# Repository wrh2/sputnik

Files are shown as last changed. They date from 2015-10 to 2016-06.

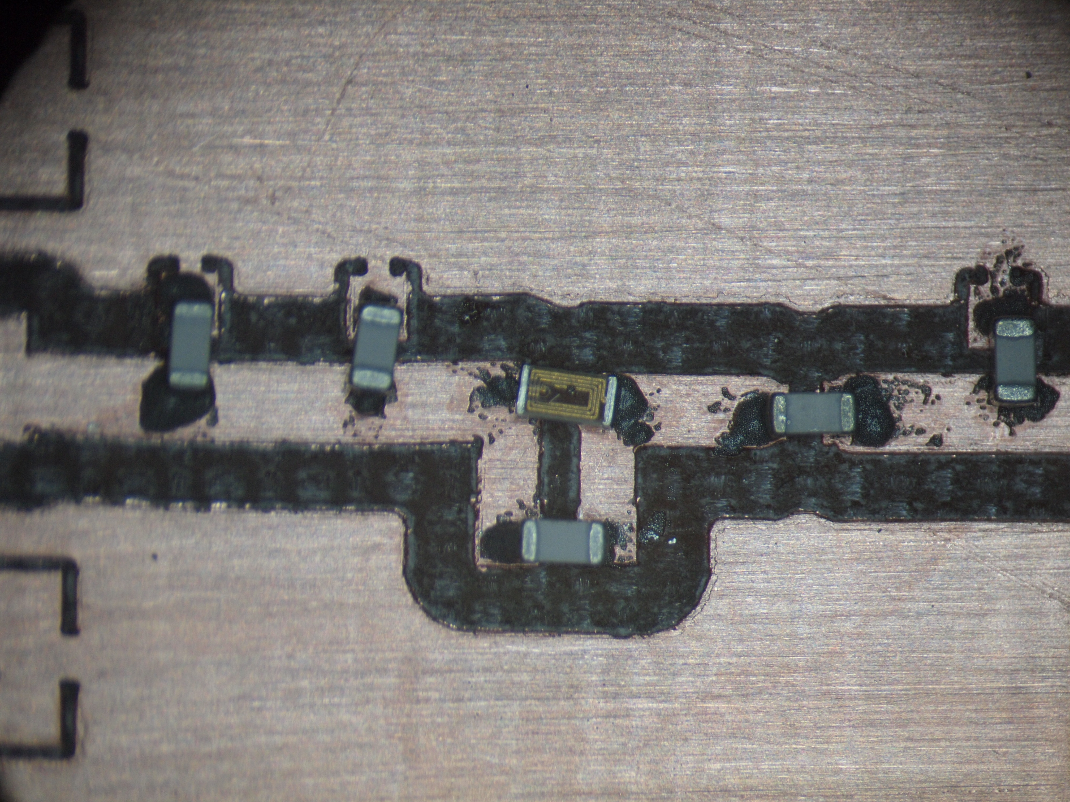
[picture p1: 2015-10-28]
RF_Materials/Antenna_Filters/prototype_photos/PA210078.JPG

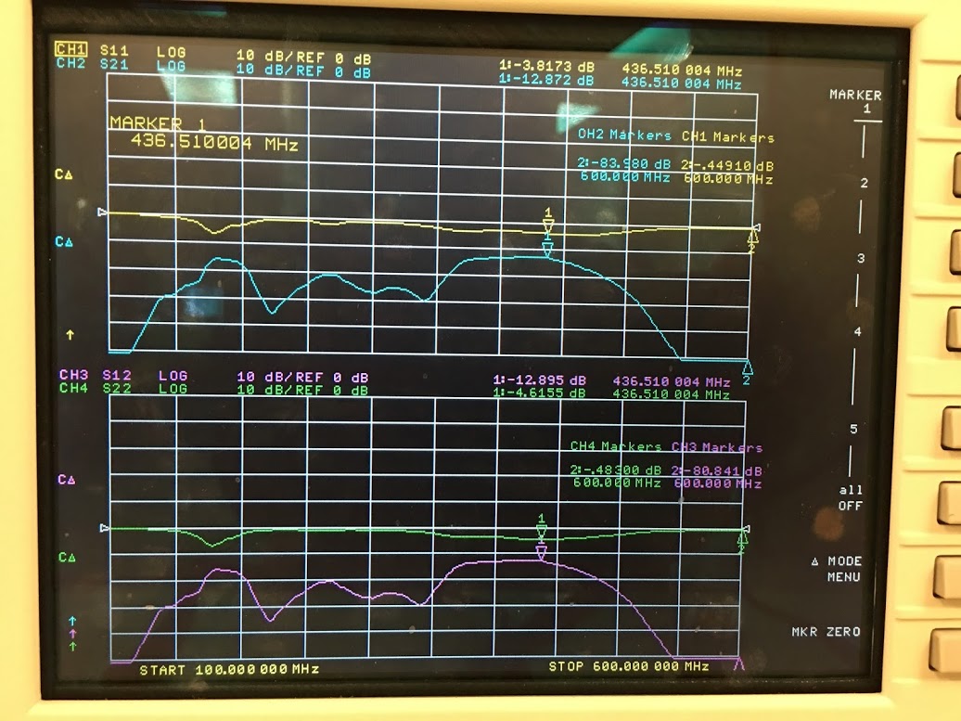
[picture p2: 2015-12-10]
RF_Materials/Antenna_Filters/AntennaTest.jpg

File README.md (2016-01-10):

# C3/Sputnik module

Project repo for Portland State Aerospace Society C3/Sputnik module project. Click [here] (https://github.com/wrh2/sputnik/wiki) for project details.

## Project Team
Jake Heath (jakeheath@gmail.com)

William Harrington (wrh2@pdx.edu)

Shan Quinney (quinney@pdx.edu)

Mike Mathis (mdmathis@gmail.com)

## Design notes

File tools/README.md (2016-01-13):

# Tools

This folder contains resources for the toolchain we are using for programming the Freescale/NXP MKW01Z128 microcontroller. For an in-depth explanation on the toolchain, [please see this wiki page](https://github.com/wrh2/sputnik/wiki/MKW01Z128-toolchain).

## Dependencies

[OpenOCD](http://openocd.org)

[GCC ARM Embedded](https://launchpad.net/gcc-arm-embedded)

## Contents

**Folders**
* drivers -- contains peripherial drivers that we've developed so far for the MKW01Z128
* examples -- contains some simple example code for using the microcontroller (MKW01Z128) on the breakout board
* toolchain -- contains linker script, config for OpenOCD

**Files**
* c3.c -- some really simple c code to inject into the microcontroller
* crt0.c -- stuff needed to initialize the MCU
* kw0x.h -- register definitions, needed for bit banging
* Makefile -- make utility for easy compiling

## Example usage

* To compile

        > make

* To compile and write to the flash on the MCU

        > make write

* To compile, write to the flash on the MCU, and start up a gdb session

        > make gdb

* To clean up

        > make clean

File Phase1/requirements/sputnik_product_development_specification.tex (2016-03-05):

\documentclass[12pt]{article}
\usepackage{amsmath}
\usepackage{amssymb}
\usepackage{graphicx}
\usepackage{tabulary}

\begin{document}

\title{Sputnik Product Development Specification}%replace X with the appropriate number
\author{William Harrington, Jake Heath, Shan Quinney, Michael Mathis\\ \\ %replace with your name
ECE412 Capstone} %if necessary, replace with your course title

\maketitle
 \small
\begin{description}
	\item[Requirements] \hfill \\ \\
		\textbf{Must}
		\begin{itemize}
			\item Environment
			\begin{itemize}
				\item Have a radiation tolerant watchdog system
				\item Be able to operate in an Industrial Operating Temperature Range (-40°C to 80°C)
				\item Acceleration: must handle 15g in the "Z" axis
			\end{itemize}
			\item Communication block ("radio")
			\begin{itemize}
				\item Operate in the 70 cm band (436 to 438 MHz)
				\begin{itemize}
					\item Use IARU specified frequency for RF comms and make appropriate changes if necessary
				\end{itemize}
				\item Meet FCC Amateur Radio Licensing requirements (Title 47 CFR part 97)
				\item Meet 400km ISS orbit link budget by a margin of 6 dB
				\item Have bidirectional communication interface to Payload and System Controller
				\item Local storage for communication in/out queues
			\end{itemize}
			\item Energy Switching/Control
			\begin{itemize}
				\item Be able to seamlessly switch energy sources to the load
			\end{itemize}
			\item System controller
			\begin{itemize}
				\item Radiation tolerant "system watchdog" controller
				\item Power switches to turn other blocks on and off
				\item Monitor energy storage and energy harvesting systems
				\item Communication link with communication block
			\end{itemize}
			\item CubeSat requirements
			\begin{itemize}
				\item Conforms to latest CubeSat specification where applicable
				\item Fits in 1/4 1U CubeSat
				\item Weighs less than 250 g
			\end{itemize}
		\end{itemize}
		\textbf{Should}
		\begin{itemize}
			\item{In general}
			\begin{itemize}
				\item Use as many COTS (Commercial Off The Shelf) parts as possible
			\end{itemize}
			\item Environment
			\begin{itemize}
				\item Operate in Automotive Operating Temperature Range (-40C to 125C)
			\end{itemize}
			\item Communication block ("radio")
			\begin{itemize}
				\item Use a frequency of 436.5 MHz for RF communication
			\end{itemize}
		\end{itemize}
	
		\textbf{May}
		\begin{itemize}
			\item Environment
			\begin{itemize}
				\item Operate in Military Operating Temperature Range (-55°C to 125°C)
			\end{itemize}
		\end{itemize}
	\newpage
	\item[Deliverables] \hfill \\
		\begin{itemize}
			\item Hardware
			\begin{itemize}
				\item 2 fully working Sputnik boards in the CubeSat 0 form factor (determined by PSAS)
				\item UART to Sputnik radio adapter for test/debug
			\end{itemize}
			\item Firmware
			\begin{itemize}
				\item Basic Sputnik functionality for KW0x microcontroller
				\item Drivers
				\begin{itemize}
					\item Timers and Interrupts
					\item SPI
					\item UART
					\item Radio (600 kbps bi-directional communication using GFSK)
				\end{itemize}
				\item System Controller
				\begin{itemize}
					\item Simple monitoring of power system
					\item Simple watchdog system to turn on and off other system blocks
				\end{itemize}
			\end{itemize}
			\item System Level
			\begin{itemize}
				\item Radio works: 600 kbps bi-directional communication, using GFSK demonstrated over 10 km
				\item System controller can turn other blocks on and off
			\end{itemize}
		\end{itemize}
\end{description}
\end{document}

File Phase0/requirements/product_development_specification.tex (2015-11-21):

\documentclass[12pt]{article}
\usepackage{amsmath}
\usepackage{amssymb}
\usepackage{graphicx}
\usepackage{tabulary}

\begin{document}

\title{Product Development Specification}%replace X with the appropriate number
\author{Team 05\\William Harrington, Jake Heath, Saroj Bardewa,\\ Shan Quinney, Michael Mathis\\ \\ %replace with your name
ECE411} %if necessary, replace with your course title

\maketitle
 \small
\begin{description}
	\item[Customer requirements] \hfill \\ \\
		The Portland State Aerospace Society (PSAS) needs a device that can be used for command, control, communications between a \textbf{CubeSat} and a \textbf{ground station}.
		A \textbf{CubeSat} is a miniature satellite that can be used for scientific research in space. It has a volume of one liter (10cm cube), and has a mass of no more than 1.33kg.
		A \textbf{ground station} is a radio station located on earth that is designed for communication with spacecraft.
		Development of such a device is not trivial as it will need to eventually be "space ready" (for example being able to operate in -30C to 150C temperature ranges and withstand ionizing radiation from space environment)  and will require multiple phases of development. \hfill \\ \\
		The first phase of development will involve finding and de-risking a microcontroller that is capable of handling command, control, and communications.
		Therefore, the device will be a communications module "breakout board" that will allow easy access to the features of the microcontroller like UART, I2C, SPI, GPIO, ADCs/DACs, etc. Access to these features will rely on miscellaneous connectors such as .1 inch pin headers, USB, 6-pin JTAG, etc. Furthermore, as a project that is sponsored by PSAS it should adhere to their open source standards, while obeying governmental regulations.
		\hfill \\ \\
		\newpage
	\item[Requirements] \hfill \\
		\textbf{Must}
		\begin{itemize}
			\item{Have a transceiver for RF communications}
      			\item{Have an antenna capable of 435 - 438MHz frequency band transmission}
			\item{Have visible indication of communication \textit{(such as LEDs)}}
			\item{Have a bidirectional amplifier for RF communication}
			\item{Be able to fit within the CubeSat form factor\\ \textit{(no bigger than 10cm x 10cm x 10cm)}}
			\item{Be a breakout board}
			\item{Have access to UART}
			\item{Have access to I2C}
			\item{Have access to SPI}
			\item{Have access to GPIO}
			\item{Have access to ADCs/DACs}
		\end{itemize}
		\textbf{Should}
		\begin{itemize}
			\item{Use USB for interfacing}
			\item{Be able to send/receive data packets via RF communication}
			\item{Be capable of RF communication at a distances greater than 6 feet}
			\item{Be battery powered (as opposed to using lab power supplies) }
			\item{If battery powered, utilize USB for recharging}
			\item{Comply with European Telecommunications Standard Institute(ETSI) and Federal Communications Commission (FCC) regulatory requirements}
			\item{Use a GNU GPL v3 license for all design work and software} 
		\end{itemize}
		\textbf{May}
		\begin{itemize}
			\item{Be capable of long distance communication \textit{(250m-500m for example)}}
			\item{Be capable of sending/receiving data packets}
			\item{Be capable of operation in space temperature range \textit{(-30C to 60C )}}
			\item{Comply with Federal Aviation Administration (FAA) regulatory requirements}
		\end{itemize}
\end{description}

\end{document}

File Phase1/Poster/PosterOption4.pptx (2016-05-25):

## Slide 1

CubeSat Command Control and
Communications System

Introduction

Project Team:
Will Harrington
Jake Heath
Michael Mathis
Shan Quinney

Special Thanks to:
Andrew Greenberg Theo
Glenn Dr. Teuscher
PSAS The LID

Development

Development of the Sputnik project began last year during our practicum. We created a specialized breakout board for the microcontroller with the integrated radio. Having this initial board allowed the firmware team to begin work earlier. We were also able to de-risk some of the components that we used in the final product.
Part of that de-risking process was creating proto-boards. These are small and specific boards built for the sole purpose of testing the major sub-systems of Sputnik. The proto-boards were custom made and tested in the Laboratory for Interconnected Devices (LID) by the hardware team.
One of the most time consuming tasks the hardware team faced was part selection because hey had to find parts that had equivalent radiation hardened counter parts

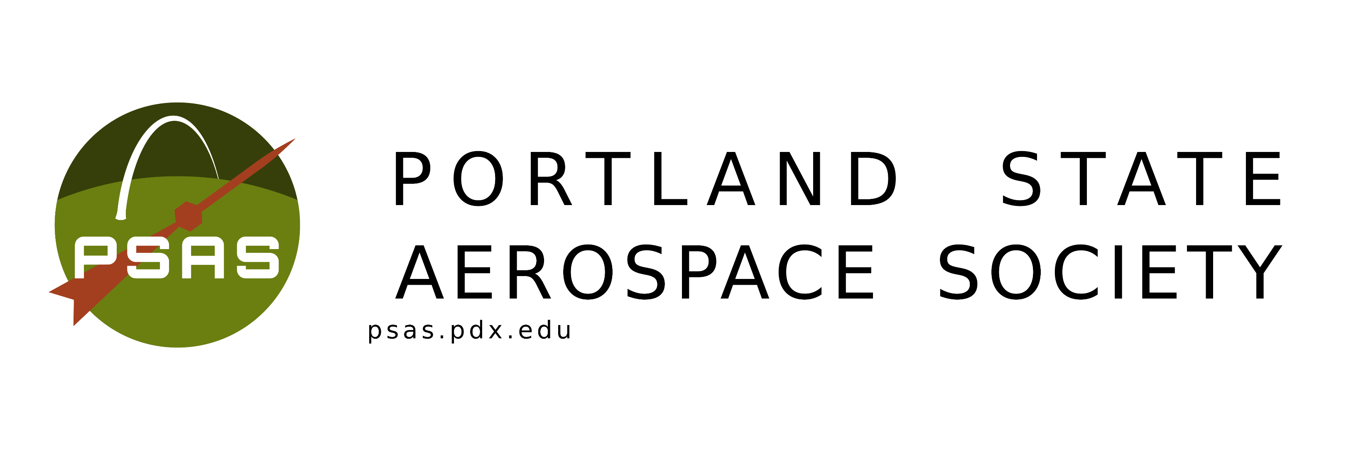
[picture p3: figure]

Results

In the end we were able to produce working prototypes that have been tested to our sponsor’s specifications and we provided our sponsor with the documentation necessary to bring future Sputnik teams up to speed.
Our final boards contained a total of 180 individual components, 108 for the LGR and 72 for SysCon.
10km TEST RESULTS
QUOTE FROM ANDREW ABOUT HOW AWESOME WE ARE MAYBE

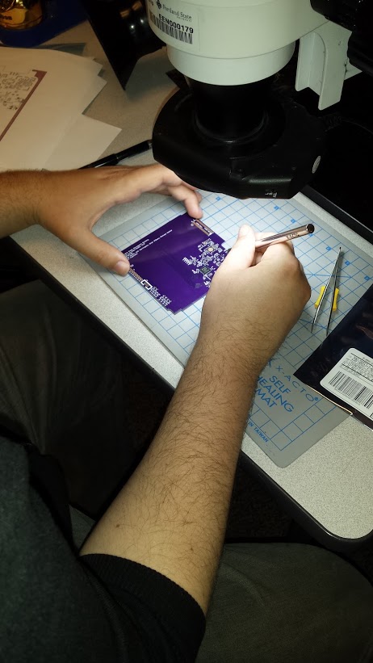
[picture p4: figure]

Jake Heath working on an LGR module

Design

The Sputnik project is composed of two separate modules: the low-gain radio module (LGR) and the system control module (SysCon). The radio module is home to a microcontroller with an integrated radio transceiver. The system controller module will house a radiation hardened watchdog microcontroller that can reboot the payload and the radio module after a radiation event causes components to fail. The prototype we are making will use off-the-shelf parts that have radiation hardened analogues so that when the time comes to build the final boards the off-the-shelf parts can be swapped out for the more robust components. This saves money during this early development stage

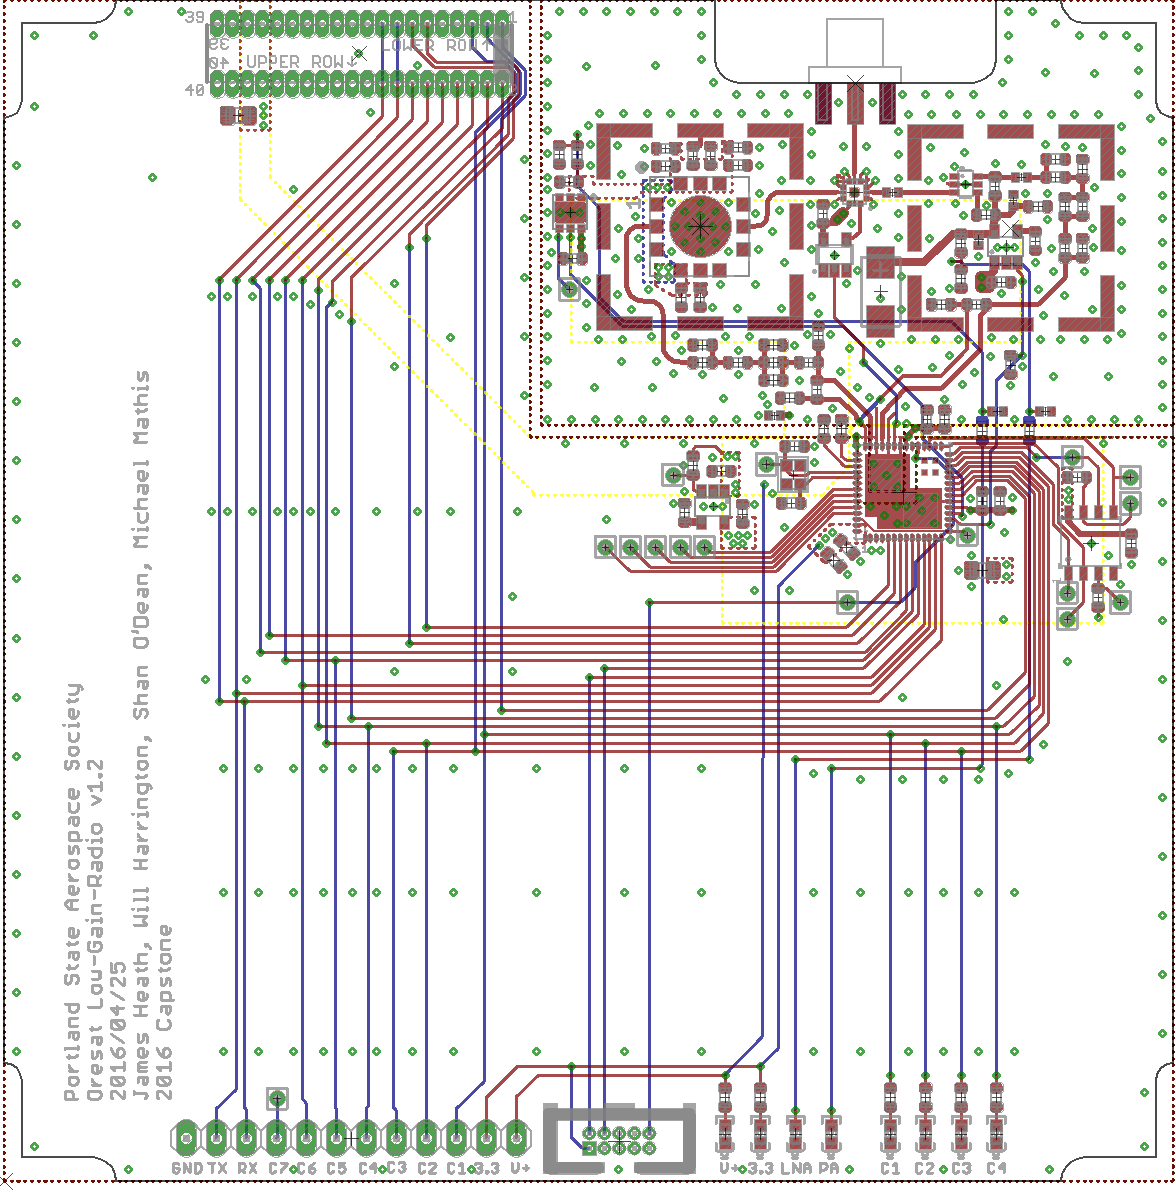
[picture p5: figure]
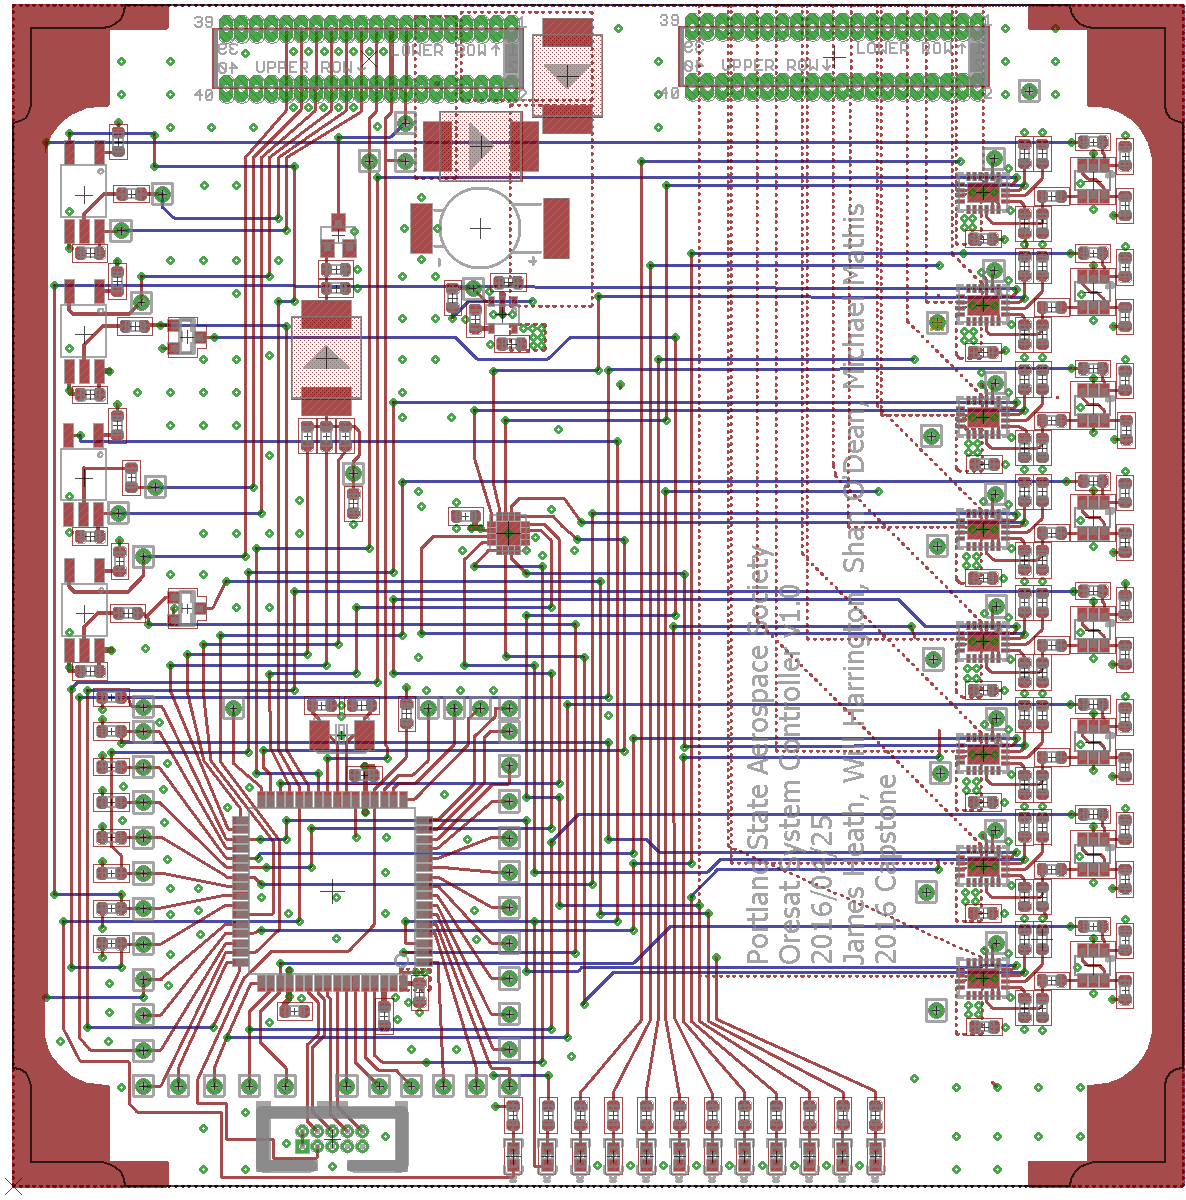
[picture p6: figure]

The final board layouts for the LGR (left) and the SysCon (right)

Spectrum analyzer
screenshot

Picture of us doing
the 10km test

Graph showing SOMETHING HARDWARY (left)
Picture of MEMBERS OF TEAM performing a 10km communications test (right)

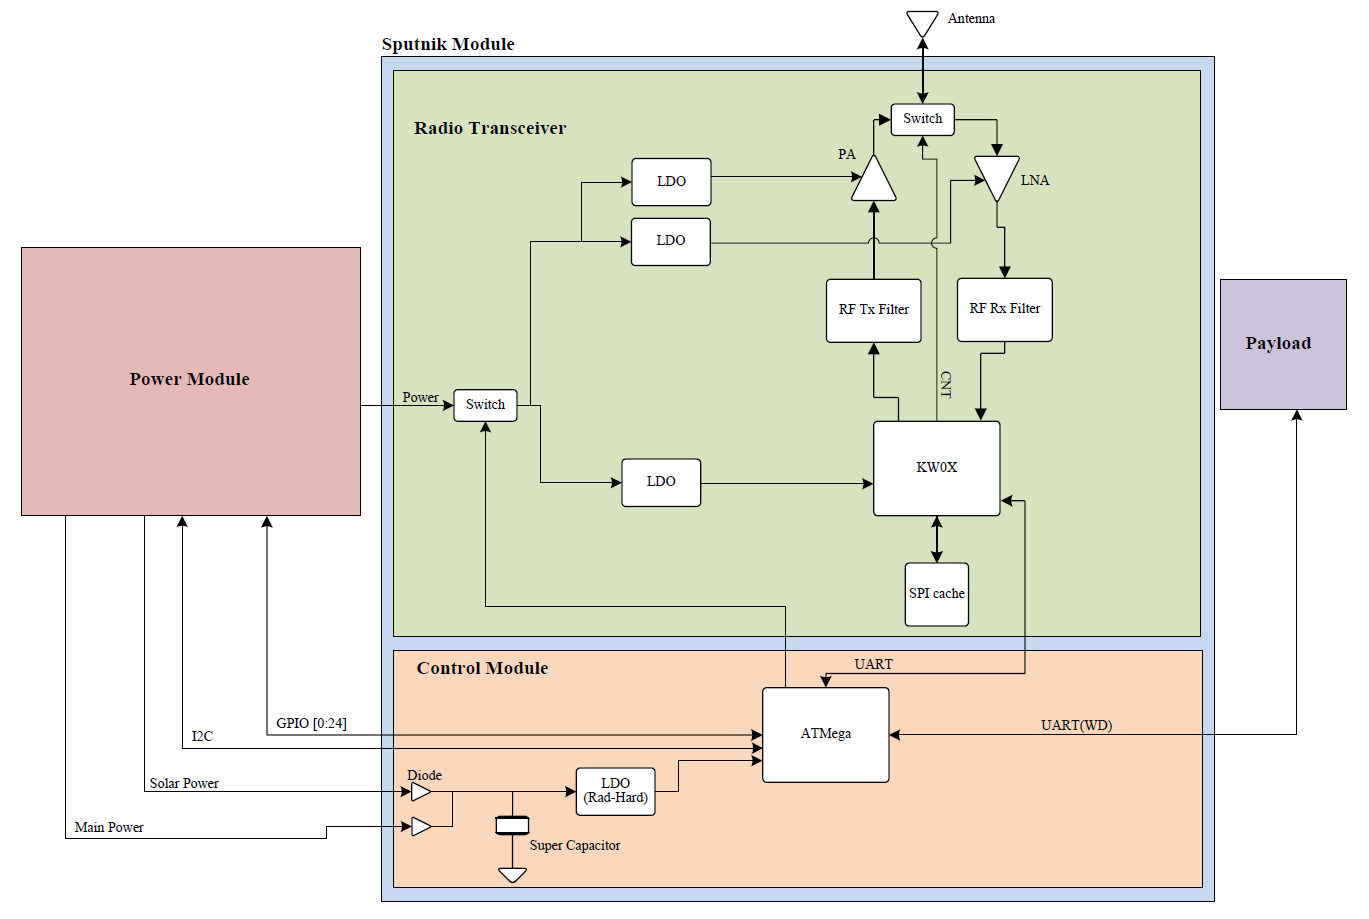
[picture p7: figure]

Block diagram of the Sputnik project

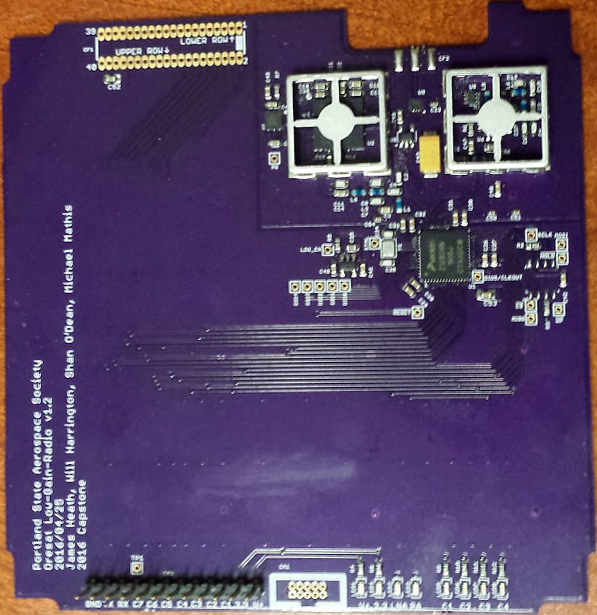
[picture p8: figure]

Firmware started with building up a complete toolchain that could be used for bare metal programming. Another challenge that firmware faced was that the integrated radio module is connected to the LGR microcontroller through a SPI interface even though they are both on the same IC. Furthermore, the microcontroller receives its main clock signal from the transceiver. This means that to get the microcontroller to work, it needed to start up with an internal oscillator then instruct the transceiver to output the appropriate clock signal and then change the clock source of the microcontroller to the transceiver.
PSAS wanted a basic code base that future contributors could use to get up and running on the project as quickly as possible so user-friendliness and good documentation were key in our development.

Department of Electrical and Computer Engineering

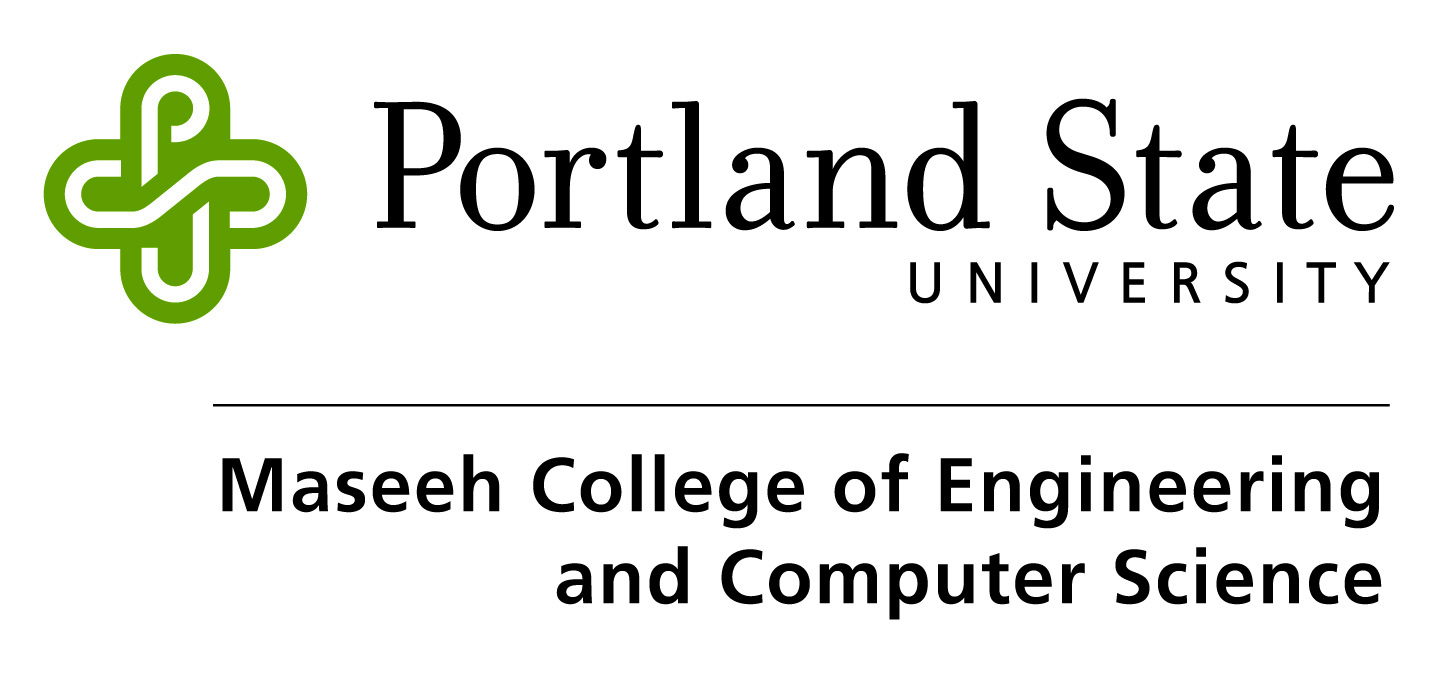
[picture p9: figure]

Pictures of the finished boards LGR (left) and SysCon (right)

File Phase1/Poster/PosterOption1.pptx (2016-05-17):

## CubeSat Command Control and Communications System

Introduction

Small educational satellites called CubeSats have been launched by dozens of universities and countries around the world, but so far Oregon has yet to join the elite club of states that have flown a home-grown CubeSat in space. The Portland State Aerospace Society (PSAS) would like to change that! PSAS has included several other Oregon schools in the ORESAT project to build a CubeSat and send it into orbit. Two NASA programs make that possible, the NASA CubeSat Launch Initiative and NASA’s Educational Launch of Nanosatellites program.
PSAS needed a command, control, and communications system for the CubeSat project. The project was fondly nicknamed Sputnik because it doesn’t have sensors, but has a radio. Sputnik will eventually be responsible for communications to and from a 400km low earth orbit. It will retrieve scientific data from the CubeSat’s payload of sensor modules and send the data back to earth. Sputnik will also relay commands like “Take a picture” or “Turn around”. In space it will need to be able to deal with a temperature range of -40C to 85C and radiation events that could cause components to latch up and cause shorts.

Project Team:
Will Harrington
Jake Heath
Michael Mathis
Shan Quinney

Special thanks to:
Andrew Greenberg
Theo
Glenn
Dr. Teuscher
PSAS
The LID


Results

In the end we were able to produce working prototypes that have been tested to our sponsor’s specifications and we provided our sponsor with the documentation necessary to bring future Sputnik teams up to speed.
Our final boards contained a total of 180 individual components, 108 for the LGR and 72 for SysCon.
10km TEST RESULTS
QUOTE FROM ANDREW ABOUT HOW AWESOME WE ARE MAYBE

Development

Development of the Sputnik project began last year during our practicum. We created a specialized breakout board for the microcontroller with the integrated radio. Having this initial board allowed the firmware team to begin work earlier. We were also able to de-risk some of the components that we used in the final product.
Part of that de-risking process was creating proto-boards. These are small and specific boards built for the sole purpose of testing the major sub-systems of Sputnik. The proto-boards were custom made and tested in the Laboratory for Interconnected Devices (LID) by the hardware team.
One of the most time consuming tasks the hardware team faced was part selection because hey had to find parts that had equivalent radiation hardened counter parts


Jake Heath working on an LGR module

Design

The Sputnik project is composed of two separate modules: the low-gain radio module (LGR) and the system control module (SysCon). The radio module is home to a microcontroller with an integrated radio transceiver. The system controller module will house a radiation hardened watchdog microcontroller that can reboot the payload and the radio module after a radiation event causes components to fail. The prototype we are making will use off-the-shelf parts that have radiation hardened analogues so that when the time comes to build the final boards the off-the-shelf parts can be swapped out for the more robust components. This saves money during this early development stage


The final board layouts for the LGR (left) and the SysCon (right)

Spectrum analyzer
screenshot

Picture of us doing
the 10km test

Graph showing SOMETHING HARDWARY (left)
Picture of MEMBERS OF TEAM performing a 10km communications test (right)


Block diagram of the Sputnik project


Firmware started with building up a complete toolchain that could be used for bare metal programming. Another challenge that firmware faced was that the integrated radio module is connected to the LGR microcontroller through a SPI interface even though they are both on the same IC. Furthermore, the microcontroller receives its main clock signal from the transceiver. This means that to get the microcontroller to work, it needed to start up with an internal oscillator then instruct the transceiver to output the appropriate clock signal and then change the clock source of the microcontroller to the transceiver.
PSAS wanted a basic code base that future contributors could use to get up and running on the project as quickly as possible so user-friendliness and good documentation were key in our development.

Department of Electrical and Computer Engineering


Pictures of the finished boards LGR (left) and SysCon (right)

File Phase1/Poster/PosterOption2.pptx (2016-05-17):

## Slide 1

CubeSat Command Control and
Communications System

Introduction

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

Project Team:
Will Harrington
Jake Heath
Michael Mathis
Shan Quinney

Special Thanks to:
Andrew Greenberg Theo
Glenn Dr. Teuscher
PSAS The LID

Development

PSAS wanted a basic code base that future contributors could use to get up and running on the project as quickly as possible so user-friendliness and good documentation were key.
Development of the Sputnik project began last year during our practicum. We created a specialized breakout board for the microcontroller with the integrated radio. Having this initial board allowed the firmware team to begin work earlier. We were also able to de-risk some of the components that we used in the final product.


The firmware team programmed Sputnik to check for errors caused by radiation or bugs. The LGR module sends an “I’m alive” signal to the SysCon periodically. If the SysCon doesn’t receive the signal in time, it performs a reset on the LGR. The SysCon module will also listen in via i2c to the payload and to the power system and reset those systems as needed.
They also wrote drivers for the essential peripherals of the microcontrollers and programmed the tricky configuration of the LGR’s microcontroller and transceiver.

Results

In the end we were able to produce working prototypes that have been tested to our sponsor’s specifications and we provided our sponsor with the documentation necessary to bring future Sputnik teams up to speed on the project.
Our final boards contained a total of 180 individual components, 108 for the LGR and 72 for SysCon.
10km TEST RESULTS
QUOTE FROM ANDREW ABOUT HOW AWESOME WE ARE MAYBE

The final board layouts for the LGR (left) and the SysCon (right)


The hardware team also spent extra time researching part because hey had to find components that had equivalent radiation hardened counter parts.
Part of that de-risking process was creating proto-boards. These are small and specific boards built for the sole purpose of testing the major sub-systems of Sputnik. The proto-boards were custom made and tested in the Laboratory for Interconnected Devices (LID) by the hardware team.

UPDATE WITH HOW THE BUILDING OF THE BOARDS GOES

Design

The Sputnik project is composed of two separate modules: the low-gain radio module (LGR) and the system control module (SysCon). The LGR module is home to a microcontroller with an integrated radio transceiver. The system controller module will house a radiation hardened watchdog microcontroller that can reboot the payload and the radio module after a radiation event or other error causes systems to fail.
The prototype we are making will use off-the-shelf parts that have radiation hardened analogues so that when the time comes to build the final boards the off-the-shelf parts can be swapped out for the more robust components. This saves money during this early development stage

Spectrum analyzer
screenshot


Picture of us doing
the 10km test


Block diagram of the Sputnik project

Graph showing SOMETHING HARDWARY (left)
Picture of MEMBERS OF TEAM performing a 10km communications test (right)


Jake Heath works on an LGR module

Department of Electrical and Computer Engineering


Pictures of the finished boards LGR (left) and SysCon (right)

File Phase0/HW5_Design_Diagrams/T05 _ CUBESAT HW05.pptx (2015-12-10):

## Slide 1

CubeSat C3 Unit Level 0

Power

On/Off

CubeSat C3 Unit

!Reset

Module | Power Management
Input | Power: USB or Battery On/Off: Enables and Disables the Voltage Regulator !Reset: Reset Button
Bi-Directional (Input-Output) | Antenna: Radio Antenna with 436.5MHz passband Peripherals: At discretion of user, breakout pins Debug: Debug with JTAG
Functionality | This module is a subsystem of a larger satellite CubeSat system. The main function of this subsystem is to receive and transmit high frequency data signal using Wi-Fi protocol. At the heart of this module is a microcontroller that takes commands via USB, GPIO, and JTAG configurations and uses radio frequency to communicate messages from and to another similar module.

Antenna

Debug

Peripherals

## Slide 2

CubeSat C3 Unit Level 1

Power Manage-
ment System

USB2UART

USB

MCU

RF Filter

Antenna

!Reset

Peripherals

Battery

Debug

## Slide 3

Level 1 Breakdown

USB Power

Power
Management

Vout
3.3V

USB

USB2UART

UART0

Module | Power Management
Input | USB Power : 4.5~5.5V DC
Output | Vout: Outputs 3.3 V DC
Bidirectional (Input –Output) | Battery: 3.9V 1000mAH
Functionality | The function of this unit is to manage the power system. It is powered through USB connection. It consists of voltage regulator and a battery pack that stores voltage and outputs constant 3.3V.

Module | USB2UART
Bidirectional (Input –Output) | USB : USB connection (D+ and D- lines) UART0: RX and TX lines to MCU UART0 pin
Functionality | This unit consists of USB-to-UART Bridge controller that converts USB signals to RS-232 and vice-versa.

Battery

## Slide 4

Level 1 Breakdown

RFIO
436.5 MHz

RF Front End

Antenna

Module | RF Filter
Bidirectional (Input –Output) Output | RFIO: 0-13dB power signals at 436.5 MHz Antenna: Signal goes through antenna
Functionality | The main purpose of this module is to receive and transfer radio signals at a passband frequency of 436.5 Hz.

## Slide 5

Level 1 Breakdown

Power Management System

!Reset

UART0

MCU

Peripherals

Debug

RFIO

Module | MCU
Input | Power Management System !Reset: Reset button
Bi-directional (Input-Output) | Peripherals: Connection to peripherals which are at users discretion Debug: Connection to 10-pin JTAG interface RFIO: Radio input-output channel at 436.5 MHz passband UART0: Rx and Tx lines for UART0 port on MCU
Functionality | This is the main microcontroller unit in the system. It uses a real-time operating system.It has a resonator connected to it that clocks at 32MHz. This unit monitors radio signals, as well as provides multiple interfaces , for eg.GPIO, JTAG, SPI, I2C etc., to transmit and receive data.

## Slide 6

UML Activity View of CubeSat C3 Unit

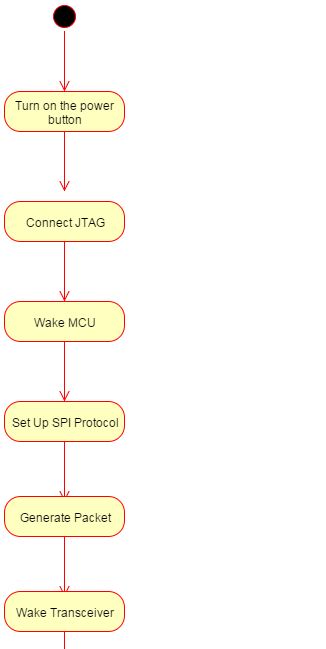
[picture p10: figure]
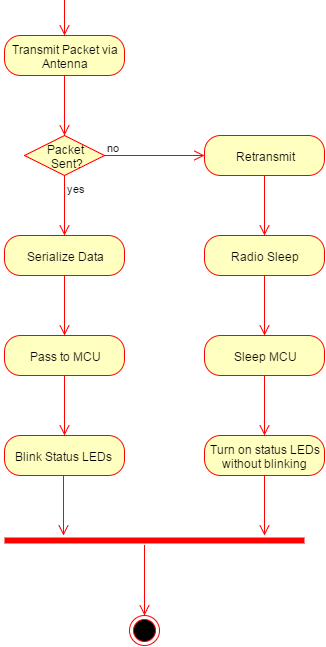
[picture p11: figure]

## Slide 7

UML Sequence Diagram View of CubeSat C3 Unit

User 1

CubeSat C3
Unit1

CubeSat C3
Unit 2

User 2

Blink Status
LEDS twice
(Packet Received)

Event Trigger
(SPI protocol)

Solid Status LEDs
(Transmit Failed)

Blink Status LEDs(
Transmit Success)

Transmit Packet
(via Antenna)

Confirmation Packet
(via Antenna)

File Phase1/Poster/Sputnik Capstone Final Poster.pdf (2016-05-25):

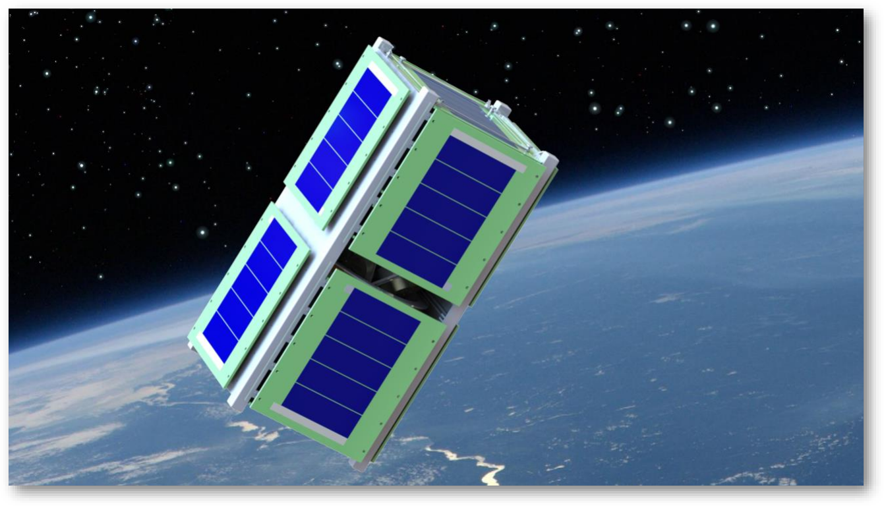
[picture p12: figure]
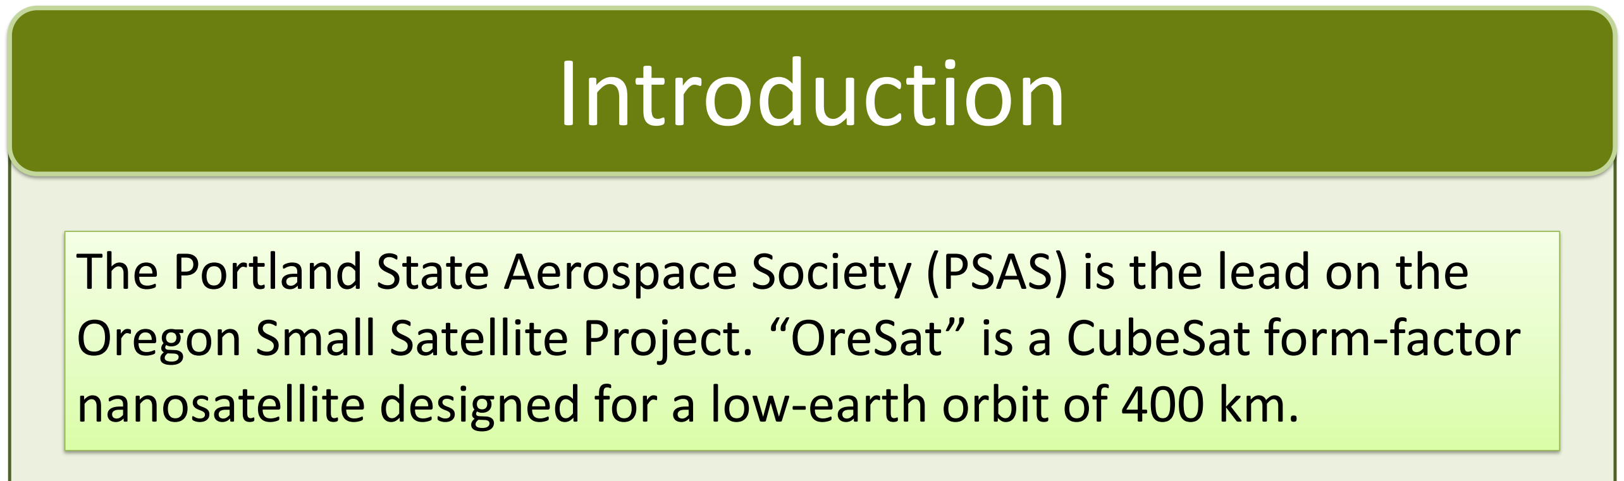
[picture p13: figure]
Introduction
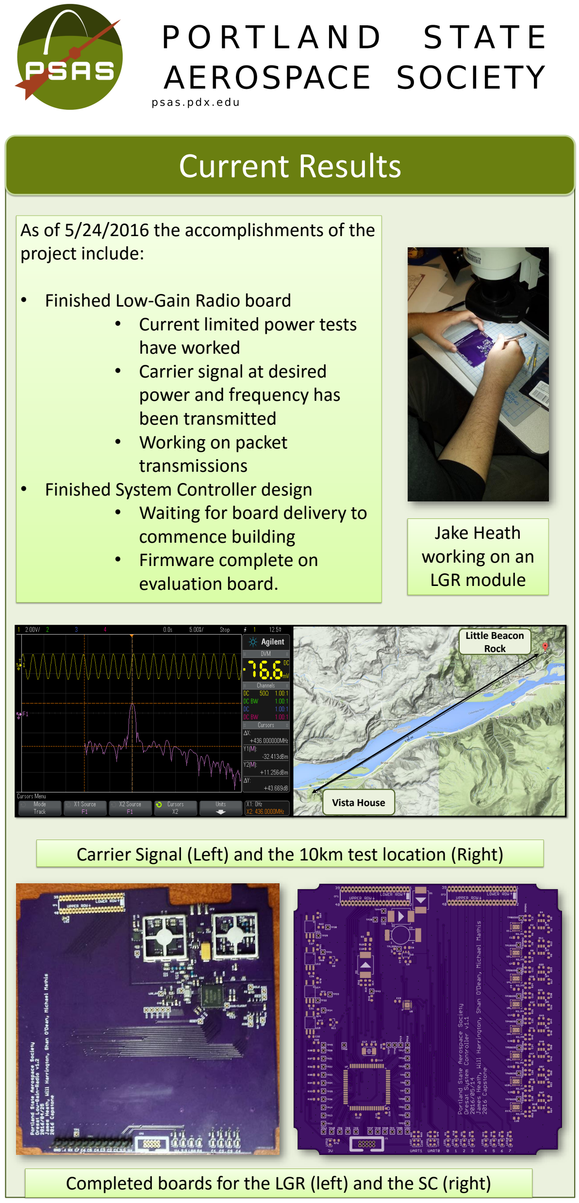
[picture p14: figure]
project include:; • Finished Low-Gain Radio board • Current limited power tests have worked • Carrier signal at desired power and frequency has been transmitted • Working on packet transmissions • Finished System Controller design • Waiting for board delivery to commence building • Firmware complete on evaluation board.; Current Results; Jake Heath working on an LGR module; Little Beacon Rock; Vista House

As of 5/24/2016 the accomplishments of the

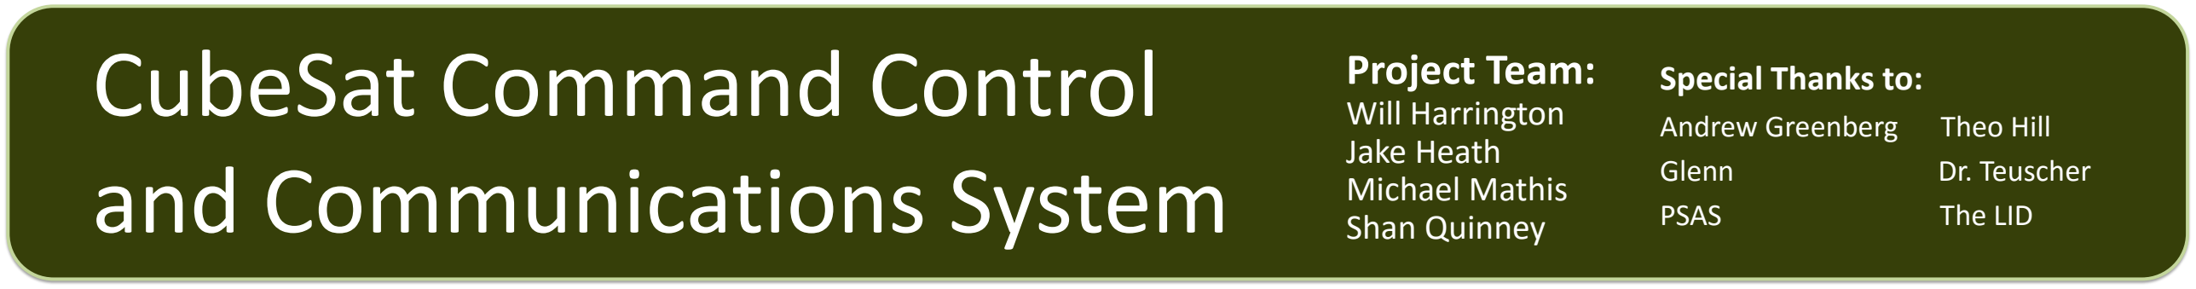
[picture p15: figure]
Project Team: Will Harrington Jake Heath Michael Mathis Shan Quinney; Special Thanks to:; Andrew Greenberg; Theo Hill; Glenn; Dr. Teuscher; PSAS; The LID; CubeSat Command Control and Communications System
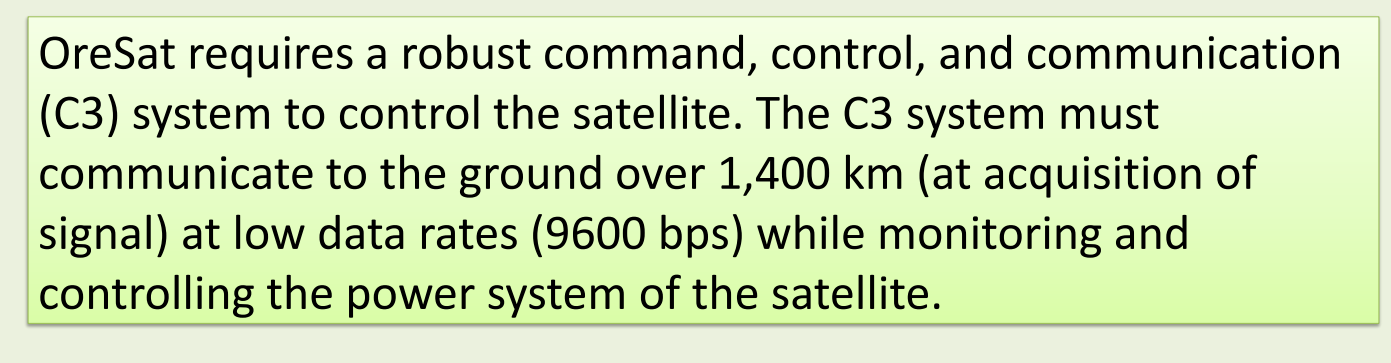
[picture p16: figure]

# Department of Electrical and Computer Engineering

Pictures of the finished boards LGR (left) and SysCon (right)

# Design

The Portland State Aerospace Society (PSAS) is the lead on the Oregon Small Satellite Project. “OreSat” is a CubeSat form-factor nanosatellite designed for a low-earth orbit of 400 km.

OreSat requires a robust command, control, and communication (C3) system to control the satellite. The C3 system must communicate to the ground over 1,400 km (at acquisition of signal) at low data rates (9600 bps) while monitoring and controlling the power system of the satellite.

Completed boards for the LGR (left) and the SC (right)

Carrier Signal (Left) and the 10km test location (Right)

Our design is only two of the many modules in OreSat. The LGR is used for communication with the Cubesat, supplying 1 Watt of transmission power to cover the long distance. The System Controller, which will be accessible from the ground station via the LGR, will inform the ground crew in the case of radiation latch-up and can restart the whole satellite if necessary.

We split our design into two parts, the Low-Gain Radio (LGR) which handles communication and the System Controller (SC) which is in charge of command and control for the module

The boards need
to be cut in order
to fit properly.

The layout of the
LGR (left) and the
SC (right)

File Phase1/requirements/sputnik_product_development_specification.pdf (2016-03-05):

# Sputnik Product Development Specification

## William Harrington, Jake Heath, Shan Quinney, Michael Mathis

## ECE412 Capstone

## March 4, 2016

Requirements

Must

- Environment

– Have a radiation tolerant watchdog system
– Be able to operate in an Industrial Operating Temperature Range (-40C to 80C)
– Acceleration: must handle 15g in the ”Z” axis
- Communication block (”radio”)

– Operate in the 70 cm band (436 to 438 MHz)
∗ Use IARU specified frequency for RF comms and make appropriate changes if necessary
– Meet FCC Amateur Radio Licensing requirements (Title 47 CFR part 97)
– Meet 400km ISS orbit link budget by a margin of 6 dB
– Have bidirectional communication interface to Payload and System Controller
– Local storage for communication in/out queues
- Energy Switching/Control

– Be able to seamlessly switch energy sources to the load

- System controller

– Radiation tolerant ”system watchdog” controller

1

– Power switches to turn other blocks on and off
– Monitor energy storage and energy harvesting systems – Communication link with communication block
- CubeSat requirements

– Conforms to latest CubeSat specification where applicable – Fits in 1/4 1U CubeSat

– Weighs less than 250 g

Should

- In general

– Use as many COTS (Commercial Off The Shelf) parts as possible

- Environment

– Operate in Automotive Operating Temperature Range (-40C to 125C)

- Communication block (”radio”)

– Use a frequency of 436.5 MHz for RF communication

May

- Environment

– Operate in Military Operating Temperature Range (-55C to 125C)

2

Deliverables

- Hardware

– 2 fully working Sputnik boards in the CubeSat 0 form factor (determined by PSAS)
– UART to Sputnik radio adapter for test/debug
- Firmware

– Basic Sputnik functionality for KW0x microcontroller – Drivers
∗ Timers and Interrupts
∗ SPI
∗ UART
∗ Radio (600 kbps bi-directional communication using GFSK) – System Controller
∗ Simple monitoring of power system
∗ Simple watchdog system to turn on and off other system blocks
- System Level

– Radio works: 600 kbps bi-directional communication, using GFSK demonstrated over 10 km
– System controller can turn other blocks on and off

3

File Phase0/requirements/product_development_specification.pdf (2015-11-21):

# Product Development Specification

## Team 05

William Harrington, Jake Heath, Saroj Bardewa,

## Shan Quinney, Michael Mathis

## ECE411

## November 21, 2015

Customer requirements

The Portland State Aerospace Society (PSAS) needs a device that can be used for command, control, communications between a CubeSat and a ground station. A CubeSat is a miniature satellite that can be used for scientific research in space. It has a volume of one liter (10cm cube), and has a mass of no more than 1.33kg. A ground station is a radio station located on earth that is designed for communication with spacecraft. Development of such a device is not trivial as it will need to eventually be ”space ready” (for example being able to operate in -30C to 150C temperature ranges and withstand ionizing radiation from space environment) and will require multiple phases of development.

The first phase of development will involve finding and de-risking a microcontroller that is capable of handling command, control, and communications. Therefore, the device will be a communications module ”breakout board” that will allow easy access to the features of the microcontroller like UART, I2C, SPI, GPIO, ADCs/DACs, etc. Access to these features will rely on miscellaneous connectors such as .1 inch pin headers, USB, 6-pin JTAG, etc. Furthermore, as a project that is sponsored by PSAS it should adhere to their open source standards, while obeying governmental regulations.

1

Requirements
Must
- Have a transceiver for RF communications
- Have an antenna capable of 435 - 438MHz frequency band transmission
- Have visible indication of communication (such as LEDs)
- Have a bidirectional amplifier for RF communication
- Be able to fit within the CubeSat form factor
(no bigger than 10cm x 10cm x 10cm)
- Be a breakout board
- Have access to UART
- Have access to I2C
- Have access to SPI
- Have access to GPIO
- Have access to ADCs/DACs

Should

- Use USB for interfacing
- Be able to send/receive data packets via RF communication
- Be capable of RF communication at a distances greater than 6 feet
- Be battery powered (as opposed to using lab power supplies)
- If battery powered, utilize USB for recharging
- Comply with European Telecommunications Standard Institute(ETSI) and Federal Communications Commission (FCC) regulatory requirements
- Use a GNU GPL v3 license for all design work and software

May

- Be capable of long distance communication (250m-500m for example)
- Be capable of sending/receiving data packets
- Be capable of operation in space temperature range (-30C to 60C )
- Comply with Federal Aviation Administration (FAA) regulatory requirements

2

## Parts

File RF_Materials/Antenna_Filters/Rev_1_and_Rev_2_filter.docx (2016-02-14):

Front End Filter Design

Part of our practicum project involves the front-end design for the CubeSat transceiver. This includes the RF filter(s), external signal amplification, and system antenna. Here, we are looking at the filter topography that is recommended by freescale, the maker of the transceiver we use.

There are two possible modes of operation for the transceiver:

1) Single bidirectional port

a) This requires a single antenna, a single filter, and an optional power amplifier. The MKW01Z128 is fabricated with an internal PA that is capable of outputting up to 17dBm.

b) The low pass filter provided in the documentation appears to operate fine as a bidirectional filter.

2) Dual port

a) Both the receiver and the transmitter will have an independent path to the antenna. This leaves the option to include an external PA for the transmitter and a LNA for the receiver.

b) An external switch is required to switch the antenna between the receiver and transmitter.

LTSPICE simulations, build, and test Rev.1

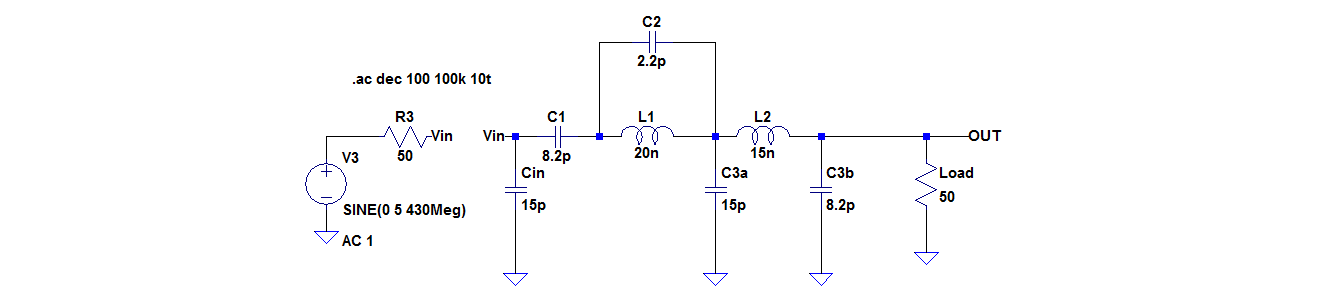
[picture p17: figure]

Figure 1: LTSPICE schematic of initial filter design

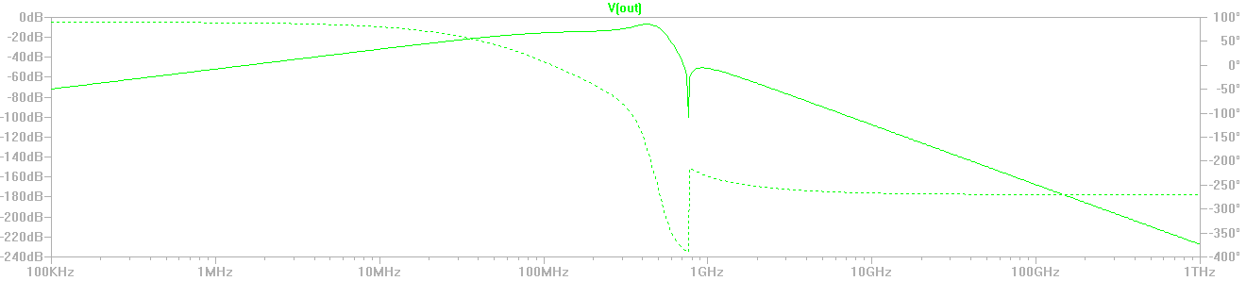
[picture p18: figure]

Figure 2: LTSPICE S21 response of filter of broad frequency range.

Rev. 1 Eagle schematic and board layout

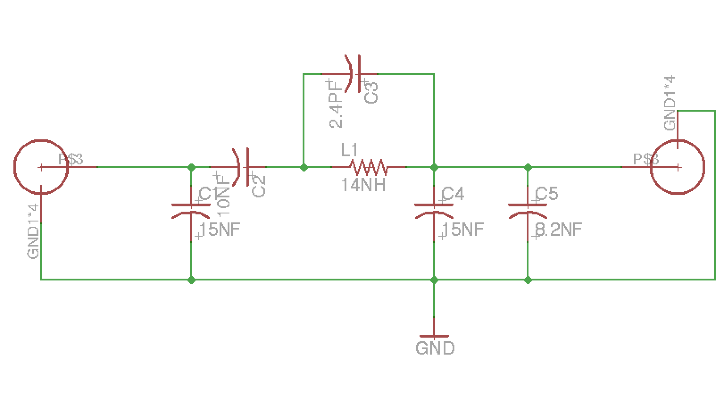
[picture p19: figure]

Figure 3: Rev.1 Eagle Schematic

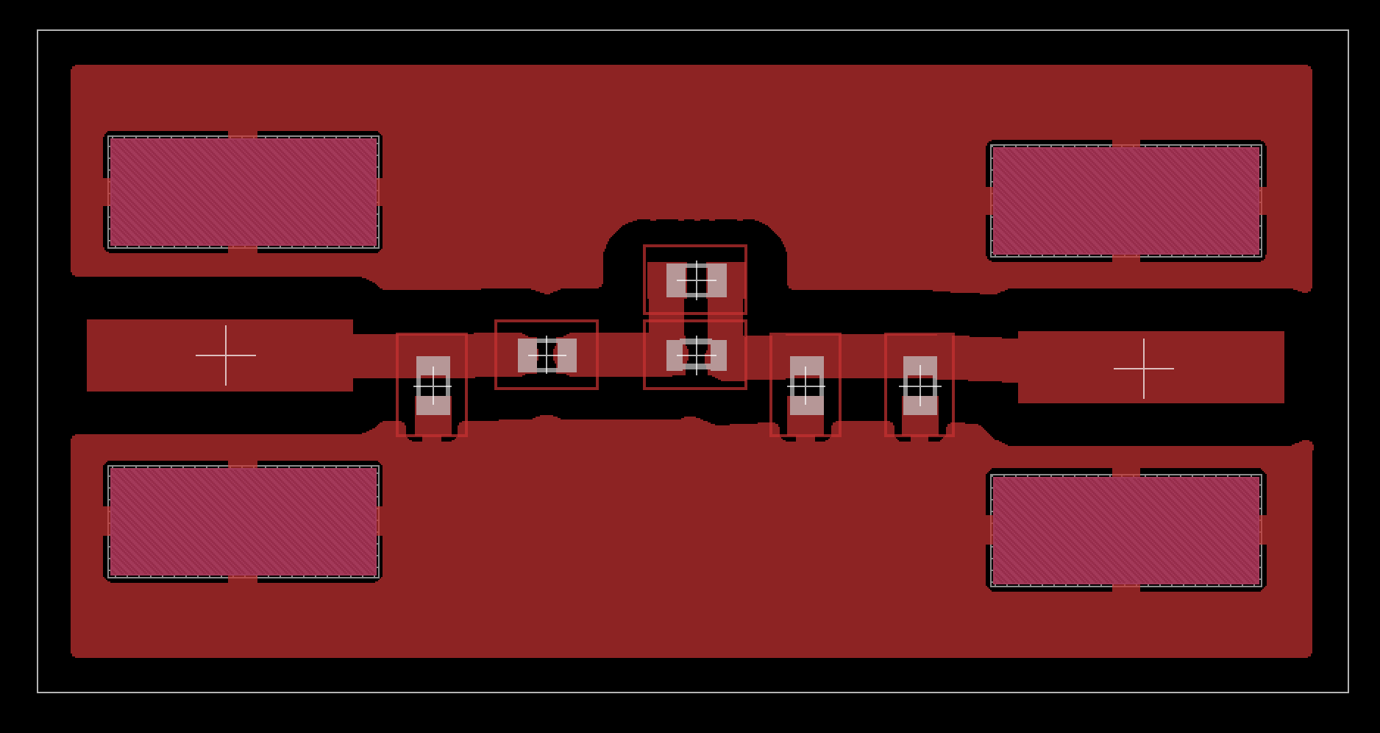
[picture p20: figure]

Figure 4: Rev.1 Eagle Board Layout

LTSPICE simulations Rev.2

This filter design does not have the high gain in the pass band of the rev 1 design, but the high gain was due to improper impedance matching of the filter to the source. It is believed that this filter response is closer to what the designers of the dev board filter intended. It still has a good bidirectional response and is capable of attenuating the second harmonic of the input signal by greater than 40dB.

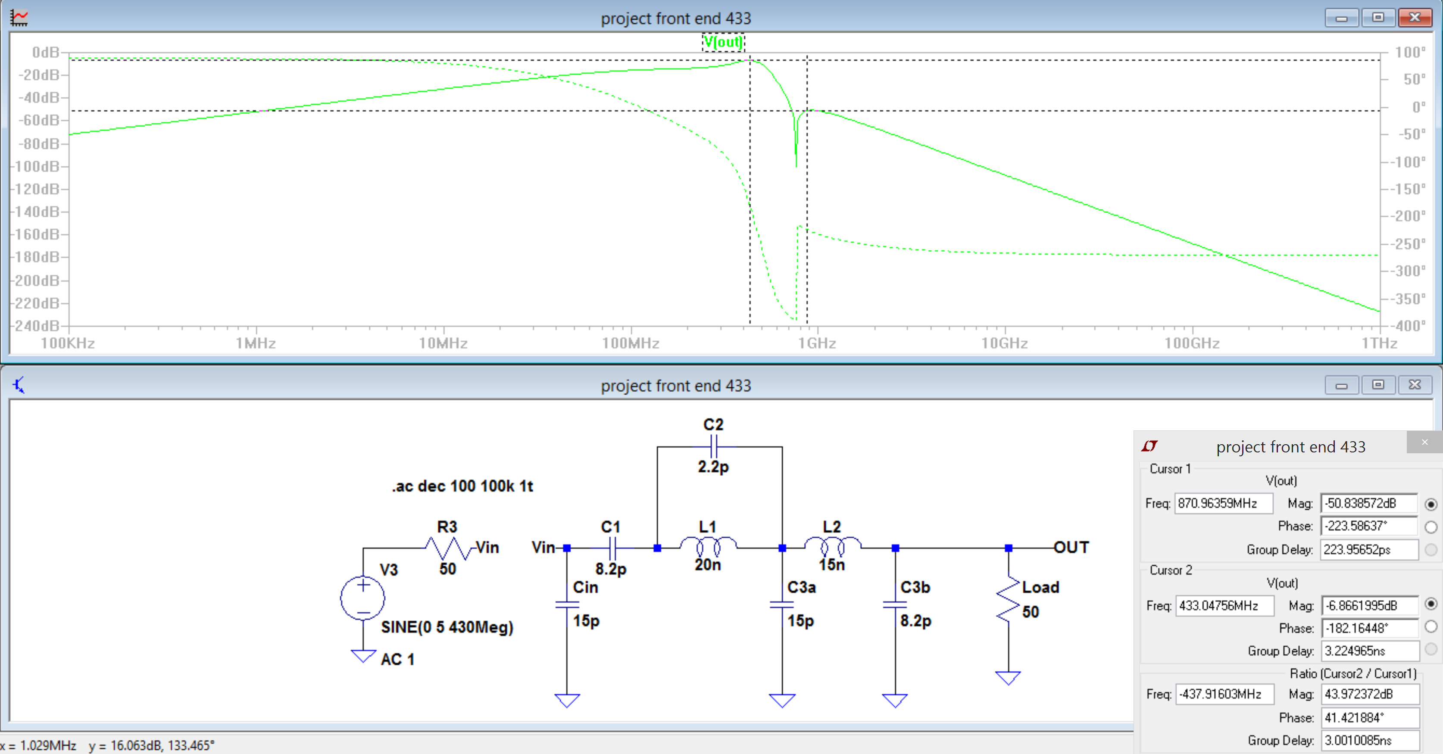
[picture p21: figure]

Figure 5: Rev.2 LTSPICE simulations

Rev. 2 Eagle schematic and board layout

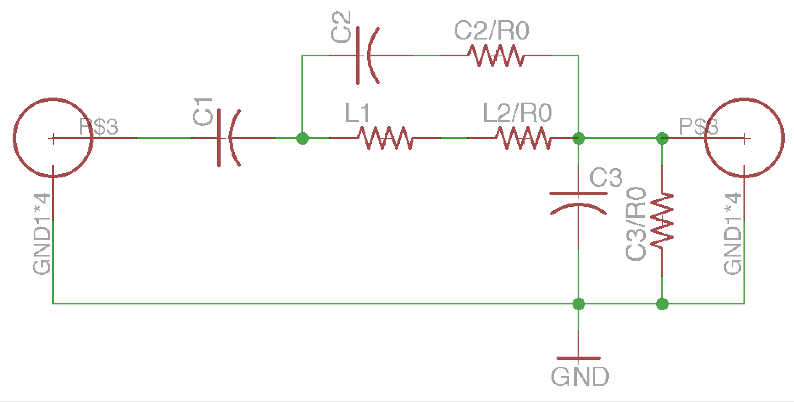
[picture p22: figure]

Figure 6: Rev.2 Eagle Schematic

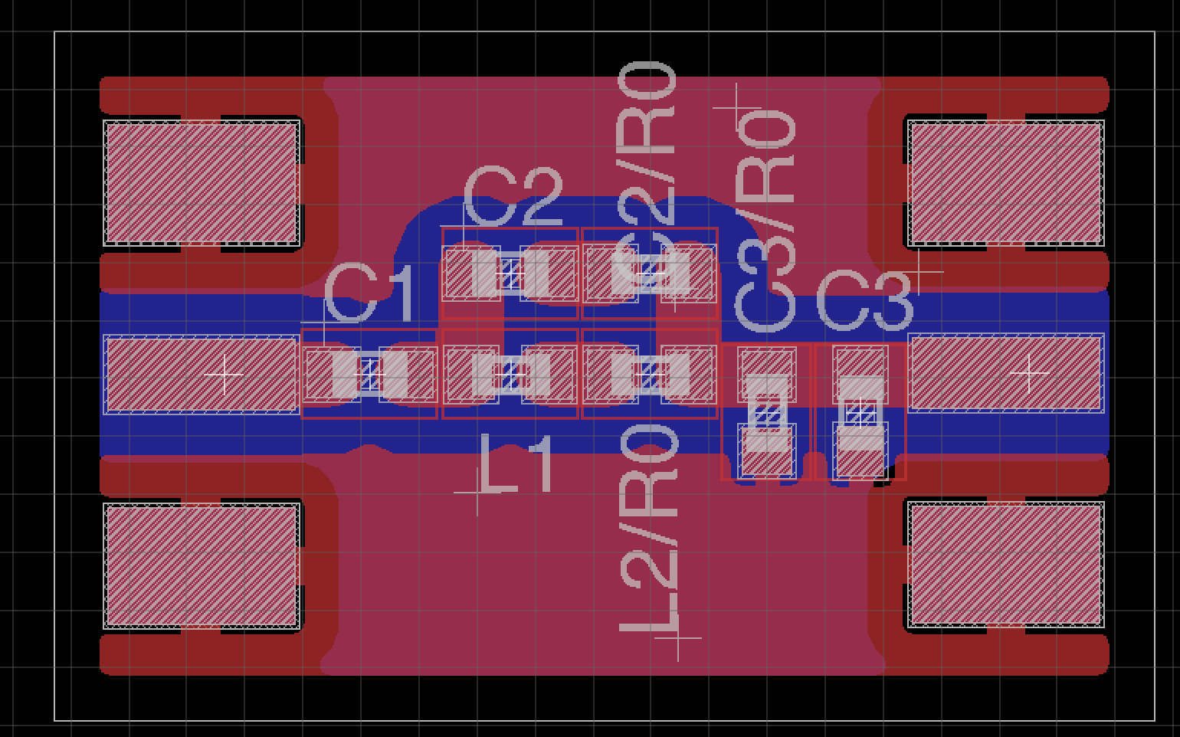
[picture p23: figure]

Figure 7: Rev.2 Board Layout

Alternative Filter Topographies

Simulation has begun on a new design using a Cauer (elliptic) filter. This design is created using Elsie filter design software and the initial results show a good frequency response. The schematic, below, shows the filter and it’s response as designed with normal component values.

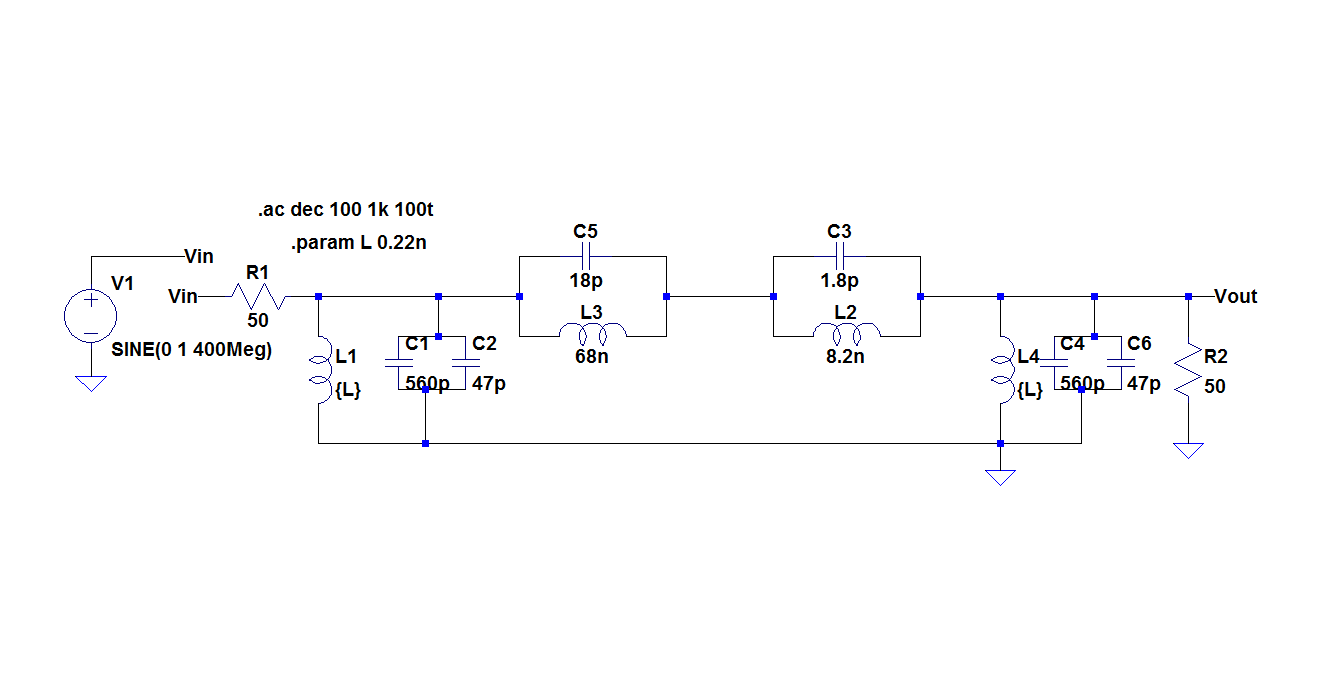
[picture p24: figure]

Figure 8: LTSPICE schematic of elliptical filter designed using Elsie filter design tool.

This is a 4-stage LC filter, so it will require more parts than the Rev.2 design discussed earlier. The response is great at attenuating most of the unwanted frequencies around the desired 436.5 MHz frequency.


Figure 9: LTSPICE simulation of the elliptical filter

Note that one trade off in this filter design is the amount of ripple in the pass band. The second harmonic is attenuated by more than 85dB, which is pretty incredible considering that -40dB is all that is required.


Figure 10: LTSPICE simulation of the elliptical filter showing detail of pass band and 2nd harmonic response

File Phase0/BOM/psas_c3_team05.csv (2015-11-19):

Qty | Value | Device | Package | Parts | Description | DIST | DPN | MF | MFG | MFG-PN | MPN | OC_FARNELL | OC_NEWARK | PROD_ID | VALUE
1 |  | CONNECTION-0.4 | CONNECTION-BUTT-0.4 | W1 | Connection
3 |  | PINHD-1X2 | 1X02 | JP8, JP10, JP11 | PIN HEADER
1 |  | PINHD-2X10 | 2X10 | JP5 | PIN HEADER
1 |  | PINHD-2X11 | 2X11 | JP2 | PIN HEADER
1 |  | PINHD-2X3 | 2X03 | JP9 | PIN HEADER
1 |  | PINHD-2X4 | 2X04 | JP7 | PIN HEADER
1 |  | PINHD-2X6 | 2X06 | JP6 | PIN HEADER
2 |  | PINHD-2X7 | 2X07 | JP3, JP4 | PIN HEADER
18 |  | TESTPOINTROUND0.5MM | TESTPOINT_ROUND_0.5MM | TP1, TP2, TP3, TP4, TP5, TP6, TP7, TP8, TP9, TP10, TP11, TP12, TP13, TP14, TP15, TP16, TP17, TP18 | Test Point
1 | 0 | R-US_0603-B-NOSILK | .0603-B-NOSILK | R6 | RESISTOR, American symbol
1 | 1.27MM_HDR_2X12X1 | 1.27MM_HDR_2X12X1 | 1.27MM_2X1 | J2
1 | 100k | R-US_0603-B-NOSILK | .0603-B-NOSILK | RP3 | RESISTOR, American symbol | Digi-Key | 311-100KHRCT-ND |  | Yageo | RC0603FR-07100KL
1 | 100nF | C-EU0603-B-NOSILK | .0603-B-NOSILK | C15 | CAPACITOR, European symbol | Digi-Key | 478-5778-1-ND |  | AVX | 06035C104JAT2A
8 | 100nF | C-EU0603-B-NOSILK | .0603-B-NOSILK | C8, C9, C18, C23, C25, C27, C28, C29 | CAPACITOR, European symbol | Digi-Key | 490-1532-1-ND |  | Murata Electronics North America |  | GRM188R71C104KA01D
6 | 100nF | C-EU0603-B-NOSILK | .0603-B-NOSILK | C2, C5, C7, C17, C19, C20 | CAPACITOR, European symbol | Digi-Key | 490-1532-1-ND |  | Murata Electronics North America | GRM188R71C104KA01D
1 | 10K (NTC) | THERMISTOR-_1206 | R1206 | RT1 | Thermistor | Digi-Key | 480-3153-1-ND |  | Honeywell Sensing and Control | 175-103LAE-301
1 | 10k | R-US_0603-B-NOSILK | .0603-B-NOSILK | R1 | RESISTOR, American symbol | Digi-Key | 311-10.0KHRCT-ND |  | Yageo | RC0603FR-0710KL
1 | 10nF | C-EU0603-B-NOSILK | .0603-B-NOSILK | C16 | CAPACITOR, European symbol | Digi-Key | 478-6208-1-ND |  | AVX | 0603YC103JAT2A
1 | 12p | C-EU0603-B-NOSILK | .0603-B-NOSILK | C11 | CAPACITOR, European symbol | Mouser | 581-06035A120FAT2A |  | AVX | 06035A120FAT2A
2 | 15n | L-US0603-B-NOSILK | .0603-B-NOSILK | L2, L3 | INDUCTOR, American symbol | Digi-Key | 490-6866-1-ND |  | Murata | LQW18AN15NG00D
2 | 15p | C-EU0603-B-NOSILK | .0603-B-NOSILK | C10, C13 | CAPACITOR, European symbol | Digi-Key | 478-6024-1-ND |  | AVX | 06031A150FAT2A
1 | 1M | R-US_0603-B-NOSILK | .0603-B-NOSILK | R14 | RESISTOR, American symbol | Digi-Key | 311-1.00MHRCT-ND |  | Yageo | RC0603FR-071ML
7 | 1k | R-US_0603-B-NOSILK | .0603-B-NOSILK | R2, R3, R4, R5, R7, R8, R9 | RESISTOR, American symbol | Digi-Key | 311-1.00KHRCT-ND |  | Yageo | RC0603FR-071KL
1 | 1nF | C-EU0603-B-NOSILK | .0603-B-NOSILK | C21 | CAPACITOR, European symbol | Digi-Key | 399-8984-1-ND |  | Kemet | C0603C102K8RACTU
1 | 2.2p | C-EU0603-B-NOSILK | .0603-B-NOSILK | C12 | CAPACITOR, European symbol | Mouser | 77-VJ0603A2R2BXJPBC |  | Vishay / Vitramon | VJ0603A2R2BXJPW1BC
1 | 2.2uF | C-EU0805-B-NOSILK | .0805-B-NOSILK | C6 | CAPACITOR, European symbol | Digi-Key | 490-3906-1-ND |  | Murata Electronics North America | GRM21BR71C225KA12L
1 | 22n | L-US0603-B-NOSILK | .0603-B-NOSILK | L1 | INDUCTOR, American symbol | Digi-Key | 490-6874-1-ND |  | Murata | LQW18AN22NG00D
1 | 32 MHz | FC-12M | FC-12M | X1 | kHz RANGE CRYSTAL UNIT | Digi-Key | 1253-1161-1-ND |  | AVX Corp/Kyocera Corp | CX3225GA32000D0PTVCC
1 | 32 MHz | FC-12M | FC-12M | X2 | kHz RANGE CRYSTAL UNIT | Digi-Key | CTX1364CT-ND |  | CTS-Frequency Controls | 402F3201XIAR
1 | 3220-10-0100-00 | JTAG_ARM-10-50MIL | PINHEADER-2X5-0.05+POL+SILK | J1 | JTAG PIN HEADER 2x5 This is one of the (smaller) ARM standard JTAG connectors. | Digi-Key | 1175-1627-ND |  | CNC Tech | 3220-10-0100-00
1 | 4.7k | R-US_0603-B-NOSILK | .0603-B-NOSILK | R13 | RESISTOR, American symbol | Digi-Key | YAG1317CT-ND |  | Yageo | RC0603JR-074K7P
4 | 4.7uF | C-EU0805-B-NOSILK | .0805-B-NOSILK | C1, C3, C4, C24 | CAPACITOR, European symbol | Digi-Key | 732-7657-1-ND |  | Wurth Electronics Inc | 885012207025
2 | 4pF | C-EU0603-B-NOSILK | .0603-B-NOSILK | C22, C26 | CAPACITOR, European symbol | Digi-Key | 490-10720-6-ND |  | Murata Electronics North America |  | GRM1885C1H4R0CA01D
1 | 5k | R-US_0603-B-NOSILK | .0603-B-NOSILK | RP1 | RESISTOR, American symbol | Digi-Key | YAG1305CT-ND |  | Yageo | RC0603FR-074K99P
2 | 5pF | C-EU0603-B-NOSILK | .0603-B-NOSILK | C30, C31 | CAPACITOR, European symbol | Digi-Key | 490-10720-6-ND |  | Murata Electronics North America |  | GRM1885C1H4R0CA01D
1 | 8.2p | C-EU0603-B-NOSILK | .0603-B-NOSILK | C14 | CAPACITOR, European symbol | Mouser | 609-251R14S8R2BV4T |  | Johanson Technology | 251R14S8R2BV4T
2 | APHFT1612PBASURKVGAC | LED_RGB_COMMON_ANODE-1.6X1.26 | KINGBRITE_RGBLED_1.6X1.26 | LED1, LED2 | RGB LED with comon anode | Digi-Key | 160-2022-1-ND |  | Lite-On Inc. | LTST-C19FD1WT
1 | BC | SPARKFUN-CONNECTORS_M024UCON-15767 | SPARKFUN-CONNECTORS_JST-2-SMD-VERT | JP1 | Standard 2-pin 0.1 header. Use with" | Digi-Key | 455-1749-1-ND |  | JST Sales America Inc. | S2B-PH-SM4-TB(LF)(SN)
1 | CF1 | CON_USB-MICRO-B-RECEPTACLE-PTH-HIROSE-ZX62D-B-5P8 | USB-MICRO-B-PTH-HIROSE | CF1 | Standard USB Micro-B receptacle | Digi-Key | H11610CT-ND |  | Hirose Electric Co Ltd | ZX62D-B-5P8
1 | CP2102 | CP2102 | MLP28 | IC1 | Single-Chip USB to UART Bridge | Digi-Key | 336-1160-1-ND | FARNELL | Silicon Labs | CP2102-GMR | CP2102-GM | 9282130 | 30K5635
1 | EG1218 | SWITCH-SPSTPTH | SWITCH-SPDT | S1 | SPST Switch | Digi-Key | EG1903-ND |  | E-Switch | EG1218
1 | GRN | LED-0603 | LED-0603 | LED3 | Generic LED with Color designator as an attribute. | Digi-Key | 160-1446-1-ND |  | Lite-On Inc. | LTST-C191KGKT
1 | MCP73871 | MCP73871 | QFN20_4MM | U2 | MCP73871 Lithium Polymer Battery Charger | Digi-Key | MCP73871-2CCI/ML-ND |  | Microchip Technology | MCP73871-2CCI/ML
1 | MIC5319 3.3V | SPARKFUN-POWERIC_V_REG_MIC52193.3V | SPARKFUN-POWERIC_SOT23-5 | U1 | V_REG MIC5219 | Digi-Key | 576-1910-1-ND |  | Microchip Technology | MIC5319-3.3YD5-TR |  |  |  | VREG-09872 | MIC5219 3.3V
1 | MKW01Z128 | MKW01Z128 | MKW01Z128 | U3 |  | Digi-Key | MKW01Z128CHN-ND |  | Freescale Semiconductor | MKW01Z128CHN
2 | NP | R-US_0603-B-NOSILK | .0603-B-NOSILK | R10, R11 | RESISTOR, American symbol
1 | SMAJ716-ND | SMAJ716-ND | SMAJ716-ND | U$2 |  | Digi-Key | J716-ND |  | Cinch Connectivity Solutions | 142-0701-806
1 | SWITCH-MOMENTARY-2 | SWITCH-MOMENTARY-2 | TACTILE_SWITCH_TALL | S2 |  | Digi-Key | 450-1759-1-ND |  | TE Connectivity Alcoswitch Switches | FSM4JSMATR

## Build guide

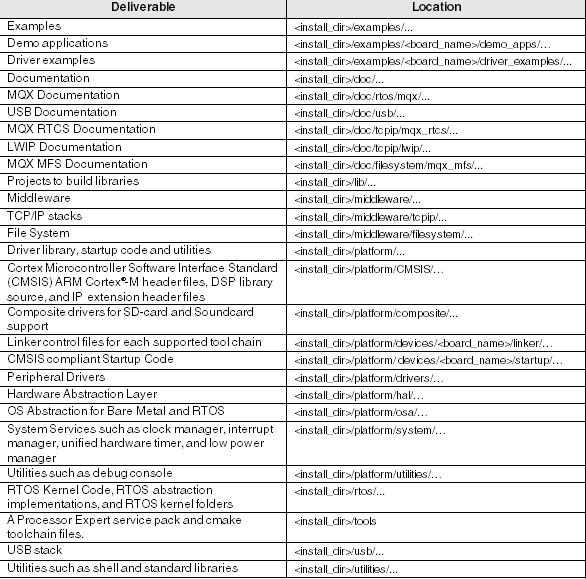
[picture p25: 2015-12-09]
Vendor Firmware/Kinetis SDK v.1.3.0 API Reference Manual/kpsdk_guide01.png

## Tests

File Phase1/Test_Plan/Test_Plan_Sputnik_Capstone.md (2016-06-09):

# Sputnik Capstone Test Plan

written by Shan Quinney, William Harrington, and James Heath

**Table of Contents**
* [Revision History](https://github.com/wrh2/sputnik/blob/master/Phase1/Test_Plan/Test_Plan_Sputnik_Capstone.md#revision-history)
    * [Introduction](https://github.com/wrh2/sputnik/blob/master/Phase1/Test_Plan/Test_Plan_Sputnik_Capstone.md#introduction)
    * [Purpose](https://github.com/wrh2/sputnik/blob/master/Phase1/Test_Plan/Test_Plan_Sputnik_Capstone.md#purpose)
    * [Testing Procedure](https://github.com/wrh2/sputnik/blob/master/Phase1/Test_Plan/Test_Plan_Sputnik_Capstone.md#testing-procedure)
    * [Recording of Results, witnessing, and authorities](https://github.com/wrh2/sputnik/blob/master/Phase1/Test_Plan/Test_Plan_Sputnik_Capstone.md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)
* [Reference Documents](https://github.com/wrh2/sputnik/blob/master/Phase1/Test_Plan/Test_Plan_Sputnik_Capstone.md#reference-documents)
    * [Design Documentation](https://github.com/wrh2/sputnik/blob/master/Phase1/Test_Plan/Test_Plan_Sputnik_Capstone.md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)
* [Overview](https://github.com/wrh2/sputnik/blob/master/Phase1/Test_Plan/Test_Plan_Sputnik_Capstone.md#overview)
    * [Operational Description](https://github.com/wrh2/sputnik/blob/master/Phase1/Test_Plan/Test_Plan_Sputnik_Capstone.md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)
* [Preparation](https://github.com/wrh2/sputnik/blob/master/Phase1/Test_Plan/Test_Plan_Sputnik_Capstone.md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)
    * [Test Equipment](https://github.com/wrh2/sputnik/blob/master/Phase1/Test_Plan/Test_Plan_Sputnik_Capstone.md#test-equipment)
    * [Test setup and calibration](https://github.com/wrh2/sputnik/blob/master/Phase1/Test_Plan/Test_Plan_Sputnik_Capstone.md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)
* [Component Tests](https://github.com/wrh2/sputnik/blob/master/Phase1/Test_Plan/Test_Plan_Sputnik_Capstone.md#component-tests)
     * [Crystal Test](https://github.com/wrh2/sputnik/blob/master/Phase1/Test_Plan/Test_Plan_Sputnik_Capstone.md#crystal-test)
     * [Supply Range Test](https://github.com/wrh2/sputnik/blob/master/Phase1/Test_Plan/Test_Plan_Sputnik_Capstone.md#supply-range-test)
     * [Temperature Range Test](https://github.com/wrh2/sputnik/blob/master/Phase1/Test_Plan/Test_Plan_Sputnik_Capstone.md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)
     * [Force Test](https://github.com/wrh2/sputnik/blob/master/Phase1/Test_Plan/Test_Plan_Sputnik_Capstone.md#force-test)
     * [Vacuum Test](https://github.com/wrh2/sputnik/blob/master/Phase1/Test_Plan/Test_Plan_Sputnik_Capstone.md#vacuum-test)
* [System Tests](https://github.com/wrh2/sputnik/blob/master/Phase1/Test_Plan/Test_Plan_Sputnik_Capstone.md#system-tests)
    * [Radio Communication Test](https://github.com/wrh2/sputnik/blob/master/Phase1/Test_Plan/Test_Plan_Sputnik_Capstone.md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)
    * [Control Test](https://github.com/wrh2/sputnik/blob/master/Phase1/Test_Plan/Test_Plan_Sputnik_Capstone.md#control-test)
    * [Command Test](https://github.com/wrh2/sputnik/blob/master/Phase1/Test_Plan/Test_Plan_Sputnik_Capstone.md#command-test)
    * [Functionality Test](https://github.com/wrh2/sputnik/blob/master/Phase1/Test_Plan/Test_Plan_Sputnik_Capstone.md#functionality-test)

### Revision History

03/03/16 - Created document (Shan)

03/04/16 - Converted to markdown, proofreading changes (Will)

04/17/16 - Changed Communications Test, added functionalty test and grid, added Command test, changed incorrect links in ToC (Jake)

04/17/16 - Added component test section and all component tests and grids: Crystal, supply range, temperature, force, and vacuum. (Jake) 

04/20/16 - Fixed ToC link error (Jake)

04/21/16 - Moved to oresat repo and fixed ToC links (Jake)

04/29/16 - Changes based on Test Plan Review (Jake)

04/29/16 - Changes based on proofreading the test plan (Will)

04/30/16 - More proofreading changes. Changed crystal test to make it explicit that it will be performed on BOTH microcontrollers. Changed Supply Range Test to encompass BOTH modules. Changed Temperature Range Test to encompass BOTH modules and changed steps, actions, and expected results. Revised Acceleration test.

05/14/16 - Grammar corrections in introduction.

05/16/16 - Removed "Test Setup and Calibration" section from the document. Revised Temperature Test with updated procedure. (Shan)  

06/01/16 - Added test results for some of the tests (Jake)  

06/05/16 - More updated test results (Jake)  

06/08/16 - Removed untested tests (Jake)

06/09/16 - Added final test results (Jake)  

06/09/16 - Added Control test results (Jake)

### Introduction

#### Purpose

The purpose of this document is to outline testing that will be essential for determining the effectiveness of the Sputnik Capstone project. This test plan is not intended to be all inclusive and additional testing procedures will be added if deemed necessary by any of the parties involved in the project.

#### Testing Procedure

All of the testing procedures described in this document will be carried out by one or more of the Sputnik capstone team members. An effort will be made to have the entire team present for as many of the tests as possible.

#### Recordings of Results, Witnessing, and Authorities

The results of all testing will be posted in [this git respository](https://github.com/oresat/low-gain-radio) in the docs folder. The tests will be conducted on a pass/fail basis and any tests that do not pass will be noted along with an explanation/conjecture as to why they did not pass. No authorities or witnesses outside of the group will be required to be present during testing.

### Reference Documents

#### Design Documentation

Phase 1 Low Level Diagram

The Sputnik Capstone project is composed of two separate modules: The low-gain-radio (LGR) module and the system-controller (SysCon) module. The LGR is contains a microcontroller with an integrated transceiver referred to as the KW0x that facilitates wireless communication. The SysCon contains a radiation hardened watchdog controller that will be responsible for power cycling components after [Single-Event Upsets](https://en.wikipedia.org/wiki/Single_event_upset) happen. It will also contain only radiation hardened parts to ensure that its power domain is secure. However, for this project, the radiation-hardened components will be replaced with off-the shelf components to help reduce cost.

### Overview

#### Operational Description

The Portland State Aerospace Society is sponsoring this capstone based on the need for a command, control, and communications system for their CubeSat project. The focus of this project will be rapidly prototyping the LGR and SysCon which compose what is referred to as [Sputnik](https://en.wikipedia.org/wiki/Sputnik_1) because of it's requirements to be a simple, reliable space system. Sputnik will be responsible for long distance communications to and from earth while the CubeSat is in orbit, as well as, controlling and communicating with a payload that is housed within the CubeSat. On top of fulfilling these duties, once space bound, it will need to be able to deal with a temperature range of -40C to 80C and radiation events that could cause components to latch up.

### Pre-test preparation

#### Test equipment

The equipment needed for the tests is as follows: 
* Power Supply
    * Able to supply a minimum current of 1A at 3V for approximately 15 minutes
* Multimeter
* Oscilloscope
* Programmers for KW0x and ATMega128
* Environmental Chamber
* Vacuum Chamber
* Antennas

### Component Tests

The Component Tests will test components that are imperative to the core operation of integrated circuits (microcontrollers, voltage regulators, etc.) that implement the desired functionality for the module they are a part of. These are usually small simple tests that ensure that everything is working properly before attempting any tests for functionality.

#### Supply Range Test

The Supply Range Test is for testing the voltage range operation of the LGR and SysCon. This is needed since both modules will be receiving a range of voltages from 3-5V from the power management system (another module in the CubeSat). This test will be done by gradually changing the output voltage on the power supply from 3V-5V and checking that the board still operates. This test also doubles as a test for the crystal, since by checking the crystal we can ensure that the MCU on either board is on.

                          |                              |
------------------------- | ---------------------------- |
Test Case Name            | Supply Range Test            |
Test ID#                  | Supply_1.00                  |
Test Writer               | James Heath, Will Harrington | 
Description               | The purpose of this test is to demonstrate the functionality of the boards and their crystals at the required supply range limits. |
Tester Information        |    |
Name of Tester            |  James Heath (LGR), Shan Quinney & Michael Mathis (SC)  |
Time/Date                 |  5/29/2016, 5/29/2016  |
Hardware Version          |  LGR1.00, SC1.00  |
Setup                     |  Oscilloscope and Power supply in LID  |

Step | Action | Expected Result | Pass/Fail | Comments |
---- | ------ | --------------- | --------- | -------- |
1 | Set voltage supply to 3.0V for LGR | Power LEDs light up (LED1, LED4 on LGR schematic)  | PASS | 3.0V at 3.0V supply |
2 | Check that XTAL is operating with oscillscope | Desired frequency is shown on oscilloscope  | PASS | 32 MHz |
3 | Set voltage supply to 5V for LGR | Power LEDs light up (LED1, LED4 on LGR schematic)  | PASS | 3.3V at 5.0V supply |
4 | Check that XTAL is operating with oscillscope | Desired frequency is shown on oscilloscope  | PASS | 32 MHz |
5 | Set voltage supply to 3.0V for SysCon | Measure V+ at 3.3V with multimeter  | PASS | 3.0 V at 3.0 V supply |
6 | Check that XTAL is operating with oscillscope | Desired frequency is shown on oscilloscope  | PASS | 8 MHz |
7 | Set voltage supply to 5V for SysCon | Measure V+ at 5V with multimeter  | PASS | 3.3V at 5.0V supply. |
8 | Check that XTAL is operating with oscillscope | Desired frequency is shown on oscilloscope  | PASS | 8 MHz |  

### System Tests

#### Radio Test

The purpose of this test is to confirm that the radio is capable of transmission and reception, as well as switching between the Tx and Rx lines. This test will be performed by sending a carrier signal from one board to the other and lighting an LED when receiving the signal. The test locations will be predetermined based on both convenience and also where the least restricted signal propagation path will occur.

                          |                              |
------------------------- | ---------------------------- |
Test Case Name            | Radio Communication          |
Test ID#                  | RadCom_1.00                  |
Test Writer               | Shan Quinney/James Heath     | 
Description               | The purpose of this test is to ensure that the radio is capable of transmitting and receiving signals. |
Tester Information        |    |
Name of Tester            |  James Heath, Shan Quinney   |
Time/Date                 |  6/6/2016  |
Hardware Version          |  Sputnik radio board version 1.00  |
Setup                     | Have boards at some short distance apart. Each location will have a Sputnik radio board with sufficient power supply. Each location will also have a method to verify sent payload data.   |

Step | Action | Expected Result | Pass/Fail | Comments |
---- | ------ | --------------- | --------- | -------- |
1 | Board A is made to transmit carrier signal. | Board B confirms receiving signal from board A by ouputting payload to terminal via UART.  | PASS | 0x01 0x23 0x45 0x67 0x89 appears on terminal  |
2 | Board B is made to transmit carrier signal. | Board A confirms receiving signal from board B by ouputting payload to terminal via UART.   | PASS | 0x01 0x23 0x45 0x67 0x89 appears on terminal |

**Overall Test Result:** Success  

#### Control Test

The system controller is the guardian of the system. It is present to ensure that the system is functioning correctly and that if any unintended event causes component latch-up or system errors, the system can be cycled or rebooted to return stability. This control system is the other half of the project. Eventually, this system will consist of a radiation hardened microcontroller (ATMegaS128) with supporting radiation hardened LDO. For the purpose of prototyping, the controller is a standard, off-the-shelf ATMega128 chip.

To test the control system, a method to simulate a latch-up event will be used to trigger the watchdog into action. Outlined is the kw0x lock-up test. In this test, the crystal on the kw0x will be shorted to cause an error in the radio system. The ATMega should sense that the radio is no longer functioning properly and trigger the reset line on the kw0x to initiate a reboot.

                          |                              |
------------------------- | ---------------------------- |
Test Case Name            | Control Test       |
Test ID#                  | ATM_1.00                     |
Test Writer               | Shan Quinney, Michael Mathis         | 
Description               | The purpose of this test is to demonstrate the effectiveness of the system controller to restart key systems when UART "I'm alive" signals are lost. |
Tester Information        |    |
Name of Tester            |  Michael Mathis  |
Time/Date                 |  6/1/2016  |
Hardware Version          |  Board Rev.1, Filter Rev.1 |
Setup                     |  Laptop and portable programmer  |

Step | Action | Expected Result | Pass/Fail | Comments |
---- | ------ | --------------- | --------- | -------- |
1 | Remove the wire connecting the system controller UART rx and the LGR tx | The system controller will loose the signal from the LGR.  | PASS | Signal is lost |
2 | Probe the UART line between the controller and the LGR to determine that the life line signal is lost | The UART line will be free of any signal between the LGR and the controller.  | PASS | No signal detected |
3 | Monitor the controller to ensure that the reset line on the kw0x has been activated | The reset line on the kw0x will be activated in an effort to reboot the device.  | PASS | Reset line is active |
4 | After 4 seconds make sure that the "I'm alive" signal from the LGR is found again  | The system controller will be receiving the life line signal from the LGR   | PASS |  LGR is restarted and signaling again  |

**Overall Test Result:** Success  

#### Command Test

The Command Test helps us understand whether the board is able to issue commands and update or respond based on these commands. To test this, the Microcontroller will send a command to an LED to light up. If the LED lights up, then the command was successful indicating that the board is able to issue commands.

                          |                              |
------------------------- | ---------------------------- |
Test Case Name            | Command Test                 |
Test ID#                  | CMD_1.00                     |
Test Writer               | Will Harrington              | 
Description               | The purpose of this test is to demonstrate the effectiveness of the system controller to execute commands |
Tester Information        |    |
Name of Tester            |  Michael Mathis & Shan Quinney  |
Time/Date                 |  6/2/2016  |
Hardware Version          |  SC1.00  |
Setup                     |  Sent commands across JTAG interface, viewed LEDs for results |

Step | Action | Expected Result | Pass/Fail | Comments |
---- | ------ | --------------- | --------- | -------- |
1 | Send command | Successful send  | PASS | LED successfully lights up indicating the signal was sent |
2 | Observe LED on prototype | LED lights up  | PASS | LED successfully lights up |

**Overall Test Result:** Success  

#### Functionality Test

                          |                              |
------------------------- | ---------------------------- |
Test Case Name            | Functionality Test           |
Test ID#                  | Func_1.00                    |
Test Writer               | James Heath, Will Harrington | 
Description               | The purpose of this test is to observe the desired functionality as outlined in the project requirements of the LGR and SysCon. |
Tester Information        | The test needs to be performed over a distance of at least 10km. Two LGR setups will be needed we refer to them as Board Tx and Board Rx. By configure Board TX, we mean that it is to send a command to the other module that will cause it to output desired payload. By configure Setup X for RX, we mean that it is to listen for a command that will cause it to output the payload on a computer terminal via UART.  |
Name of Tester            |  Full team  |
Time/Date                 |  6/9/2016  |
Hardware Version          |  LGR1.00, SC1.00  |
Setup                     | Directional Antennas, Power supply, Test sites that are 10km a part   |

Step | Action | Expected Result | Pass/Fail | Comments |
---- | ------ | --------------- | --------- | -------- |
1 | Record GPS coordinates of Setup A and Setup B. Use Coordinate Distance Calculator to get distance.  | Distance is at least 10km  | PASS | Distance around 10.57km from OHSU to Rocky Butte |
2 | Tx Board transmits packet at high power. | High Power LED lights up, terminal reading from UART indicates 0 dBm output from kw0x  | PASS | LED lit up and terminal indicated 0 dBm |
3 | Rx Board receives and outputs to terminal via UART. | Terminal reads payload  | PASS | Terminal read payload: 0x01 0x23 0x45 0x67 0x89 |

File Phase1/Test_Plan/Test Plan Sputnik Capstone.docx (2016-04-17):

Sputnik Capstone Test Plan

Jake Heath

Mike Mathis

Shan Quinney

William Harrington

Table of Contents

Revision History 1

1.0 Introduction 2

1.1 Purpose 2

1.2 Testing procedure 2

1.3 Recordings of Results, witnessing, and Authorities 2

2.0 Reference Documents 2

2.1 Design Documentation 2

3.0 Overview 3

3.1 Operational Description 3

4.0 Preparation 3

4.1 Test Equipment 3

4.2 Test Setup and Calibration 3

5.0 System Tests 4

5.1 10km Radio Test 4

5.2 System Controller Watchdog Test _______5

5.3 Test ______ 6

Revision History

Revision | Date | Changes | Authors
1.00 1.01 | 03/03/2016 04/17/2016 | Initial Release Radio Test Plan | Shan Quinney James Heath

1.0 Introduction

1.1 Purpose

The purpose of this document is to outline the essential testing that will be conducted to demonstrate the effectiveness of the Sputnik Capstone project. This test plan is not intended to be inclusive and additional testing procedures will be added if deemed necessary by any of the parties involved in the project.

1.2 Testing procedure

All of the testing described in this document will be carried out by one or more than one member of the Sputnik capstone team. An effort will be made to have the entire group present for as many of the tests as possible.

1.3 Recording of Results, Witnessing, and Authorities

The results of all testing conducted in this test plan will be displayed on the project wiki. The tests will be conducted on a pass/fail basis and any tests that do not pass will be noted in the documentation with an explanation as to why they did not pass.

No authorities or witnesses outside of the group will be required to be present during testing.

2.0 Reference Documents

2.1 Design Documentation


The Sputnik Capstone project is composed of two separate modules: The radio module and the control module. The radio module is home to the microcontroller with integrated radio transceiver (kwox), while the control module is designed to eventually house a radiation hardened watchdog controller that will help reboot the system after debilitating radiation events. For this project, the radiation-hardened components of the control module will be replaced with off-the shelf components to help reduce cost.

3.0 Overview

3.1 Operational Description

The Portland State Aerospace Society is sponsoring this capstone based on the need for a command, control, and communications system for their CubeSat project. The focus of this capstone will be rapidly prototyping the radio module and the control module. Sputnik will eventually be responsible for long distance communications to and from a 400km low earth orbit, as well as, controlling and communicating with a payload that is housed within the CubeSat. On top of fulfilling these duties, once space bound, it will need to be able to deal with a temperature range of -40C to 50C and radiation events that could cause components to latch up.

4.0 Pre-test Preparation

4.1 Test Equipment

The equipment needed for the tests is as follows:

- Power Supply sufficient to maintain 1A of current at 3V for approximately 15 minutes
- multimeter (voltmeter)
- Oscilloscope
- USB to micro-USB cable
- Logic analyzer

4.2 Test Setup and Calibration

The testing setup will be discussed for each case along with any necessary calibration needed prior to testing.

5.0 System Tests

5.1 Communications Test

The radio is fundamental to the functionality of the Sputnik project. It provides the communication channel that will link the satellite to the ground station. Eventually, the radio will need to receive and transmit data over a distance of approximately 400km; however, for this project, a transmission distance of 10km is required (See functionality test).

The purpose of this test is to confirm that the radio is capable of transmission and reception. It will also test the capabilities of the implemented RF Switch, since the radio will need to switch between transmission and reception. This test will be performed from one radio board to another and the test givers will verify the distance covered during the test by collection GPS location data. The test locations will be predetermined based on both convenience and also where the least restricted signal propagation path will occur.

Test Writer: | | Shan Quinney
Test Case Name: | | Radio Transmission | | | | Test ID#: | 10k_1.00
Description: | | The purpose of this test is to ensure that the radio is capable of transmitting and receiving data at this distance. | | | | Box Type: | ☐ white box ✓ black box
Tester Information
Name of Tester: | | | | | | Date:
Hardware Version: | | Sputnik radio board version 1.00 | | | | Time:
Setup: | | Determine location A and location B, where there is a minimal distance of 10m between points A and B. Have at least one team member located at location A and at least one other team member located at location B. Each location will have a Sputnik radio board with sufficient power supply. Each location will also have a method to verify GPS and time (cell phone).
Step | Action | Expected Result | Pass | Fail | N/A | Comments
1 | Radio at location A is made to transmit data. | Team member at location B confirms receiving data transmitted from location A.
2 | Radio at location B sends confirmation signal. | Team member at location A confirms receiving data from radio at location B.
Overall Test Result:

5.2 Controller Watchdog Test

The controller is the guardian of the system. It is present to ensure that the system is functioning correctly and that if any unintended event causes component latch-up or system errors, the system can be cycled or rebooted to return stability. This control system is the other half of the project. Eventually, this system will consist of a radiation hardened ATMega controller with supporting radiation hardened LDO. For now, the controller is a standard, off-the-shelf ATMega chip.

To test the control system, a method to simulate a latch-up event will be used to trigger the watchdog into action. Outlined is the kwox lock-up test. In this test, the crystal on the kwox will be shorted to cause an error in the radio system. The ATMega should sense that the radio is no longer functioning properly and trigger the reset line on the kwox to initiate a reboot.

Test Writer: | | Shan Quinney
Test Case Name: | | Controller watchdog test | | | | Test ID#: | ATM_1.00
Description: | | The purpose of this test is to demonstrate the effectiveness of the watchdog to restart key system functionality after radiation events. | | | | Box Type: | ☐ white box ✓ black box
Tester Information
Name of Tester: | | | | | | Date:
Hardware Version: | | Board Rev.1, Filter Rev.1, Wire antenna | | | | Time:
Setup:
Step | Action | Expected Result | Pass | Fail | N/A | Comments
1 | Use a metal tool to cause a short across the crystal | The kwox will lose the signal from the crystal.
2 | Probe the UART line between the controller and the kwox to determine that the life line signal is lost | The UART line will be free of any signal between the kwox and the controller.
3 | Monitor the controller to ensure that the reset line on the kwox has been activated | The reset line on the kwox will be activated in an effort to reboot the device.
Overall Test Result:

5.3 Last test

Test Writer:
Test Case Name: | | | | | | Test ID#:
Description: | | | | | | Box Type: | ☐ white box ✓ black box
Tester Information
Name of Tester: | | | | | | Date:
Hardware Version: | | | | | | Time:
Setup:
Step | Action | Expected Result | Pass | Fail | N/A | Comments
1
2
Overall Test Result:

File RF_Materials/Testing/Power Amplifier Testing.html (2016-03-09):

by William Harrington

# Introduction

The purpose of this document is to examine the output power capability of the power amplifier chosen by the Sputnik team for their module.

### Materials

- Agilent E8241A Signal Generator
- Tektronix RSA3308A Spectrum Analyzer
- Tektronix PS2520G Programmable Power Supply
- IR Temperature Gauge
- 4 dB 20 watt attenuator
- Various patch cords and N to SMA adapters
- KW0x Breakout board
- Power Amplifier breakout board

### Setup

#### With Signal Generator

Signal generator was hooked up to input for Power Amplifier. Power Amplifier was powered off programmable power supply. Output of Power Amplifier hooked up to 4dB 20W attenuator which was hooked up to Spectrum Analyzer.

#### With KW0x

KW0x was hooked up to input for Power Amplifier. Power Amplifier was powered off programmable power supply. Output of Power Amplifier hooked up to 4dB 20W attenuator which was hooked up to Spectrum Analyzer.

### Procedure

#### With Signal Generator

1. Used signal generator for generating input power for power amplifier.
2. Programmable power supply used for powering amplifier also gave measurement of current being pulled by PA when on.
3. Output power of power amplifier measured by spectrum analyzer.
4. Temperature of power amplifier measured by IR temp gauge.

#### With KW0x

1. Used KW0x breakout board for generating input power for power amplifier.
2. Programmable power supply used for powering amplifier also gave measurement of current being pulled by PA when on.
3. Output power of power amplifier measured by spectrum analyzer

#### Measurements recorded

- Input Power (dBm)
- Current Consumption of Power Amplifier (Amps)
- Temperature \((\,^{\circ}\mathrm{C})\)
- Output Power of the Power Amplifier (dBm)

In [26]:

import numpy as np
import matplotlib.pylab as plt
%matplotlib inline
from IPython.display import set_matplotlib_formats

# Graphing helper function
def setup_graph(title='', x_label='', y_label='', fig_size=None):
    fig = plt.figure()
    if fig_size != None:
        fig.set_size_inches(fig_size[0], fig_size[1])
    ax = fig.add_subplot(111)
    ax.set_title(title)
    ax.set_xlabel(x_label)
    ax.set_ylabel(y_label)

# With Signal Generator

In [27]:

# read the data
columns = np.loadtxt('RFPAtest.csv',
                    dtype=float,
                    delimiter=',',
                    unpack=True)

current = columns[0]
temp = columns[1]
input_power = columns[2]
output_power = columns[5]

## Current

In [28]:

setup_graph('Current vs. Output Power',
            r'Output Power $(dBm)$',
            'Current (Amps)',
            (9,6.5))
plt.plot(output_power, current)
plt.show()

In [29]:

setup_graph('Current vs. Input Power',
            r'Input Power $(dBm)$',
            'Current (Amps)',
            (9,6.5))
plt.plot(input_power, current)
plt.show()

In [30]:

setup_graph('Temperature vs. Current',
            'Current (Amps)',
            r'Temp $(\,^{\circ}\mathrm{C})$',
            (9,6.5))
plt.plot(current, temp)
plt.show()

# With KW0x

In [31]:

# read the data
columns = np.loadtxt('KW0xPAtest.csv',
                    dtype=float,
                    delimiter=',',
                    unpack=True)

current = columns[0]
temp = columns[1]
input_power = columns[2]
output_power = columns[5]
second_harm = columns[6]

## Current

In [32]:

setup_graph('Current vs. Output Power',
            r'Output Power $(dBm)$',
            'Current (Amps)',
            (9,6.5))
plt.plot(output_power, current)
plt.show()

In [33]:

setup_graph('Current vs. Input Power',
            r'Input Power $(dBm)$',
            'Current (Amps)',
            (9,6.5))
plt.plot(input_power, current)
plt.show()

In [34]:

setup_graph('Temperature vs. Current',
            'Current (Amps)',
            r'Temp $(\,^{\circ}\mathrm{C})$',
            (9,6.5))
plt.plot(current, temp)
plt.show()

## Power

In [35]:

setup_graph('Output Power vs. Input Power',
            'Input (dBm)',
            'Output (dBm)',
            (9,6.5))
plt.plot(input_power, output_power)
plt.show()

In [36]:

# get rid of 0 measurements
second_harm = second_harm[4:]
output_power = output_power[4:]

setup_graph('2nd Harmonic vs. Output Power',
            r'Output Power $(dBm)$',
            r'2nd Harmonic $(dBm)$',
            (9,6.5))
plt.plot(output_power, second_harm)
plt.show()

In [37]:

delta = []
for i in range(len(output_power)):
    delta.append(output_power[i]-second_harm[i])

setup_graph('Output Power - 2nd Harmonic vs. Output Power',
            r'Output Power $(dBm)$',
            r'Output Power - 2nd Harmonic $(dBm)$',
            (9,6.5))
plt.plot(output_power, delta)
plt.show()

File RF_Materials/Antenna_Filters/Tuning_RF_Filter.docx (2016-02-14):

The purpose of this document is to determine the appropriate components that will improve the response of the front-end filter used on the current C3 breakout board. By systematically altering the value of the capacitors and inductors, one at a time, and observing the effects this change has on the filter in simulation, the hope is that a blueprint can be made that will assist in future tuning. ADS is a simulation tool that is created specifically for RF, microwave, and high speed digital designers. Since this software is required learning for the microwave IC design classes at PSU, it seemed logical to revisit the previous simulations done in LTSPICE for the design of the front-end filter. Below is an image of the final LTSPICE schematic design for the bidirectional filter. For comparison, this is followed by an image of the same design used in ADS.

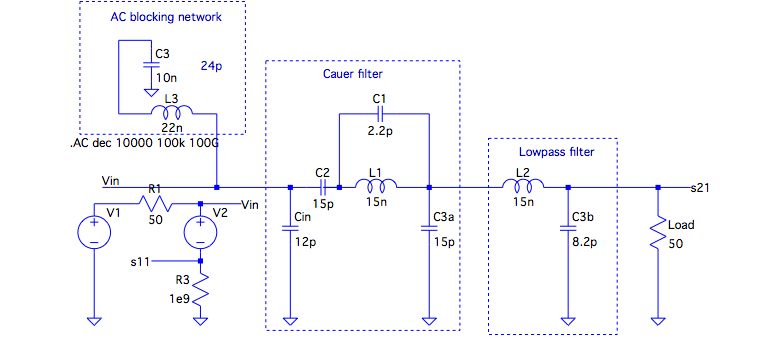
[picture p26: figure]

Figure 1. LTSPICE schematic for front end filter

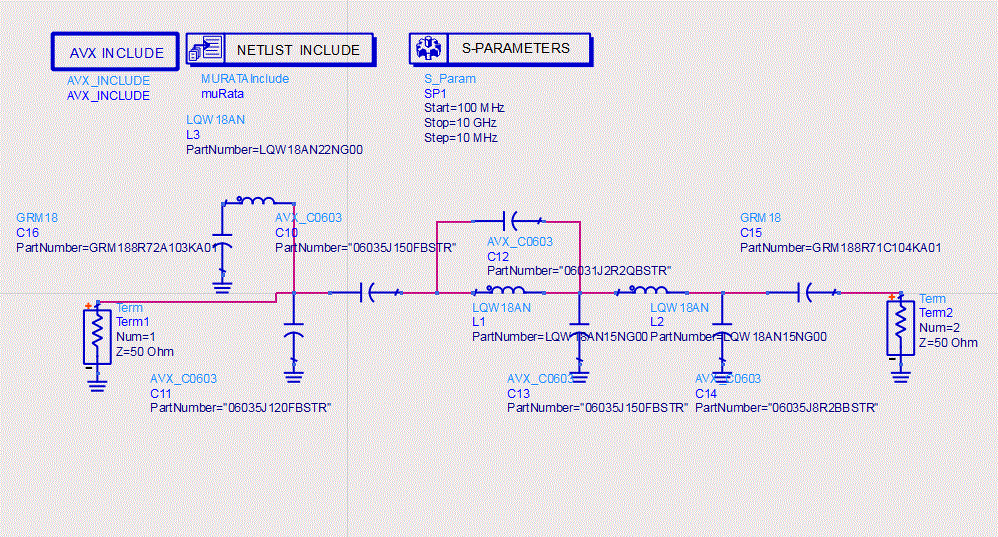
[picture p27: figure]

Figure 2. ADS schematic for front end filter

The schematic generated in Eagle for the front-end filter is shown below. This schematic represents the final layout on the original breakout board. All components will be referenced from this image in the remainder of the document.

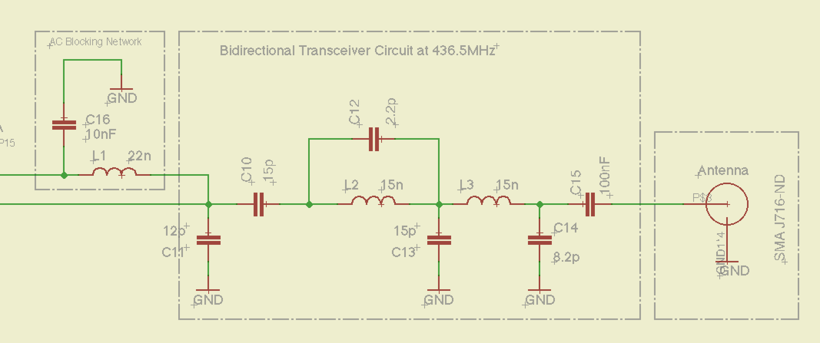
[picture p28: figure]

Figure 3. Eagle schematic showing front end filter

Figures 4 and 5 show the response of the filter as simulated in ADS, which is based on the final design on the breakout board. It is easy to see that the center frequency of this filter is not at the desired frequency of 436.5 MHz. This is due to testing the response of the filter prior to build where it was determined an approximate difference between simulation and measurement. This difference was calculated into the filter design with the hopes of achieving a better response.

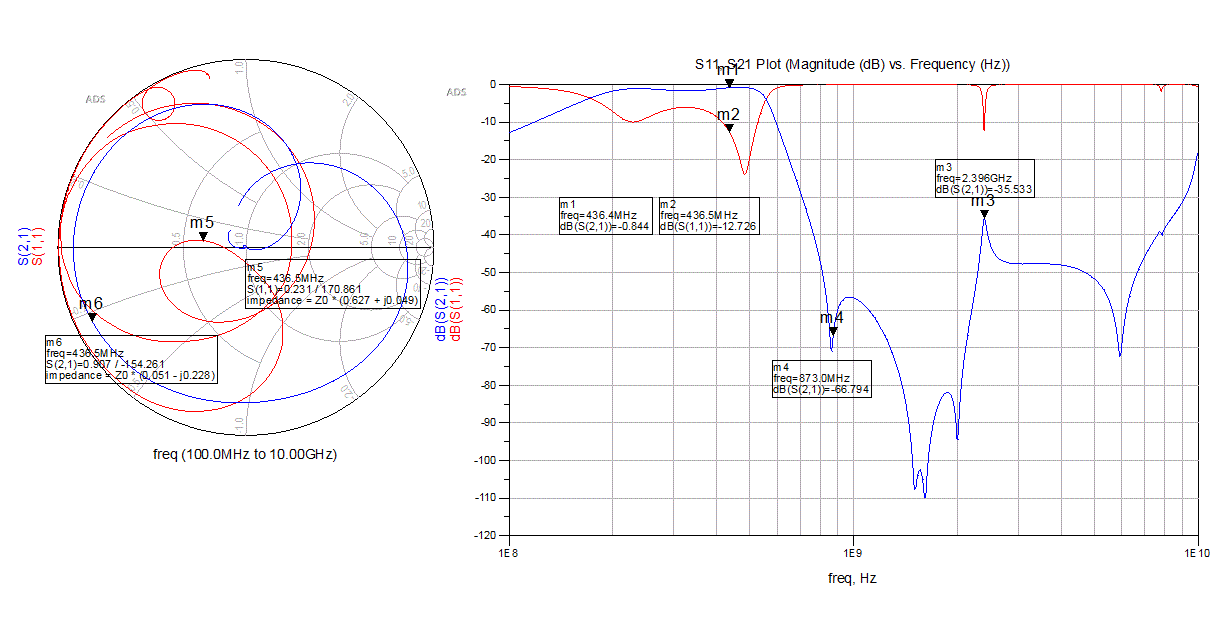
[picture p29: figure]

Figure 4: S11 and S21 response of front end filter as designed on rev0 breakout board

As noted previously, the idea is to test each of the main capacitors and inductors one at a time and report their individual effects on the filter as a whole system. Each component will be analyzed with a plus or minus 33% change in value followed by a brief discussion of the findings. This will all be done using the simulation tool ADS.

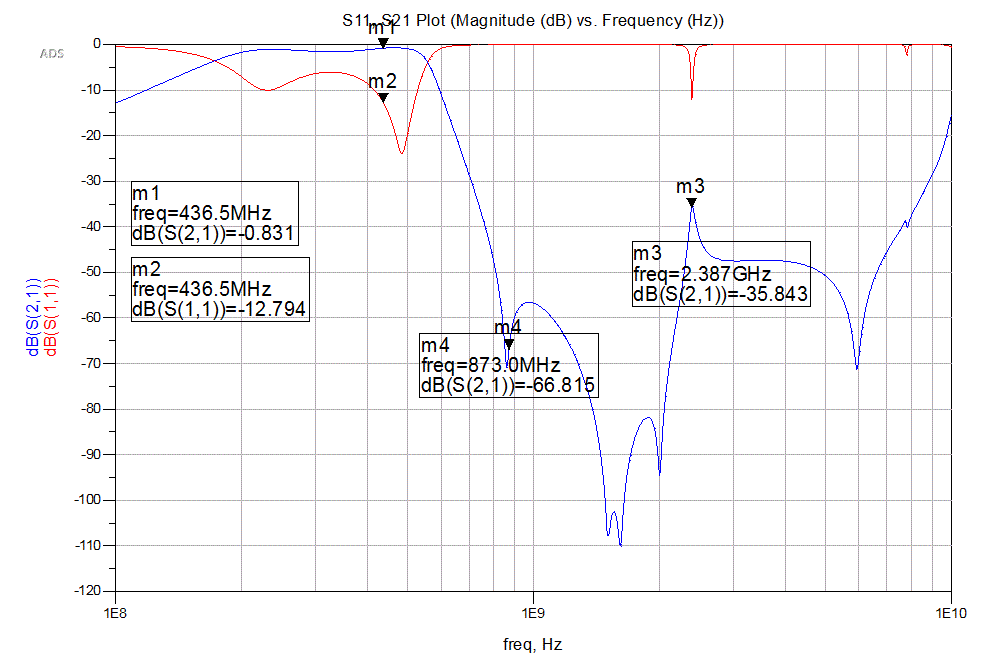
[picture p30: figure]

Figure 5. S11 and S21 response of filter before tuning

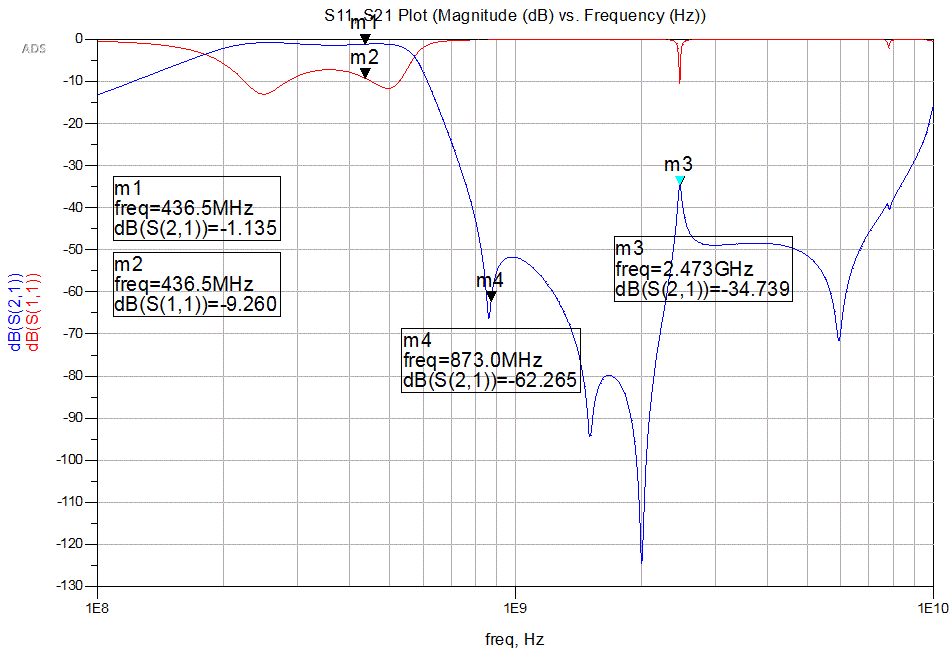
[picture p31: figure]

Figure 6. C11 tuned from 12pF down to 8.2pF

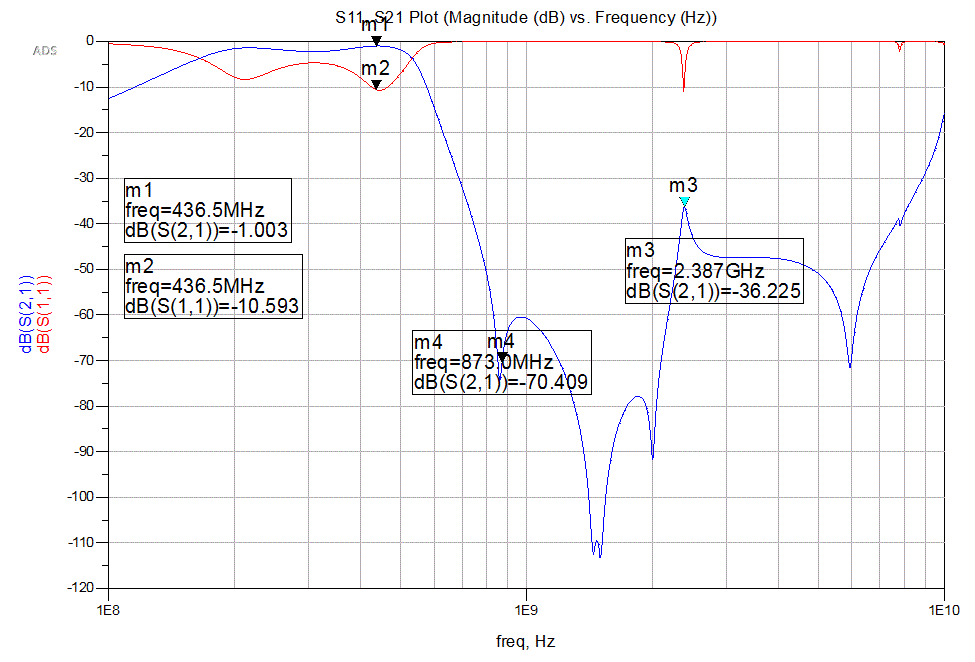
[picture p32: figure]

Figure 7. C11 tuned from 12pF to 16pF

Tuning C11 moves the center frequency of the pass band up and down. However, the S11 response at the center frequency is made worse. The 2nd harmonic attenuation is barely changed during the tuning. Interestingly, the shape of the elliptical filter seems to change between the 2nd harmonic and the marker m3. However, the frequency at m3 is only slightly affected. Overall, this capacitor could be used to tune the frequency of interest closer to the center of the pass band.

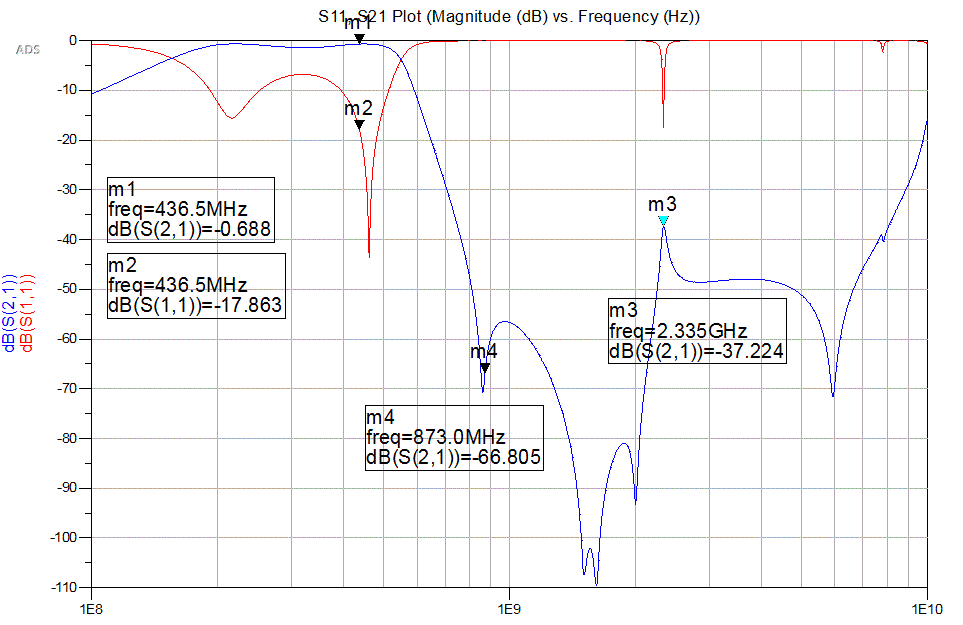
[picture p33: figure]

Figure 8: C10 Tuned from 15pF up to 20pF

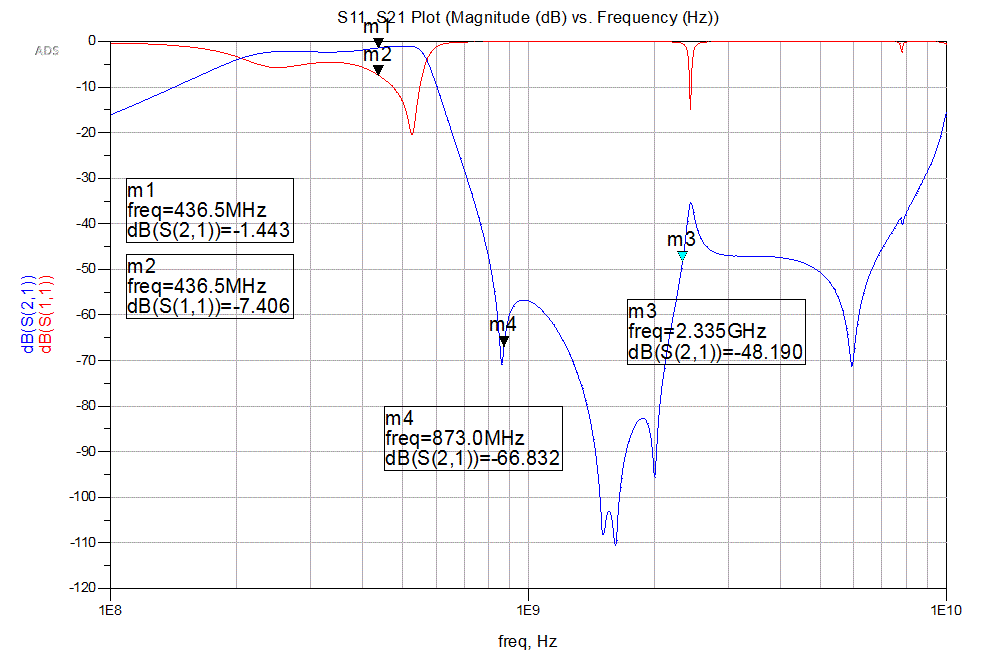
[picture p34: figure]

Figure 9: C10 Tuned from 15pF down to 10pF

Tuning C10 has a slight effect on moving the center frequency of the pass band. More interestingly, the S11 response seems to improve drastically as the capacitance is increased. A slight improvement in the S21 response is also made when the capacitance is increased. The change in the value of C11 does not seem to alter the attenuation of the 2nd harmonic and higher frequencies seem mostly unaffected. Overall, this capacitor could be used to improve the S11 and S21 response of the filter.

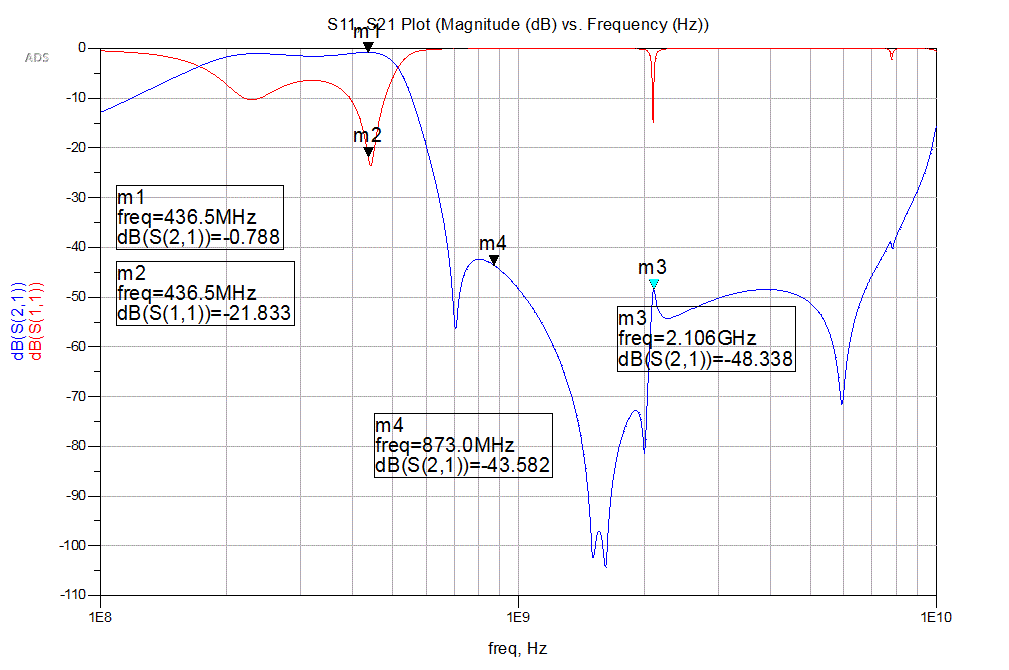
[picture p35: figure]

Figure 10: C12 Tuned from 2.2pF down to 3.3pF


Figure 11: C12 Tuned from 2.2pF down to 1.5pF

Tuning C12 has a dramatic effect on the 2nd harmonic attenuation. Also, the higher frequencies are greatly affected. Notice how much the marker m3 changes between figure 10 and figure 11. The center frequency is tunable with this capacitor and Figure 10 does show an improved S11 response at the frequency of interest. This capacitor should most likely not be considered tunable due to the adverse affects of the response in the higher frequencies.


Figure 12: C13 Tuned from 15pF down to 20pF


Figure 13: C13 Tuned from 15pF down to 10pF

Tuning C13 has the effect of moving the center of the pass band. Also, the S11 and S21 parameters are improved when the capacitance is reduced. The higher frequencies are less affected by the change in capacitance; the 2nd harmonic attenuation seems to hold position across the change. Overall, the capacitor can be used to tune the center frequency of the filter and improve the s-parameter response.


Figure 14: C14 Tuned from 8.2pF up to 11pF


Figure 15: C14 Tuned from 8.2pF up to 5.6pF

Tuning C14 makes no improvement on the pass band and shows only mild changes at he 2nd harmonic attenuation. However, the filter response at higher frequencies has been improved. This capacitor is a good candidate for smoothing out some of the higher frequency spikes (especially the one centered around 2.4 GHz).


Figure 16: L1 Tuned from 15nH up to 20nF


Figure 17: L1 Tuned from 15nH up to 10nF

Tuning L1 has some negative consequences on the pass band when the inductor is tuned down. However, the response is slightly improved when the inductance is increased. Also, the 2nd harmonic response is drastically changed across the tuning range. Overall, this inductor should most likely not be changed.


Figure 18: L2 Tuned from 15nH up to 20nF


Figure 19: L2 Tuned from 15nH up to 10nF

Tuning L2 seems to move the center frequency of the pass band slightly; however, the S11 and S21 response does not improve noticeably. Also, there is no real enhancement to the filter at the higher frequencies. Overall, this inductor has little obvious benefit as a tunable component.

Overview of observations from simulation:

C11: Overall, this capacitor could be used to tune the frequency of interest closer to the center of the pass band. The center frequency moves up when the capacitance is increased and moves down when the capacitance is decreased.

C10: Overall, this capacitor could be used to improve the S11 and S21 response of the filter. This improvement was made when the capacitance was tuned higher.

C12: This capacitor should most likely not be considered tunable due to the adverse affects of the response in the higher frequencies.

C13: Overall, the capacitor can be used to tune the center frequency of the filter and improve the s-parameter response. This improvement was made when the capacitance was tuned down.

C14: This capacitor is a good candidate for smoothing out some of the higher frequency spikes (especially the one centered around 2.4 GHz). This improvement was made when the capacitance was tuned down.

L1: Overall, this inductor should most likely not be changed.

L2: Overall, this inductor should most likely not be changed.

An example of the tuned filter is shown in the next figure. Here, the lessons learned from the above simulations were applied. C11 is tuned from 12 pF to 15pF. C10 is tuned from 15pF to 22pF. C14 is tuned from 8.2pF to 6.2pF.


Figure 20: L2 Tuned filter with improved center frequency response, S21 response, and S11 response.

As a note, tuning this circuit is not trivial. This exercise was supposed to help single out the components that could be used to make quick and easy enhancements to the filter to improve the response. However, it became apparent during tuning that although a single component can have an impact on the response of the filter, it generally requires several components to be tuned to achieve any real benefit. This is further complicated by the fact that as the order of the tuned components increases, the complexity of the tuning increases, where each change has an additive effect on the system as a whole. Obviously, a more quantitative evaluation of the filter is required in order to effectively make real, intelligent design changes.

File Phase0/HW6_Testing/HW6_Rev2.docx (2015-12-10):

Portland State Aerospace Society

C3 Board

(Command, Control, Communications)


Test Plan, Homework #6

T05 CubeSat C3

11-25-2015

ECE411, fall 2015

Mark Faust

Andrew Greenburg

T05- Team

Jake Heath

Mike Mathis

Shan Quinney

Saroj Bardewa

William Harrington

Table of Contents

Revision History 2

1.0 Introduction 2

1.1 Purpose 2

1.2 Testing procedure 2

1.3 Recordings of Results, witnessing, and Authorities 2

2.0 Reference Documents 3

2.1 Design Documentation 3

3.0 Overview 4

3.1 Operational Description 4

3.2 Definition of Terminology 4

3.3 Computational Methods 4

4.0 Preparation 5

4.1 Test Equipment 5

4.2 Test Setup and Calibration 5

5.0 System Tests 6

5.1 Module Tests 6

5.1.1 Power System 6

5.1.1.1 Battery charger 6

5.1.1.2 Voltage regulator 6

5.1.2 USB2UART chip 6

5.1.3 GPIO 6

5.1.4 JTAG 6

5.1.5 MCU 6

5.1.6 RF Front End 6-7

5.1.7 RF Antenna 7-8

5.2 Interface Tests 8

5.2.1 RF Front End to Integrated Transceiver 8

5.2.2 JTAG to MCU 9

5.2.3 MCU to GPIO 10

5.3 Complete System Test 11

APPENDIX: TEST RECORD SHEETS

Revision History

Revision | Date | Changes | Authors
1.00 | 11/21/2015 | Initial Release | Shan Quinney
1.01 | 11/22/2015 | RF tests | Shan Quinney, Jake Heath
1.02 | 11/23/15 | JTAG test | Saroj Bardewa
1.03 | 11/24/2015 | GPIO test | Saroj Bardewa
2.0 | 11/25/2015 | Power system | Will Harrington

1.0 Introduction

1.1 Purpose

The purpose of this document is to outline a comprehensive test plan for the first version of the CubeSat C3 project. The test plan is intended to be as complete as possible, but with an understanding that all test vectors cannot be possibly covered. There are however four crucial tests that are covered in detail.

1.2 Testing procedure

The members of the team will carry out all of the tests described in this document. An effort will be made to have the entire group present for as many of the tests as possible. This should include the initial power-up of the board and various low-level tests such as measuring the expected voltages at pre-defined nodes and various current levels where applicable. Individual members or smaller groups of the team will likely conduct the functional unit/module tests, as well as, the integration tests.
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

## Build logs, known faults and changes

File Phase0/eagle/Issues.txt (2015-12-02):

1) Footprint for crystal is wrong, needs to be for 32MHz
2) LED footprint needs to be changed to match LED that was actually used
3) The battery charger setup is completely wrong.
   !TE needs to be tied LOW
   SEL needs to be tied LOW
   CE needs to be tied HIGH
   PROG2 needs to be tied HIGH

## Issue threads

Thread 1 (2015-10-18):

microcontroller unit package

wrh2, 2015-10-18:
Package for board layout is not precise enough. Looks like crap and needs to be revised before we do board layout.

wrh2, 2015-10-26:
Fixed it on friday. commit 5cd86d190bcfdac3eb3776bce9c519a2166a2ec8

Closed 2015-10-26.

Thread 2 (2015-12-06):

Battery charger set up is wrong

wrh2, 2015-12-06:
!TE needs to be tied LOW
SEL needs to be tied LOW
CE needs to be tied HIGH
PROG2 needs to be tied HIGH

The only solution right now is cutting the traces for these connections and mod wiring them as specified above. This needs to be rectified in V2.

Bearking, 2015-12-09:
We got one board mod wired to fix this, though the other one isn't working. We think it's due to an issue with soldering the MCU though, so I think we'll have to dump that one.

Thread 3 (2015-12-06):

Crystal oscillator footprint

wrh2, 2015-12-06:
The external oscillator has a footprint for a 32kHz clock. Thankfully, we were able to find a 32MHz that was just slightly larger than that footprint so we were still able to use it. However the footprint needs to be changed to match the 32MHz crystal.

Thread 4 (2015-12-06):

Tri-color LED footprints

wrh2, 2015-12-06:
We couldn't find the kingbrite tri-color LEDs that we wanted to use so we had to use a similar tri-color LED. However its footprint is different from the kingbrite one. We need to change it in V2 of the board.

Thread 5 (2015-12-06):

RF trace lines

Bearking, 2015-12-06:
RF trace lines need to be around 109 mils, but we can only fit about 55 mils and we only used 30 mils for this board rev. When we move to a multi-layered board this issue can be fixed though.

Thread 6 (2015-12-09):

Standoff holes should be size #4

ThirteenFish, 2015-12-09:
On the next rev of the dev board. They're currently #2 and no one has hardware sized correctly to stick through them.

wrh2, 2015-12-15:
There are screw that work for these holes but we don't have many of them. They should be changed to a more common size as you suggested. I will definitely make sure this happens in the next rev of the board.

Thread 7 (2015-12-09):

Have separate transceiver and MCU clocks

ThirteenFish, 2015-12-09:
Feeding the clock output from the transceiver to the MCU, but then having to poke the transceiver over SPI first to get the right clock to feed the PLL is just silly. Adding an extra oscillator wont be that much more complicated in hardware and will greatly simplify firmware.

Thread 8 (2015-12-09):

RGB LED on charger chip should go to VBUS

andrewgreenberg, 2015-12-09:
... not 3.3V. That way the LED still indicates charge status even if the board switch is off.

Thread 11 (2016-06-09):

Need pull-up resistors on the PA enable line

Bearking, 2016-06-09:
No pull-up on the PA enable line so it's floating. It's mod wired on the current rev, but this needs to be fixed for the next one.

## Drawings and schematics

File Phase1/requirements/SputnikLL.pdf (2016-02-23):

## C3 Module

## Radio Transceiver

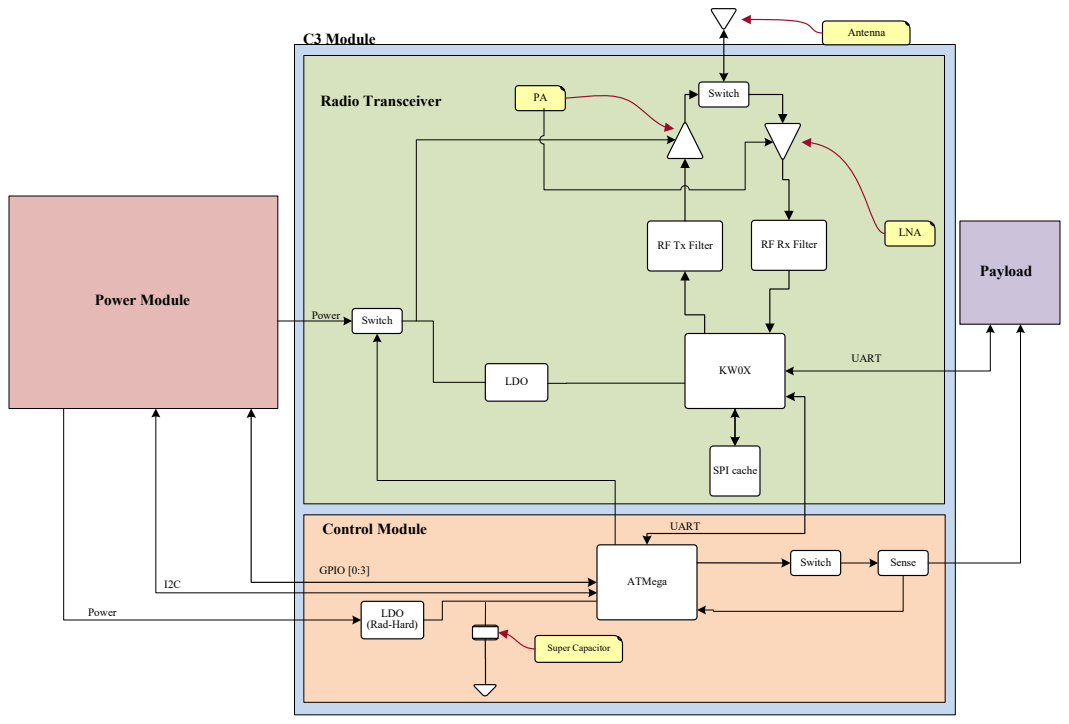
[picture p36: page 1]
ATMega; SPI cache; RF Tx Filter; RF Rx Filter; Switch; LNA; Antenna; LDO; Super Capacitor; UART; Power Module; Payload; Sense; Power; LDO (Rad-Hard)

Control Module GPIO [0:3]

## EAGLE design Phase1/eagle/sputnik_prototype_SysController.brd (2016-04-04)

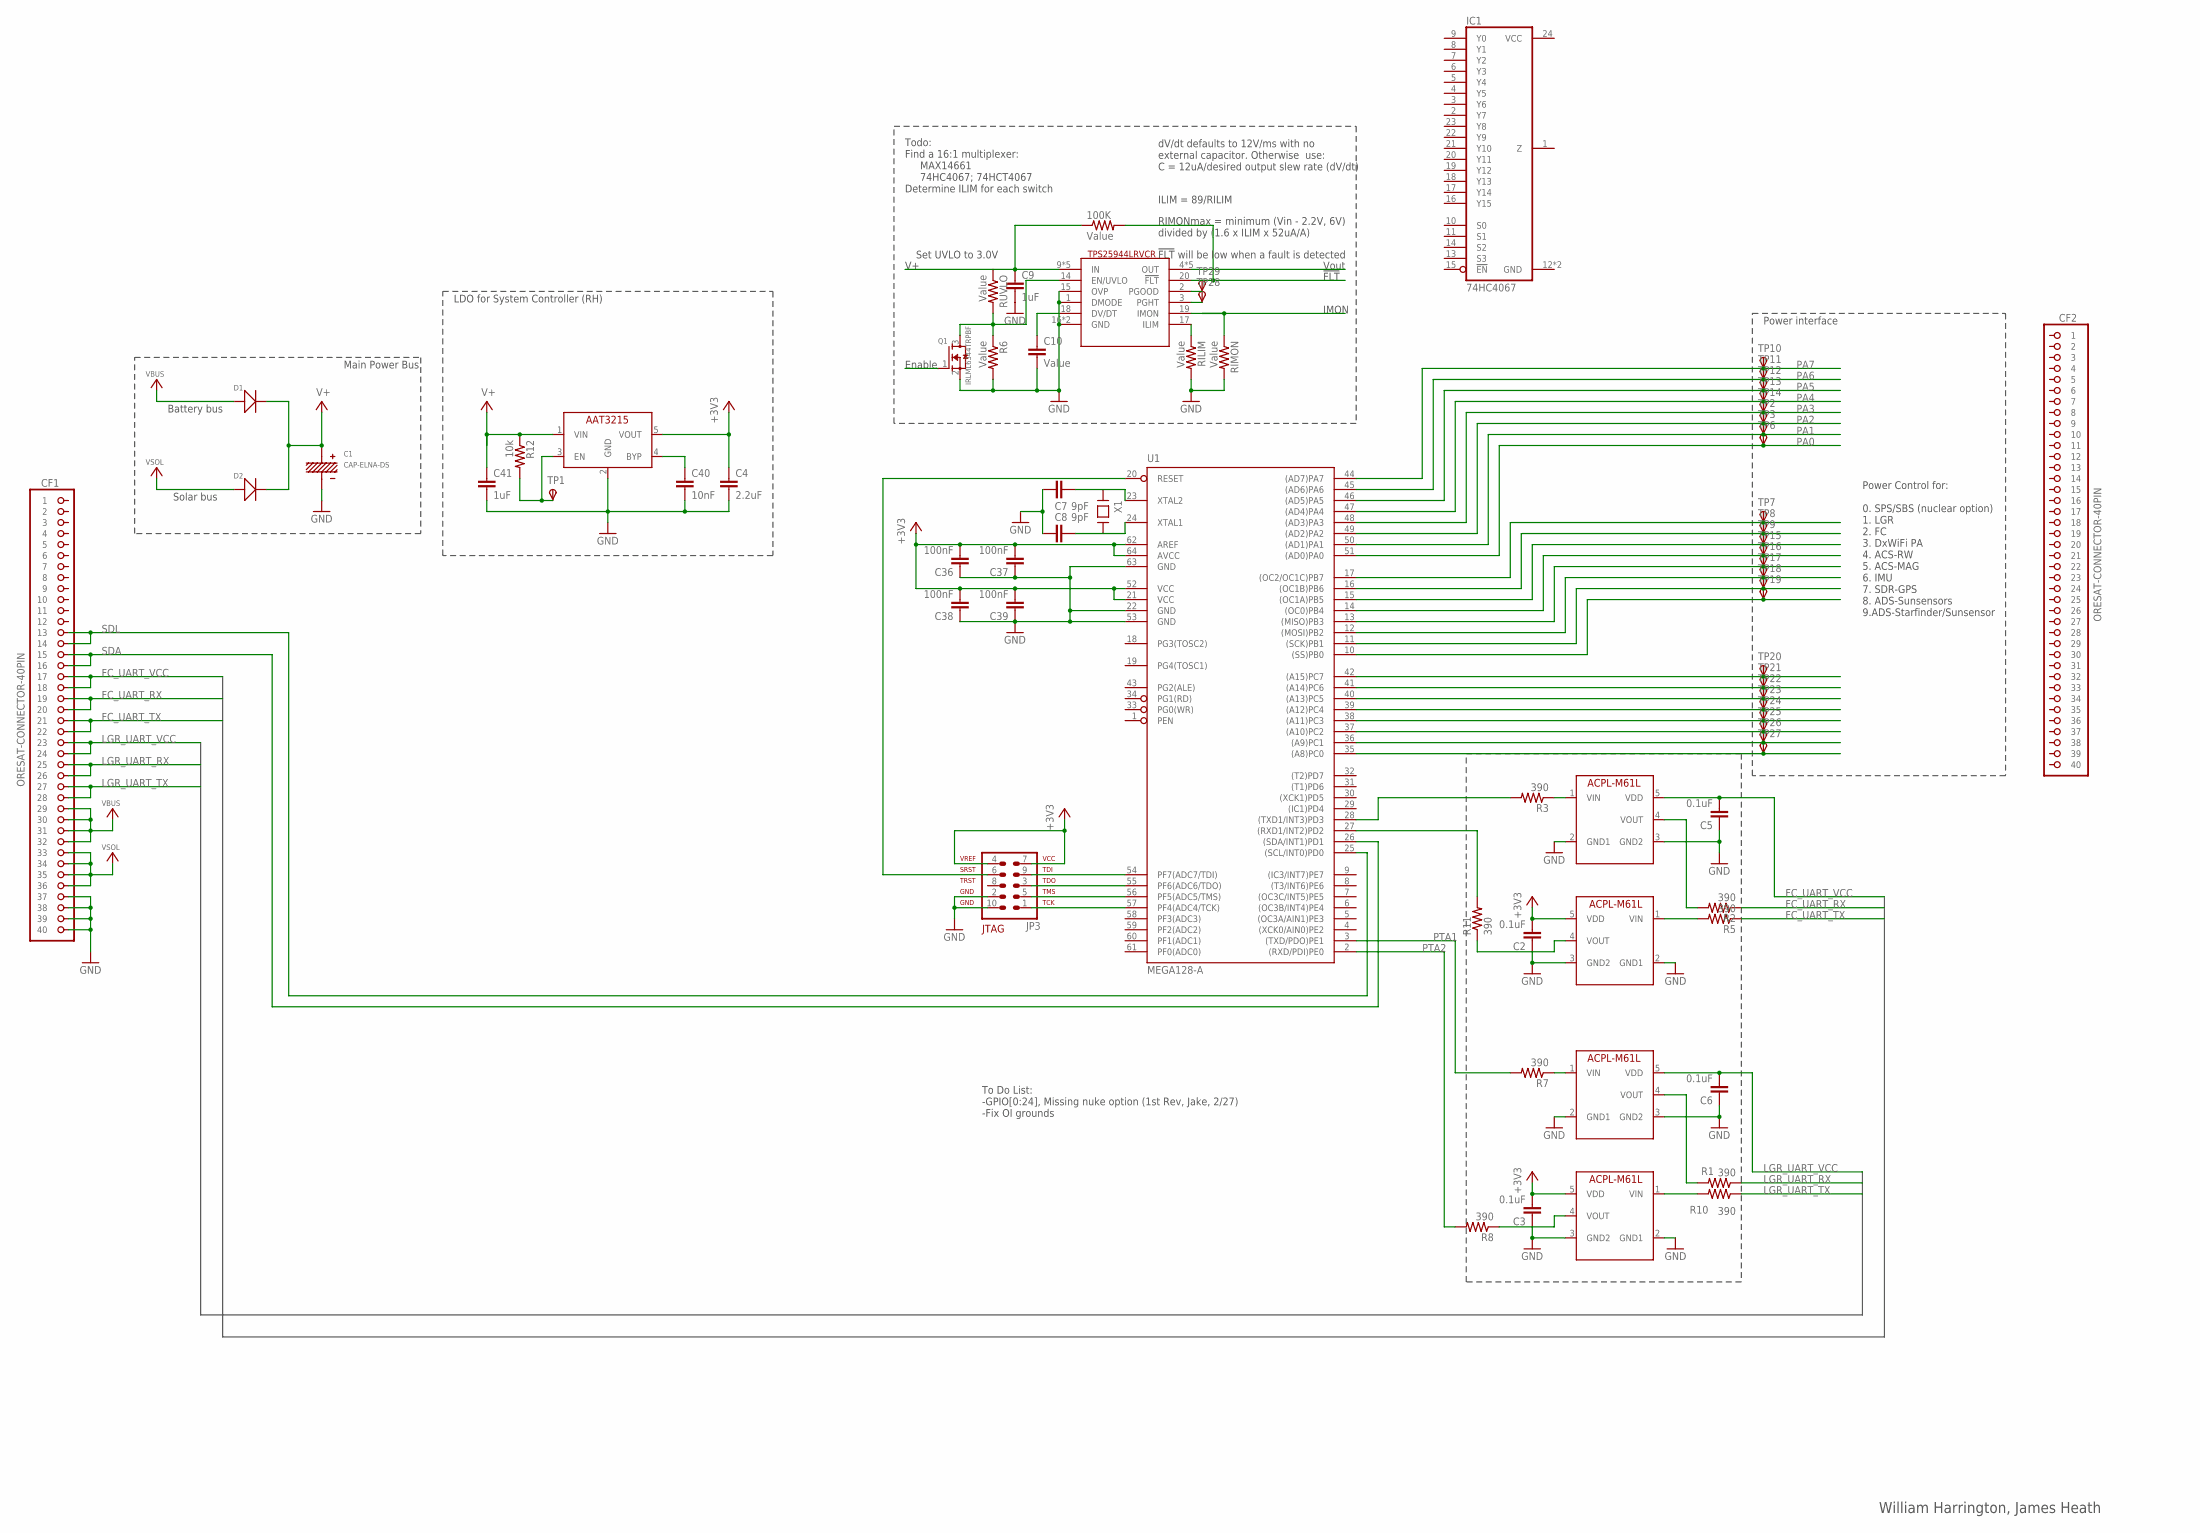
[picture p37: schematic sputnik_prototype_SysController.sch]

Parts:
100K: Value; .0603-B-NOSILK
C1: CAP-ELNA-DS; CAP-ELNA-DS-SERIES
C2, C3, C5, C6: 0.1uF; .0603-B-NOSILK
C4: 2.2uF; .0402-B-NOSILK
C7, C8: 9pF; .0603-B-NOSILK
C9, C41: 1uF; .0402-B-NOSILK
C10: Value; .0402-B-NOSILK
C36, C37, C38, C39: 100nF; .0603-B-NOSILK
C40: 10nF; .0402-B-NOSILK
CF1, CF2: ORESAT-CONNECTOR-40PIN; HARWIN-ARCHER-M50-3202045
D1, D2: SMD-DIODE-SCHOTTKY-40V-5A(DO-214AB)-SSC53L; DO-214AB
IC1: 74HC4067; QFN-24
JP3: AVR-JTAG-10
Q1: IRLML6344TRPBF; SOT23
R1, R2, R3, R5, R7, R8, R10, R11: 390; .0603-B-NOSILK
R6: Value; .0603-B-NOSILK
R12: 10k; .0603-B-NOSILK
RILIM: Value; .0603-B-NOSILK
RIMON: Value; .0603-B-NOSILK
RUVLO: Value; .0603-B-NOSILK
SW1: TPS25944LRVCRWQFN-20-3X4; QFN-20-L
TP1, TP2, TP3, TP6, TP7, TP8, TP9, TP10, TP11, TP12, TP13, TP14, TP15, TP16, TP17, TP18, TP19, TP20, TP21, TP22, TP23, TP24, TP25, TP26, TP27, TP28, TP29: TPSPAD1-13; P1-13
U1: MEGA128-A; TQFP64
U$1, U$2, U$3, U$4: ACPL-M61L
U$8: AAT3215
X1: CRYSTAL-ABRACON-ABM3-SMD

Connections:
+3V3: C2.2, C3.2, C4.1, C36.2, C37.2, C38.2, C39.2, JP3.4, JP3.7, U1.21 (VCC), U1.52 (VCC), U1.62 (AREF), U1.64 (AVCC), U$2.5 (VDD), U$4.5 (VDD), U$8.5 (VOUT)
FC_UART_RX: CF1.P$19 (19), CF1.P$20 (20), R2.1
FC_UART_TX: CF1.P$21 (21), CF1.P$22 (22), R5.1
FC_UART_VCC: C5.2, CF1.P$17 (17), CF1.P$18 (18), U$1.5 (VDD)
GND: C1.-, C2.1, C3.1, C4.2, C5.1, C6.1, C7.1, C8.1, C9.2, C10.2, C36.1, C37.1, C38.1, C39.1, C40.2, C41.2, CF1.P$37 (37), CF1.P$38 (38), CF1.P$39 (39), CF1.P$40 (40), JP3.2, JP3.10, Q1.2 (S), R6.2, RILIM.2, RIMON.2, SW1.1 (DMODE), SW1.15 (OVP), SW1.16 (GND), SW1.21 (GND), U1.22 (GND), U1.53 (GND), U1.63 (GND), U$1.2 (GND1), U$1.3 (GND2), U$2.3 (GND2), U$3.2 (GND1), U$3.3 (GND2), U$4.2 (GND1), U$4.3 (GND2), U$8.2 (GND)
LGR_UART_RX: CF1.P$25 (25), CF1.P$26 (26), R1.1
LGR_UART_TX: CF1.P$27 (27), CF1.P$28 (28), R10.1
LGR_UART_VCC: C6.2, CF1.P$23 (23), CF1.P$24 (24), U$3.5 (VDD)
unnamed: C8.2, U1.24 (XTAL1), X1.P$2
unnamed: 100K.1, C9.1, RUVLO.1, SW1.9 (IN), SW1.10 (IN), SW1.11 (IN), SW1.12 (IN), SW1.13 (IN)
unnamed: SW1.4 (OUT), SW1.5 (OUT), SW1.6 (OUT), SW1.7 (OUT), SW1.8 (OUT)
unnamed: R7.1, U$3.1 (VIN)
unnamed: R2.2, U$1.4 (VOUT)
unnamed: R3.1, U$1.1 (VIN)
unnamed: R5.2, U$2.1 (VIN)
unnamed: Q1.3 (D), R6.1, RUVLO.2, SW1.14 (EN/UVLO)
unnamed: R3.2, U1.28 ((TXD1/INT3)PD3)
unnamed: JP3.1, U1.57 (PF4(ADC4/TCK))
unnamed: JP3.3, U1.55 (PF6(ADC6/TDO))
unnamed: JP3.5, U1.56 (PF5(ADC5/TMS))
unnamed: JP3.9, U1.54 (PF7(ADC7/TDI))
unnamed: JP3.6, U1.20 (RESET)
unnamed: R1.2, U$3.4 (VOUT)
unnamed: C7.2, U1.23 (XTAL2), X1.P$1
unnamed: R8.1, U$4.4 (VOUT)
unnamed: R11.2, U1.27 ((RXD1/INT2)PD2)
unnamed: R10.2, U$4.1 (VIN)
unnamed: RILIM.1, SW1.17 (ILIM)
unnamed: R12.2, TP1.TP, U$8.3 (EN)
unnamed: C40.1, U$8.4 (BYP)
unnamed: R11.1, U$2.4 (VOUT)
unnamed: SW1.2 (PGOOD), TP29.TP
unnamed: RIMON.1, SW1.19 (IMON)
unnamed: SW1.3 (PGHT), TP28.TP
unnamed: 100K.2, SW1.20 (!FLT)
unnamed: C10.1, SW1.18 (DV/DT)
unnamed: C41.1, R12.1, U$8.1 (VIN)
PA0: TP6.TP, U1.51 ((AD0)PA0)
PA1: TP3.TP, U1.50 ((AD1)PA1)
PA2: TP2.TP, U1.49 ((AD2)PA2)
PA3: TP14.TP, U1.48 ((AD3)PA3)
PA4: TP13.TP, U1.47 ((AD4)PA4)
PA5: TP12.TP, U1.46 ((AD5)PA5)
PA6: TP11.TP, U1.45 ((AD6)PA6)
PA7: TP10.TP, U1.44 ((AD7)PA7)
PB0: TP19.TP, U1.10 ((SS)PB0)
PB1: TP18.TP, U1.11 ((SCK)PB1)
PB2: TP17.TP, U1.12 ((MOSI)PB2)
PB3: TP16.TP, U1.13 ((MISO)PB3)
PB4: TP15.TP, U1.14 ((OC0)PB4)
PB5: TP9.TP, U1.15 ((OC1A)PB5)
PB6: TP8.TP, U1.16 ((OC1B)PB6)
PB7: TP7.TP, U1.17 ((OC2/OC1C)PB7)
PC0: TP27.TP, U1.35 ((A8)PC0)
PC1: TP26.TP, U1.36 ((A9)PC1)
PC2: TP25.TP, U1.37 ((A10)PC2)
PC3: TP24.TP, U1.38 ((A11)PC3)
PC4: TP23.TP, U1.39 ((A12)PC4)
PC5: TP22.TP, U1.40 ((A13)PC5)
PC6: TP21.TP, U1.41 ((A14)PC6)
PC7: TP20.TP, U1.42 ((A15)PC7)
PTA1: R7.2, U1.3 ((TXD/PDO)PE1)
PTA2: R8.2, U1.2 ((RXD/PDI)PE0)
SDA: CF1.P$15 (15), CF1.P$16 (16), U1.26 ((SDA/INT1)PD1)
SDL: CF1.P$13 (13), CF1.P$14 (14), U1.25 ((SCL/INT0)PD0)
V+: C1.+, D1.2 (-), D2.2 (-)
VBUS: CF1.P$29 (29), CF1.P$30 (30), CF1.P$31 (31), CF1.P$32 (32), D1.1 (+)
VSOL: CF1.P$33 (33), CF1.P$34 (34), CF1.P$35 (35), CF1.P$36 (36), D2.1 (+)

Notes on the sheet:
William Harrington, James Heath
Power interface
To Do List: -GPIO[0:24], Missing nuke option (1st Rev, Jake, 2/27) -Fix OI grounds
LDO for System Controller (RH)
Main Power Bus
Battery bus
Solar bus
Power Control for: 0. SPS/SBS (nuclear option) 1. LGR 2. FC 3. DxWiFi PA 4. ACS-RW 5. ACS-MAG 6. IMU 7. SDR-GPS 8. ADS-Sunsensors 9.ADS-Starfinder/Sunsensor
Todo: Find a 16:1 multiplexer: MAX14661 74HC4067; 74HCT4067 Determine ILIM for each switch
dV/dt defaults to 12V/ms with no external capacitor. Otherwise use: C = 12uA/desired output slew rate (dV/dt)
RIMONmax = minimum (Vin - 2.2V, 6V) divided by (1.6 x ILIM x 52uA/A)
ILIM = 89/RILIM
!FLT! will be low when a fault is detected
Vout
!FLT
Enable
IMON
Set UVLO to 3.0V

Board: 4 copper layers, 73 parts (0 on the bottom side), 68 nets, no tracks yet.

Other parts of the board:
U$5: ORESAT-CARD-V0.3

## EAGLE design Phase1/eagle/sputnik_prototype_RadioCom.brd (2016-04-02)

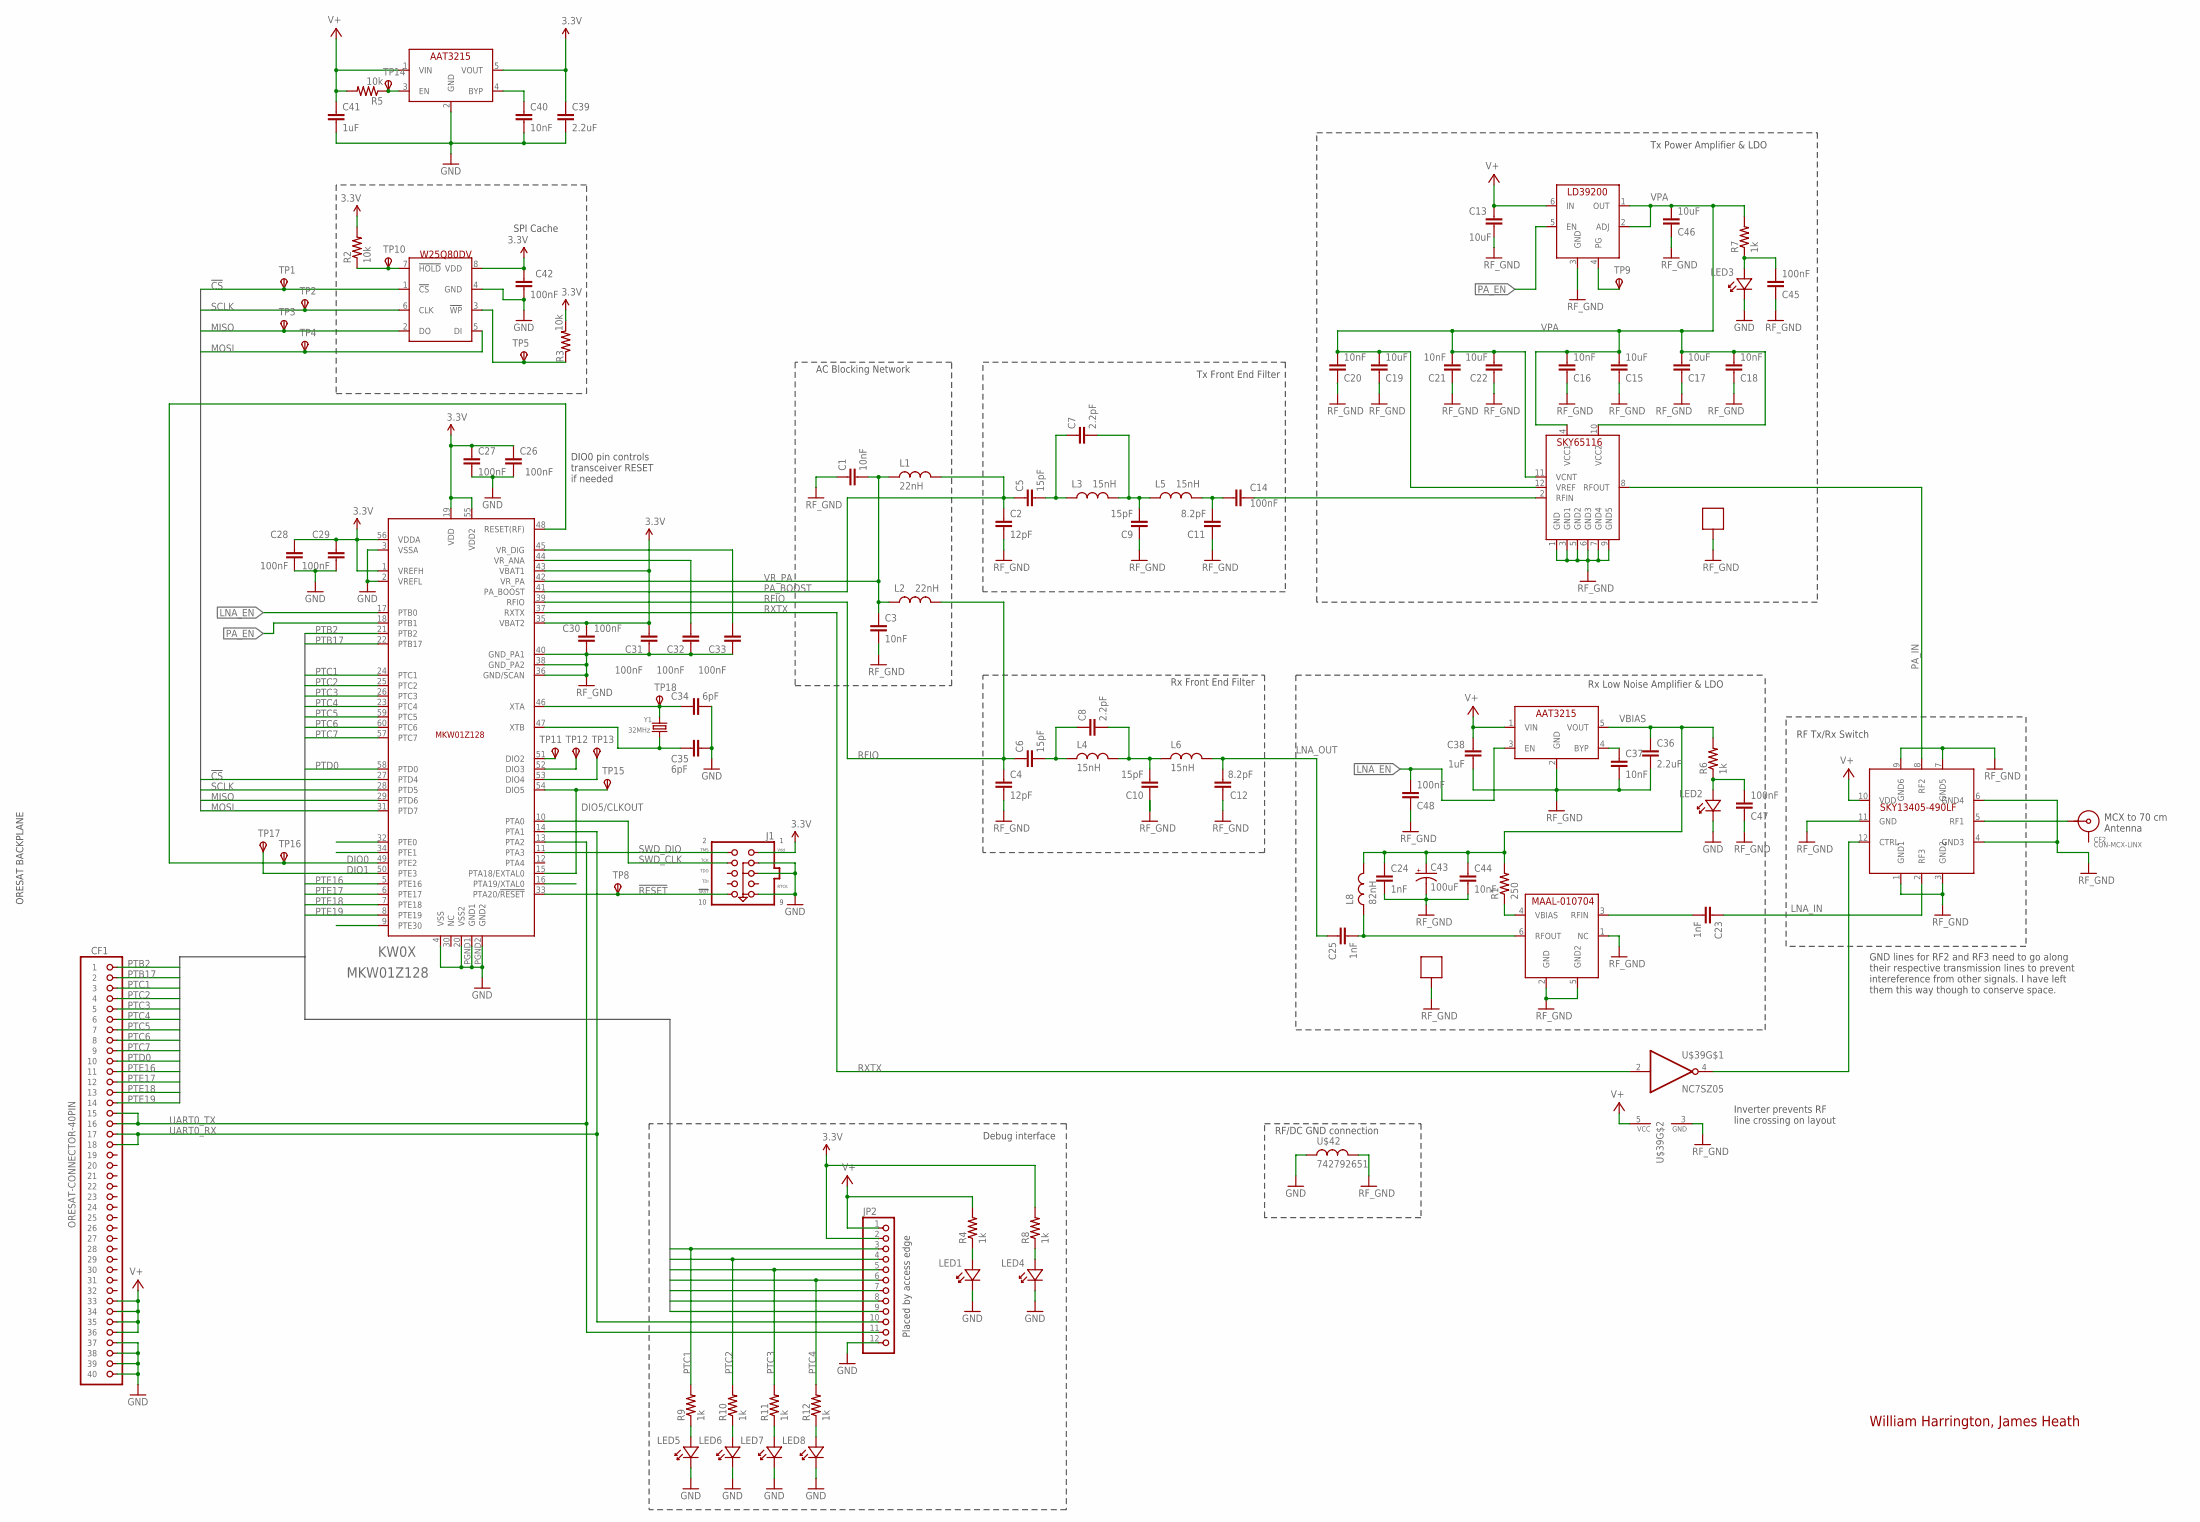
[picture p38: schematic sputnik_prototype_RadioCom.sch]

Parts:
C1, C3, C16, C18, C20, C21: 10nF; .0603-B-NOSILK
C2, C4: 12pF; .0603-B-NOSILK
C5, C6, C9, C10: 15pF; .0603-B-NOSILK
C7, C8: 2.2pF; .0603-B-NOSILK
C11, C12: 8.2pF; .0603-B-NOSILK
C13, C15, C17, C19, C22, C46: 10uF; .0603-B-NOSILK
C14, C26, C27, C28, C29, C30, C31, C32, C33, C42, C45, C47, C48: 100nF; .0603-B-NOSILK
C23, C24, C25: 1nF; .0402-B-NOSILK
C34, C35: 6pF; .0603-B-NOSILK
C36, C39: 2.2uF; .0402-B-NOSILK
C37, C40, C44: 10nF; .0402-B-NOSILK
C38, C41: 1uF; .0402-B-NOSILK
C43: 100uF; CT6032
CF1: ORESAT-CONNECTOR-40PIN; HARWIN-ARCHER-M50-3202045
CF2: CON-MCX-LINX; CON-MCX-LINX-CONMCX003.062
J1: JTAG_ARM-10-50MIL; PINHEADER-2X5-0.05+POL+SILK
JP2: PINHD-1X12; 1X12
KW0X: MKW01Z128; MPN MKW01Z128CHN
L1, L2: 22nH; .0603-B-NOSILK
L3, L4, L5, L6: 15nH; .0603-B-NOSILK
L8: 82nH; .0603-B-NOSILK
LED1, LED2, LED3, LED4, LED5, LED6, LED7, LED8: LED-0603
LNA: MAAL-010704; MPN MAAL-010704-TR3000
PA: SKY65116; MPN SKY65116
R1: 250; .0603-B-NOSILK
R2, R3, R5: 10k; .0603-B-NOSILK
R4, R6, R7, R8, R9, R10, R11, R12: 1k; .0603-B-NOSILK
SH1, SH2: BMI-S-202-SHIELD; BMI-S-202
TP1, TP2, TP3, TP4, TP5, TP8, TP9, TP10, TP11, TP12, TP13, TP14, TP15, TP16, TP17, TP18: TPSPAD1-13; P1-13
TRSWITCH: SKY13405-490LF; MPN SKY13405-490LF
U$1: W25Q80DV
U$7, U$8: AAT3215
U$9: LD39200
U$39: NC7SZ05
U$42: 742792651; .0603-B-NOSILK
Y1: 32MHz; CRYSTAL_2.5X2; MPN FA20H 32.0000MF12Y-W3

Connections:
3.3V: C26.1, C27.1, C28.2, C29.2, C30.2, C31.2, C39.1, C42.2, J1.1 (VDD), JP2.2, KW0X.1 (VREFH), KW0X.19 (VDD), KW0X.35 (VBAT2), KW0X.43 (VBAT1), KW0X.55 (VDD2), KW0X.56 (VDDA), R2.2, R3.2, R8.2, U$1.8 (VDD), U$8.5 (VOUT)
!CS: KW0X.27 (PTD4), TP1.TP, U$1.1 (!CS)
!HOLD: R2.1, TP10.TP, U$1.7 (!HOLD)
!RESET: J1.10 (SRST), KW0X.33 (PTA20/!RESET), TP8.TP
ASD: C47.1
DIO0: KW0X.48 (RESET(RF)), KW0X.49 (PTE2), TP16.TP
DIO1: KW0X.50 (PTE3), TP17.TP
DIO5/CLKOUT: KW0X.15 (PTA18/EXTAL0), KW0X.54 (DIO5), TP15.TP
GND: C26.2, C27.2, C28.1, C29.1, C34.1, C35.1, C36.2, C37.2, C38.2, C39.2, C40.2, C41.2, C42.1, C48.1, CF1.P$37 (37), CF1.P$38 (38), CF1.P$39 (39), CF1.P$40 (40), J1.3 (GND3), J1.5 (GND5), J1.9 (GND9), JP2.12, KW0X.2 (VREFL), KW0X.3 (VSSA), KW0X.4 (VSS), KW0X.20 (VSS2), KW0X.PGND1 (GND1), KW0X.PGND2 (GND2), LED1.K, LED2.K, LED3.K, LED4.K, LED5.K, LED6.K, LED7.K, LED8.K, LNA.1 (NC), TRSWITCH.11 (GND), U$1.4 (GND), U$7.2 (GND), U$8.2 (GND), U$42.1
LNA_EN: C48.2, KW0X.17 (PTB0), U$7.3 (EN)
LNA_IN: C23.1, TRSWITCH.2 (RF3)
LNA_OUT: C12.2, C25.1, L6.2
MISO: KW0X.29 (PTD6), TP3.TP, U$1.2 (DO)
MOSI: KW0X.31 (PTD7), TP4.TP, U$1.5 (DI)
unnamed: C37.1, U$7.4 (BYP)
unnamed: TRSWITCH.12 (CTRL), U$39.4 (OUT)
unnamed: KW0X.51 (DIO2), TP11.TP
unnamed: TP9.TP, U$9.4 (PG)
unnamed: KW0X.52 (DIO3), TP12.TP
unnamed: C34.2, KW0X.46 (XTA), TP18.TP, Y1.1
unnamed: C25.2, L8.1, LNA.6 (RFOUT)
unnamed: C35.2, KW0X.47 (XTB), Y1.3 (2)
unnamed: KW0X.53 (DIO4), TP13.TP
unnamed: C5.2, C7.1, L3.1
unnamed: R3.1, TP5.TP, U$1.3 (!WP)
unnamed: R5.1, TP14.TP, U$8.3 (EN)
unnamed: C40.1, U$8.4 (BYP)
unnamed: LED1.A, R4.1
unnamed: LED5.A, R9.1
unnamed: C7.2, C9.2, L3.2, L5.1
unnamed: C11.2, C14.2, L5.2
unnamed: C6.2, C8.1, L4.1
unnamed: C8.2, C10.2, L4.2, L6.1
unnamed: LED6.A, R10.1
unnamed: LED7.A, R11.1
unnamed: LED4.A, R8.1
unnamed: LED8.A, R12.1
unnamed: C23.2, LNA.3 (RFIN)
unnamed: LNA.4 (VBIAS), R1.1
unnamed: CF2.CENTER, TRSWITCH.5 (RF1)
unnamed: C32.2, KW0X.44 (VR_ANA)
unnamed: C33.2, KW0X.45 (VR_DIG)
unnamed: C14.1, PA.2 (RFIN)
PA_BOOST: C2.1, C5.1, KW0X.41 (PA_BOOST), L1.2
PA_EN: KW0X.18 (PTB1), U$9.5 (EN)
PA_IN: PA.8 (RFOUT), TRSWITCH.8 (RF2)
PTA19: KW0X.16 (PTA19/XTAL0)
PTB2: CF1.P$1 (1), KW0X.21 (PTB2)
PTB17: CF1.P$2 (2), KW0X.22 (PTB17)
PTC1: CF1.P$3 (3), JP2.3, KW0X.24 (PTC1), R9.2
PTC2: CF1.P$4 (4), JP2.4, KW0X.25 (PTC2), R10.2
PTC3: CF1.P$5 (5), JP2.5, KW0X.26 (PTC3), R11.2
PTC4: CF1.P$6 (6), JP2.6, KW0X.23 (PTC4), R12.2
PTC5: CF1.P$7 (7), JP2.7, KW0X.59 (PTC5)
PTC6: CF1.P$8 (8), JP2.8, KW0X.60 (PTC6)
PTC7: CF1.P$9 (9), JP2.9, KW0X.57 (PTC7)
PTD0: CF1.P$10 (10), KW0X.58 (PTD0)
PTE0: KW0X.32 (PTE0)
PTE1: KW0X.34 (PTE1)
PTE16: CF1.P$11 (11), KW0X.5 (PTE16)
PTE17: CF1.P$12 (12), KW0X.6 (PTE17)
PTE18: CF1.P$13 (13), KW0X.7 (PTE18)
PTE19: CF1.P$14 (14), KW0X.8 (PTE19)
PTE30: KW0X.9 (PTE30)
RFIO: C4.1, C6.1, KW0X.39 (RFIO), L2.2
RF_GND: C1.1, C2.2, C3.2, C4.2, C9.1, C10.1, C11.1, C12.1, C13.1, C15.1, C16.1, C17.1, C18.1, C19.1, C20.1, C21.1, C22.1, C24.2, C30.1, C31.1, C32.1, C33.1, C43.-, C44.2, C45.1, C46.1, KW0X.36 (GND/SCAN), KW0X.38 (GND_PA2), KW0X.40 (GND_PA1), LNA.2 (GND), LNA.5 (GND2), PA.1 (GND), PA.3 (GND1), PA.5 (GND2), PA.6 (GND3), PA.7 (GND4), PA.9 (GND5), SH1.P$1, SH1.P$2, SH1.P$3, SH1.P$4, SH1.P$5, SH1.P$6, SH1.P$7, SH1.P$8, SH1.P$9, SH1.P$10, SH1.P$11, SH1.P$12, SH2.P$1, SH2.P$2, SH2.P$3, SH2.P$4, SH2.P$5, SH2.P$6, SH2.P$7, SH2.P$8, SH2.P$9, SH2.P$10, SH2.P$11, SH2.P$12, TRSWITCH.1 (GND1), TRSWITCH.3 (GND2), TRSWITCH.4 (GND3), TRSWITCH.6 (GND4), TRSWITCH.7 (GND5), TRSWITCH.9 (GND6), U$9.3 (GND), U$39.3 (GND), U$42.2
RXTX: KW0X.37 (RXTX), U$39.2 (IN)
SCLK: KW0X.28 (PTD5), TP2.TP, U$1.6 (CLK)
SWD_CLK: J1.4 (TCK), KW0X.10 (PTA0)
SWD_DIO: J1.2 (TMS), KW0X.11 (PTA3)
UART0_RX: CF1.P$17 (17), CF1.P$18 (18), JP2.10, KW0X.14 (PTA1)
UART0_TX: CF1.P$15 (15), CF1.P$16 (16), JP2.11, KW0X.13 (PTA2)
V+: C13.2, C38.1, C41.1, CF1.P$33 (33), CF1.P$34 (34), CF1.P$35 (35), CF1.P$36 (36), JP2.1, R4.2, R5.2, TRSWITCH.10 (VDD), U$7.1 (VIN), U$8.1 (VIN), U$9.6 (IN), U$39.5 (VCC)
VBIAS: C24.1, C36.1, C43.+, C44.1, L8.2, R1.2, R6.2, U$7.5 (VOUT)
VPA: C15.2, C16.2, C17.2, C18.2, C19.2, C20.2, C21.2, C22.2, C46.2, PA.4 (VCC1), PA.10 (VCC2), PA.11 (VCNT), PA.12 (VREF), R7.2, U$9.1 (OUT), U$9.2 (ADJ)
VR_PA: C1.2, C3.1, KW0X.42 (VR_PA), L1.1, L2.1
V_LNA_FILTERED: C47.2, LED2.A, R6.1
V_PA_FILTERED: C45.2, LED3.A, R7.1

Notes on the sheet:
William Harrington, James Heath
AC Blocking Network
Tx Front End Filter
Tx Power Amplifier & LDO
Rx Front End Filter
Rx Low Noise Amplifier & LDO
RF Tx/Rx Switch
MCX to 70 cm Antenna
GND lines for RF2 and RF3 need to go along their respective transmission lines to prevent intereference from other signals. I have left them this way though to conserve space.
SPI Cache
RF/DC GND connection
Debug interface
Placed by access edge
ORESAT BACKPLANE
DIO0 pin controls transceiver RESET if needed
Inverter prevents RF line crossing on layout

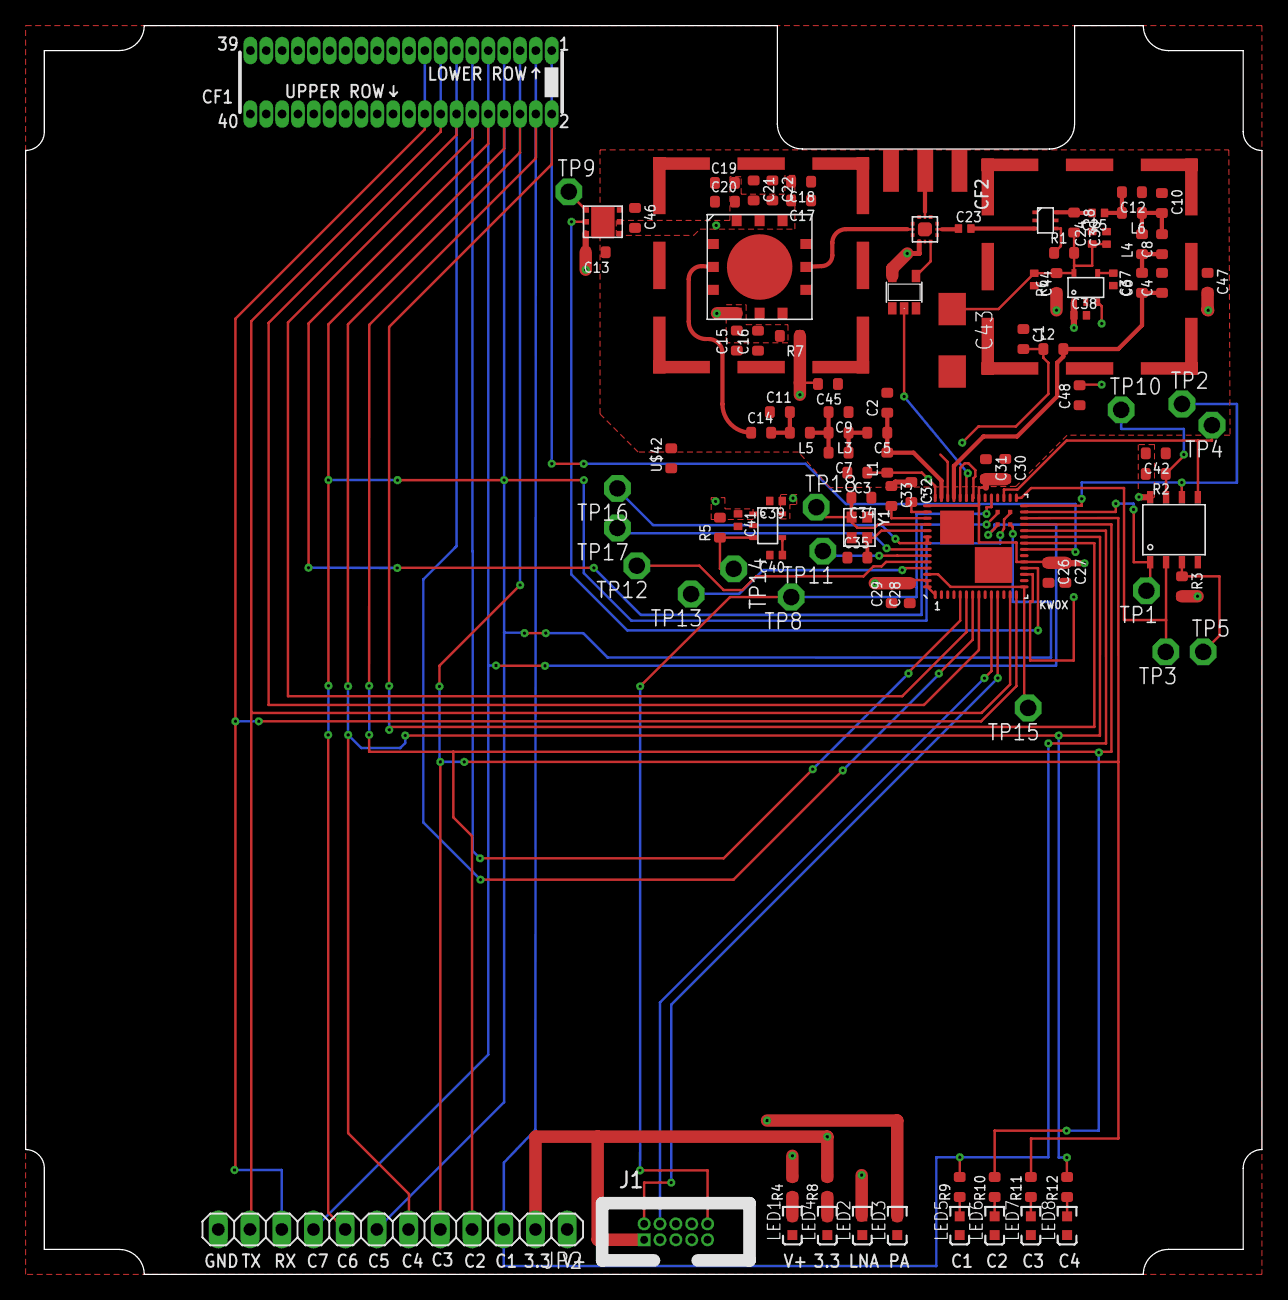
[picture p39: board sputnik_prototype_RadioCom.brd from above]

Board: 4 copper layers, 99.0 x 100.0 mm, 109 parts (0 on the bottom side), 73 nets.

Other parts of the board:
U$35: ORESAT-CARD-RF-V0.3

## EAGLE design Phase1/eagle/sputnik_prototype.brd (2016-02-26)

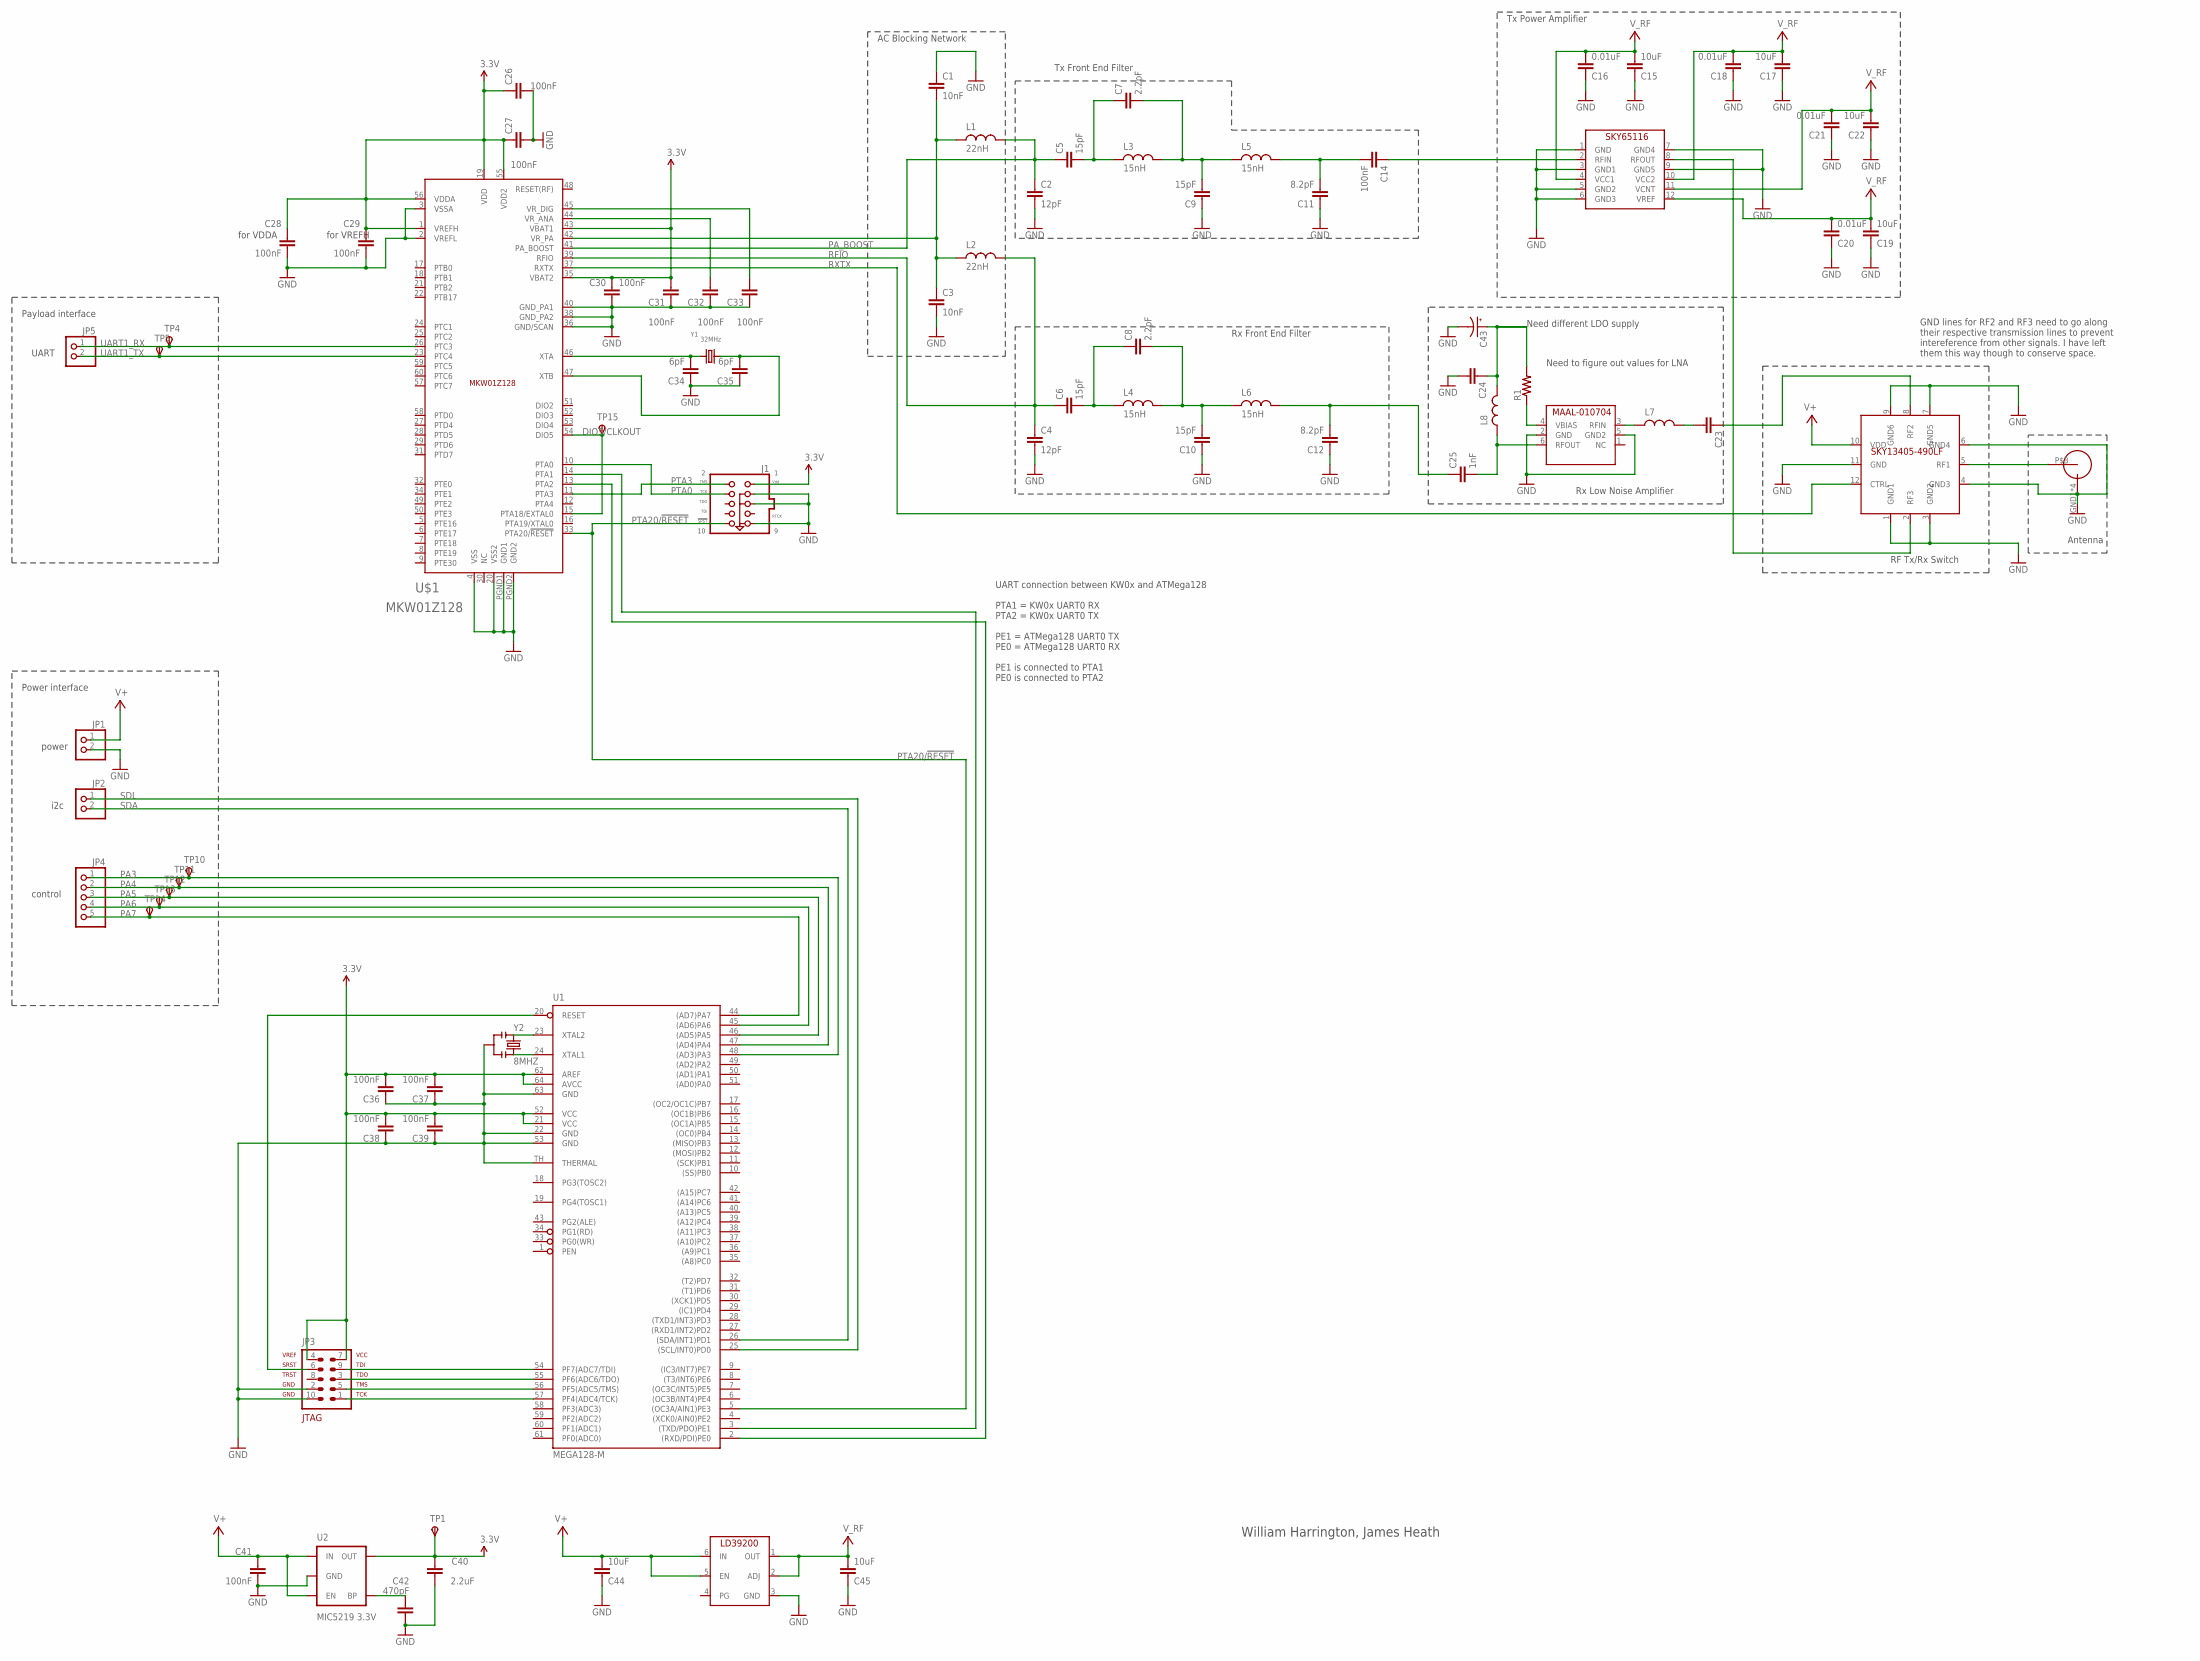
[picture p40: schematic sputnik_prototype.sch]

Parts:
C1, C3: 10nF; .0603-B-NOSILK
C2, C4: 12pF; .0603-B-NOSILK
C5, C6, C9, C10: 15pF; .0603-B-NOSILK
C7, C8: 2.2pF; .0603-B-NOSILK
C11, C12: 8.2pF; .0603-B-NOSILK
C14, C26, C27, C28, C29, C30, C31, C32, C33, C36, C37, C38, C39, C41: 100nF; .0603-B-NOSILK
C15, C17, C19, C22, C44, C45: 10uF; .0603-B-NOSILK
C16, C18, C20, C21: 0.01uF; .0603-B-NOSILK
C23, C24: C-EU0402-B-NOSILK; .0402-B-NOSILK
C25: 1nF; .0402-B-NOSILK
C34, C35: 6pF; .0603-B-NOSILK
C40: 2.2uF; .0603-B-NOSILK
C42: 470pF; .0603-B-NOSILK
C43: CPOL-USCT6032; CT6032
J1: JTAG_ARM-10-50MIL; PINHEADER-2X5-0.05+POL+SILK
JP1, JP2, JP5: PINHD-1X2; 1X02
JP3: AVR-JTAG-10
JP4: PINHD-1X55X2MM; 1_05X2MM
L1, L2: 22nH; .0603-B-NOSILK
L3, L4, L5, L6: 15nH; .0603-B-NOSILK
L7: L-US0402-B-NOSILK; .0402-B-NOSILK
L8: L-US0603-B-NOSILK; .0603-B-NOSILK
R1: R-US_0603-B-NOSILK; .0603-B-NOSILK
TP1, TP4, TP5, TP10, TP11, TP12, TP13, TP14, TP15: TPSPAD1-13; P1-13
U1: MEGA128-M; MLF64-TH
U2: MIC5219 3.3V; SPARKFUN-POWERIC_SOT23-5
U$1: MKW01Z128
U$2: SMAJ716-ND
U$3: LD39200
U$4: MAAL-010704
U$5: SKY13405-490LF
U$6: SKY65116
Y1: 32MHz; CRYSTAL_2.5X2; MPN FA20H 32.0000MF12Y-W3
Y2: 8MHZ; SPARKFUN-FREQCTRL_RESONATOR-SMD

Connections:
3.3V: C26.1, C27.1, C28.2, C29.2, C30.2, C31.2, C36.2, C37.2, C38.2, C39.2, C40.2, J1.1 (VDD), JP3.4, JP3.7, TP1.TP, U1.21 (VCC), U1.52 (VCC), U1.62 (AREF), U1.64 (AVCC), U2.5 (OUT), U$1.1 (VREFH), U$1.19 (VDD), U$1.35 (VBAT2), U$1.43 (VBAT1), U$1.55 (VDD2), U$1.56 (VDDA)
DIO5/CLKOUT: TP15.TP, U$1.15 (PTA18/EXTAL0), U$1.54 (DIO5)
GND: C1.1, C2.2, C3.2, C4.2, C9.1, C10.1, C11.1, C12.1, C15.1, C16.1, C17.1, C18.1, C19.1, C20.1, C21.1, C22.1, C24.2, C26.2, C27.2, C28.1, C29.1, C30.1, C31.1, C32.1, C33.1, C34.1, C35.1, C36.1, C37.1, C38.1, C39.1, C40.1, C41.1, C42.1, C43.-, C44.1, C45.1, J1.3 (GND3), J1.5 (GND5), J1.9 (GND9), JP1.2, JP3.2, JP3.10, U1.22 (GND), U1.53 (GND), U1.63 (GND), U1.TH (THERMAL), U2.2 (GND), U$1.2 (VREFL), U$1.3 (VSSA), U$1.4 (VSS), U$1.20 (VSS2), U$1.36 (GND/SCAN), U$1.38 (GND_PA2), U$1.40 (GND_PA1), U$1.PGND1 (GND1), U$1.PGND2 (GND2), U$2.GND1 (OUTERCONDUCTOR), U$2.GND2 (OUTERCONDUCTOR), U$2.GND3 (OUTERCONDUCTOR), U$2.GND4 (OUTERCONDUCTOR), U$3.3 (GND), U$4.2 (GND), U$4.5 (GND2), U$5.1 (GND1), U$5.3 (GND2), U$5.4 (GND3), U$5.6 (GND4), U$5.7 (GND5), U$5.9 (GND6), U$5.11 (GND), U$6.1 (GND), U$6.3 (GND1), U$6.5 (GND2), U$6.6 (GND3), U$6.7 (GND4), U$6.9 (GND5), Y2.2
unnamed: U1.3 ((TXD/PDO)PE1), U$1.14 (PTA1)
unnamed: U1.2 ((RXD/PDI)PE0), U$1.13 (PTA2)
unnamed: C42.2, U2.4 (BP)
unnamed: C23.1, U$5.8 (RF2)
unnamed: C34.2, U$1.46 (XTA), Y1.1
unnamed: C25.2, L8.1, U$4.6 (RFOUT)
unnamed: C35.2, U$1.47 (XTB), Y1.3 (2)
unnamed: C5.2, C7.1, L3.1
unnamed: JP3.1, U1.57 (PF4(ADC4/TCK))
unnamed: JP3.3, U1.55 (PF6(ADC6/TDO))
unnamed: JP3.5, U1.56 (PF5(ADC5/TMS))
unnamed: JP3.9, U1.54 (PF7(ADC7/TDI))
unnamed: JP3.6, U1.20 (RESET)
unnamed: C7.2, C9.2, L3.2, L5.1
unnamed: C11.2, C14.2, L5.2
unnamed: C6.2, C8.1, L4.1
unnamed: C8.2, C10.2, L4.2, L6.1
unnamed: C12.2, C25.1, L6.2
unnamed: C14.1, U$6.2 (RFIN)
unnamed: U$5.2 (RF3), U$6.8 (RFOUT)
unnamed: U1.23 (XTAL2), Y2.1
unnamed: L7.1, U$4.3 (RFIN)
unnamed: C23.2, L7.2
unnamed: C24.1, C43.+, L8.2, R1.2
unnamed: R1.1, U$4.4 (VBIAS)
unnamed: C1.2, C3.1, L1.1, L2.1, U$1.42 (VR_PA)
unnamed: U$2.P$3 (CENTERCONDUCTOR), U$5.5 (RF1)
unnamed: C32.2, U$1.44 (VR_ANA)
unnamed: C33.2, U$1.45 (VR_DIG)
unnamed: U1.24 (XTAL1), Y2.3
PA3: JP4.1, TP10.TP, U1.48 ((AD3)PA3)
PA4: JP4.2, TP11.TP, U1.47 ((AD4)PA4)
PA5: JP4.3, TP12.TP, U1.46 ((AD5)PA5)
PA6: JP4.4, TP13.TP, U1.45 ((AD6)PA6)
PA7: JP4.5, TP14.TP, U1.44 ((AD7)PA7)
PA_BOOST: C2.1, C5.1, L1.2, U$1.41 (PA_BOOST)
PTA0: J1.4 (TCK), U$1.10 (PTA0)
PTA3: J1.2 (TMS), U$1.11 (PTA3)
PTA20/!RESET: J1.10 (SRST), U1.5 ((OC3A/AIN1)PE3), U$1.33 (PTA20/!RESET)
RFIO: C4.1, C6.1, L2.2, U$1.39 (RFIO)
RXTX: U$1.37 (RXTX), U$5.12 (CTRL)
SDA: JP2.2, U1.26 ((SDA/INT1)PD1)
SDL: JP2.1, U1.25 ((SCL/INT0)PD0)
UART1_RX: JP5.1, TP4.TP, U$1.26 (PTC3)
UART1_TX: JP5.2, TP5.TP, U$1.23 (PTC4)
V+: C15.2, C16.2, C17.2, C18.2, C19.2, C20.2, C21.2, C22.2, C41.2, C44.2, C45.2, JP1.1, U2.1 (IN), U2.3 (EN), U$3.1 (OUT), U$3.2 (ADJ), U$3.5 (EN), U$3.6 (IN), U$5.10 (VDD), U$6.4 (VCC1), U$6.10 (VCC2), U$6.11 (VCNT), U$6.12 (VREF)

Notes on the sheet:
William Harrington, James Heath
Power interface
AC Blocking Network
Tx Front End Filter
Tx Power Amplifier
Rx Front End Filter
Rx Low Noise Amplifier
RF Tx/Rx Switch
Antenna
for VDDA
for VREFH
i2c
power
control
UART connection between KW0x and ATMega128 PTA1 = KW0x UART0 RX PTA2 = KW0x UART0 TX PE1 = ATMega128 UART0 TX PE0 = ATMega128 UART0 RX PE1 is connected to PTA1 PE0 is connected to PTA2
Payload interface
UART
Need to figure out values for LNA
GND lines for RF2 and RF3 need to go along their respective transmission lines to prevent intereference from other signals. I have left them this way though to conserve space.
Need different LDO supply

Board: 2 copper layers, 78 parts (0 on the bottom side), 49 nets, no tracks yet.

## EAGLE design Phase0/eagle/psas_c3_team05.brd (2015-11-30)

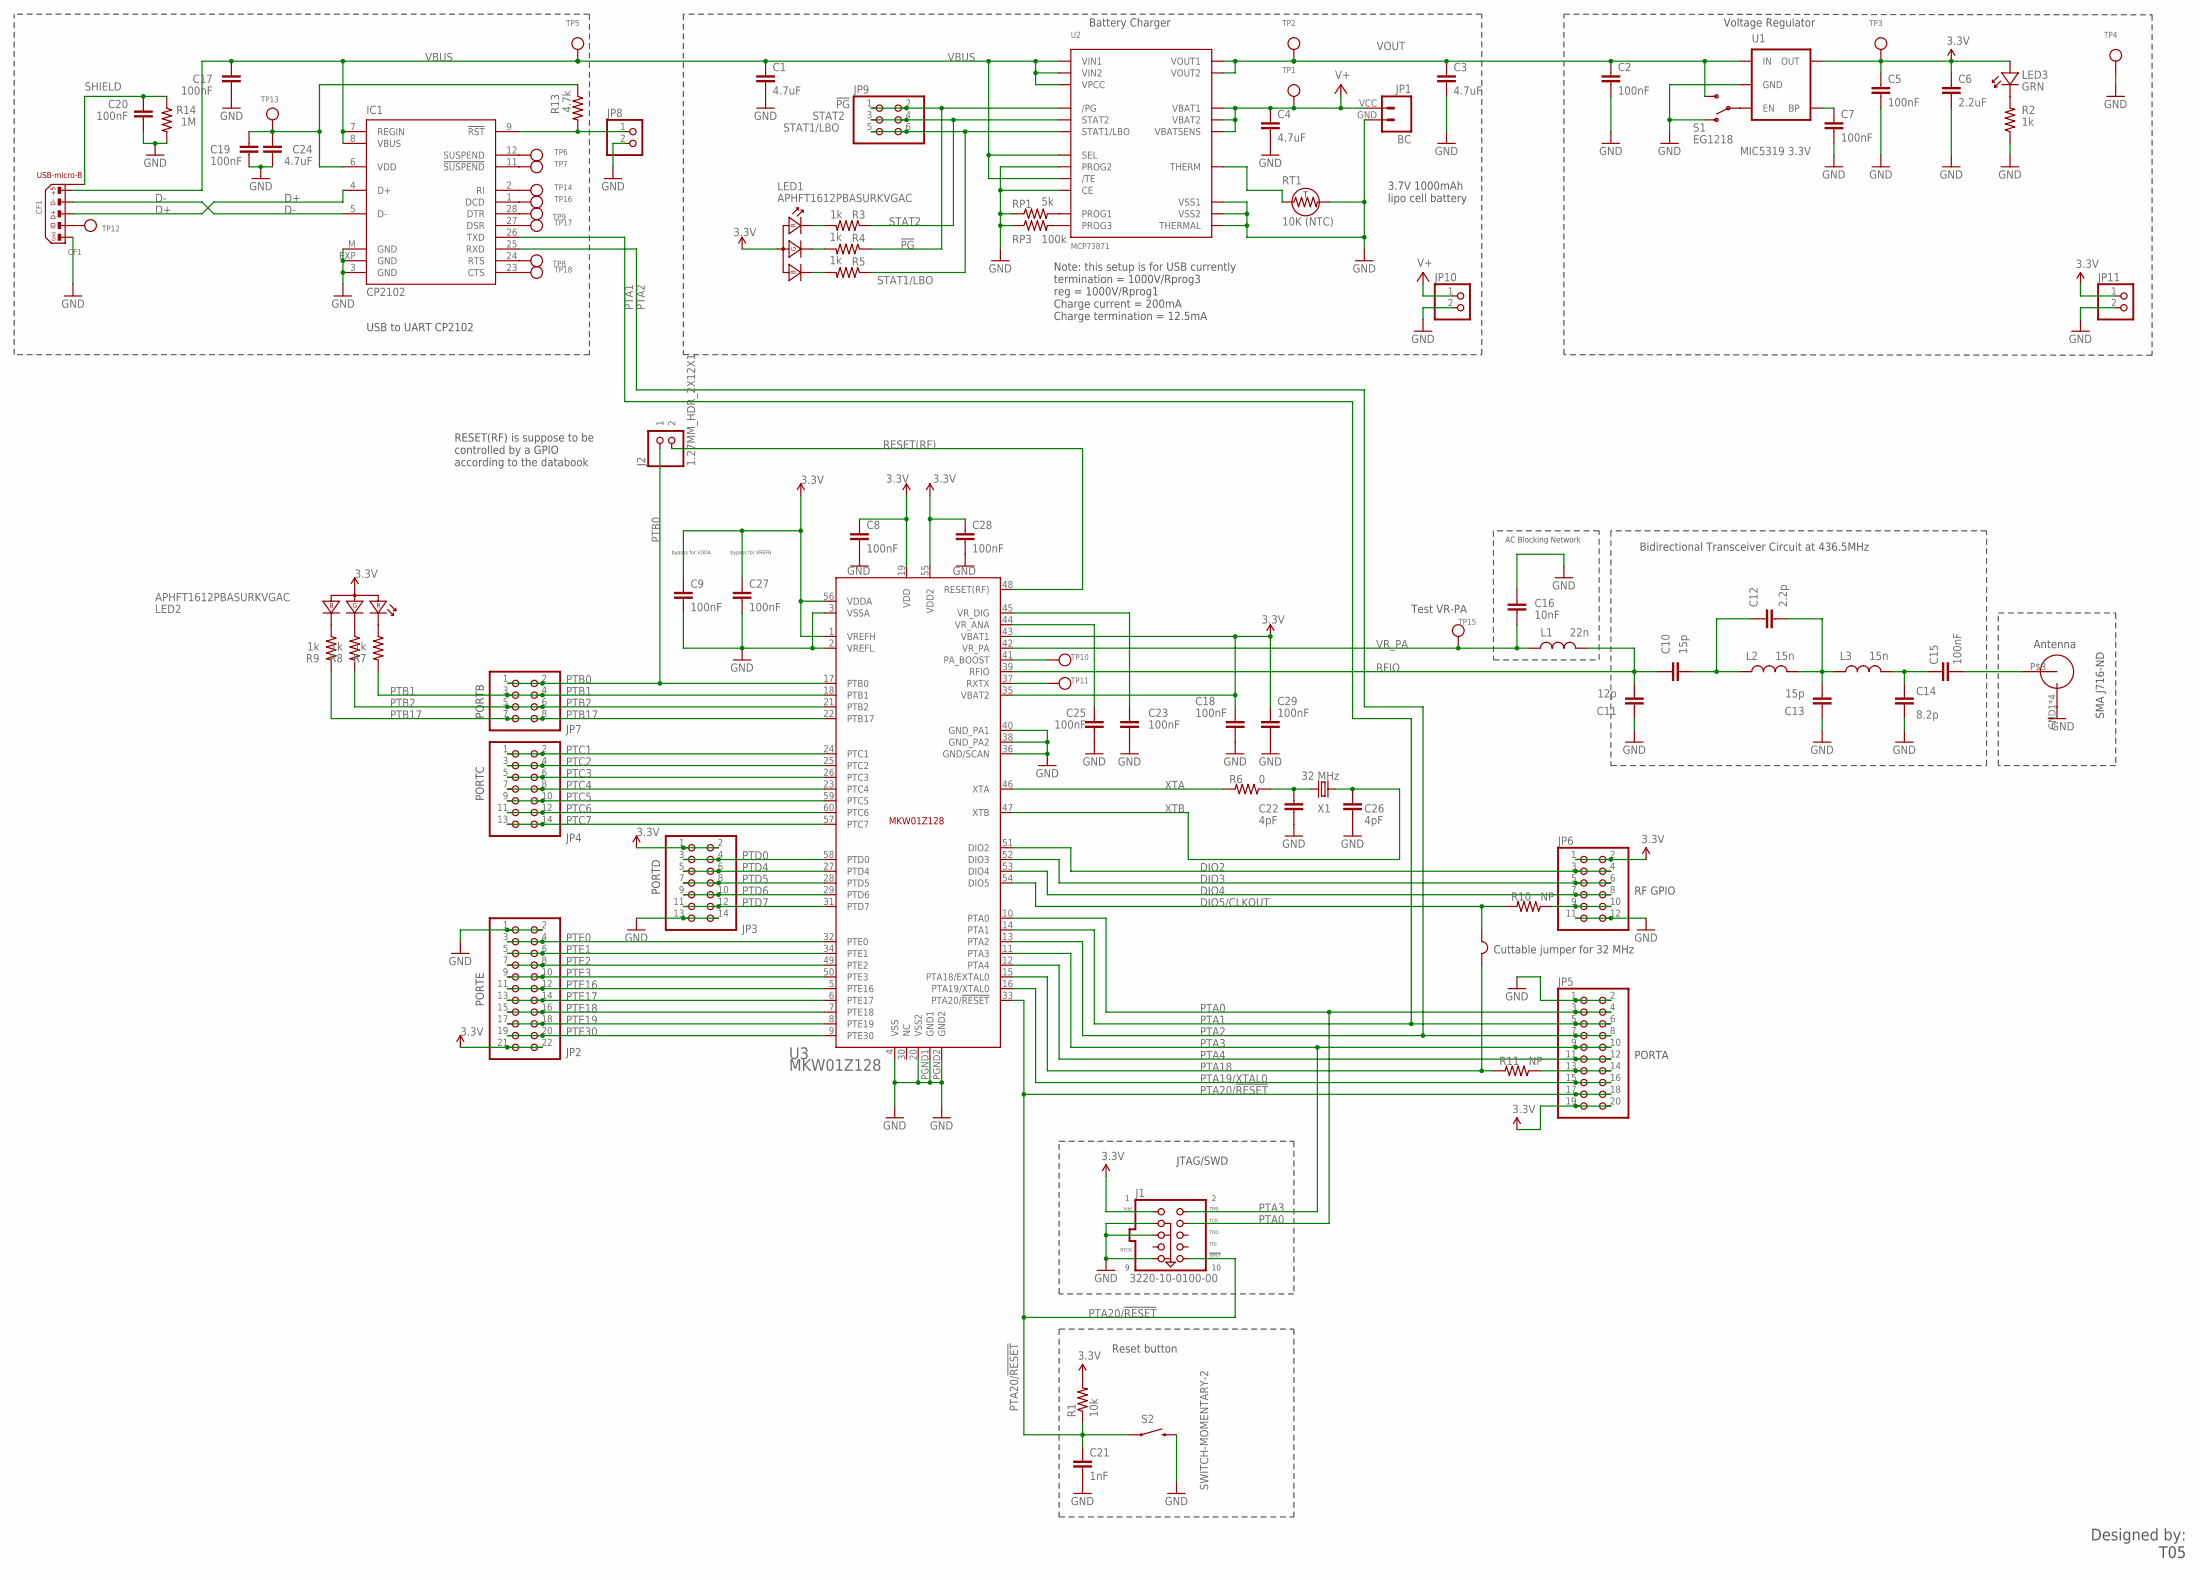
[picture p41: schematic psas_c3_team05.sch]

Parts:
C1, C3, C4, C24: 4.7uF; .0805-B-NOSILK
C2, C5, C7, C15, C17, C19, C20: 100nF; .0603-B-NOSILK
C6: 2.2uF; .0805-B-NOSILK
C8, C9, C18, C23, C25, C27, C28, C29: 100nF; .0603-B-NOSILK; MPN GRM188R71C104KA01D
C10, C13: 15p; .0603-B-NOSILK
C11: 12p; .0603-B-NOSILK
C12: 2.2p; .0603-B-NOSILK
C14: 8.2p; .0603-B-NOSILK
C16: 10nF; .0603-B-NOSILK
C21: 1nF; .0603-B-NOSILK
C22, C26: 4pF; .0603-B-NOSILK; MPN GRM1885C1H4R0CA01D
CF1: CF1; USB-MICRO-B-PTH-HIROSE
IC1: CP2102; MLP28
J1: 3220-10-0100-00; PINHEADER-2X5-0.05+POL+SILK
J2: 1.27MM_HDR_2X12X1; 1.27MM_2X1
JP1: BC; SPARKFUN-CONNECTORS_JST-2-SMD-VERT
JP2: PINHD-2X11; 2X11
JP3, JP4: PINHD-2X7; 2X07
JP5: PINHD-2X10; 2X10
JP6: PINHD-2X6; 2X06
JP7: PINHD-2X4; 2X04
JP8, JP10, JP11: PINHD-1X2; 1X02
JP9: PINHD-2X3; 2X03
L1: 22n; .0603-B-NOSILK
L2, L3: 15n; .0603-B-NOSILK
LED1, LED2: APHFT1612PBASURKVGAC; KINGBRITE_RGBLED_1.6X1.26
LED3: GRN; LED-0603
R1: 10k; .0603-B-NOSILK
R2, R3, R4, R5, R7, R8, R9: 1k; .0603-B-NOSILK
R6: 0; .0603-B-NOSILK
R10, R11: NP; .0603-B-NOSILK
R13: 4.7k; .0603-B-NOSILK
R14: 1M; .0603-B-NOSILK
RP1: 5k; .0603-B-NOSILK
RP3: 100k; .0603-B-NOSILK
RT1: 10K (NTC); R1206
S1: EG1218; SWITCH-SPDT
S2: SWITCH-MOMENTARY-2; TACTILE_SWITCH_TALL
TP1, TP2, TP3, TP4, TP5, TP6, TP7, TP8, TP9, TP10, TP11, TP12, TP13, TP14, TP15, TP16, TP17, TP18: TESTPOINTROUND0.5MM; TESTPOINT_ROUND_0.5MM
U1: MIC5319 3.3V; SPARKFUN-POWERIC_SOT23-5
U2: MCP73871; QFN20_4MM
U3: MKW01Z128
U$2: SMAJ716-ND
W1: CONNECTION-0.4; CONNECTION-BUTT-0.4
X1: 32 MHz; FC-12M

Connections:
3.3V: C5.1, C6.1, C8.1, C9.1, C18.1, C27.1, C28.1, C29.1, J1.1 (VDD), JP2.21, JP2.22, JP3.1, JP3.2, JP5.19, JP5.20, JP6.1, JP6.2, JP11.1, LED1.2 (COMMON_ANODE), LED2.2 (COMMON_ANODE), LED3.A, R1.2, TP3.P$1, U1.5 (OUT), U3.1 (VREFH), U3.19 (VDD), U3.35 (VBAT2), U3.43 (VBAT1), U3.55 (VDD2), U3.56 (VDDA)
!PG: JP9.1, JP9.2, R4.1, U2.P$6 (/PG)
CP2102_VDD: C19.1, C24.1, IC1.6 (VDD), R13.1, TP13.P$1
D+: CF1.3, IC1.4 (D+)
D-: CF1.2, IC1.5 (D-)
DIO2: JP6.3, JP6.4, U3.51 (DIO2)
DIO3: JP6.5, JP6.6, U3.52 (DIO3)
DIO4: JP6.7, JP6.8, U3.53 (DIO4)
DIO5-JMP: JP6.9, JP6.10, R10.1
DIO5/CLKOUT: R10.2, U3.54 (DIO5), W1.P1 (1)
GND: C1.2, C2.2, C3.2, C4.2, C5.2, C6.2, C7.2, C8.2, C9.2, C11.2, C13.2, C14.2, C16.1, C17.2, C18.2, C19.2, C20.2, C21.2, C22.2, C23.2, C24.2, C25.2, C26.2, C27.2, C28.2, C29.2, CF1.5, IC1.3 (GND), IC1.EXP (GND), IC1.M (GND), J1.3 (GND3), J1.5 (GND5), J1.9 (GND9), JP1.GND (1), JP2.1, JP2.2, JP3.13, JP3.14, JP5.1, JP5.2, JP6.11, JP6.12, JP8.2, JP10.2, JP11.2, R2.1, R14.2, RP1.1, RP3.1, RT1.2, S1.1 (O), S2.B2 (2), TP4.P$1, U1.2 (GND), U2.P$4 (PROG2), U2.P$10 (VSS1), U2.P$11 (VSS2), U2.P$17 (CE), U2.P$21 (THERMAL), U3.2 (VREFL), U3.3 (VSSA), U3.4 (VSS), U3.20 (VSS2), U3.36 (GND/SCAN), U3.38 (GND_PA2), U3.40 (GND_PA1), U3.PGND1 (GND1), U3.PGND2 (GND2), U$2.GND1 (OUTERCONDUCTOR), U$2.GND2 (OUTERCONDUCTOR), U$2.GND3 (OUTERCONDUCTOR), U$2.GND4 (OUTERCONDUCTOR)
unnamed: C7.1, U1.4 (BP)
unnamed: LED1.3 (RK), R3.2
unnamed: LED1.4 (GK), R4.2
unnamed: LED1.1 (BK), R5.2
unnamed: IC1.12 (SUSPEND), TP6.P$1
unnamed: RT1.1, U2.P$5 (THERM)
unnamed: IC1.11 (!SUSPEND), TP7.P$1
unnamed: S1.2, U1.3 (EN)
unnamed: RP1.2, U2.P$13 (PROG1)
unnamed: RP3.2, U2.P$12 (PROG3)
unnamed: IC1.24 (RTS), TP8.P$1
unnamed: C22.1, R6.1, X1.2
unnamed: TP10.P$1, U3.41 (PA_BOOST)
unnamed: TP11.P$1, U3.37 (RXTX)
unnamed: C12.1, C13.1, L2.2, L3.1
unnamed: C10.1, C12.2, L2.1
unnamed: C15.2, U$2.P$3 (CENTERCONDUCTOR)
unnamed: C14.1, C15.1, L3.2
unnamed: IC1.2 (RI), TP14.P$1
unnamed: IC1.28 (DTR), TP9.P$1
unnamed: IC1.1 (DCD), TP16.P$1
unnamed: IC1.27 (DSR), TP17.P$1
unnamed: IC1.23 (CTS), TP18.P$1
unnamed: IC1.9 (!RST), JP8.1, R13.2
unnamed: LED3.K, R2.2
unnamed: LED2.1 (BK), R9.1
unnamed: LED2.4 (GK), R8.1
unnamed: LED2.3 (RK), R7.1
unnamed: CF1.4, TP12.P$1
PTA0: J1.4 (TCK), JP5.3, JP5.4, U3.10 (PTA0)
PTA1: IC1.26 (TXD), JP5.5, JP5.6, U3.14 (PTA1)
PTA2: IC1.25 (RXD), JP5.7, JP5.8, U3.13 (PTA2)
PTA3: J1.2 (TMS), JP5.9, JP5.10, U3.11 (PTA3)
PTA4: JP5.11, JP5.12, U3.12 (PTA4)
PTA18: R11.2, U3.15 (PTA18/EXTAL0), W1.P2 (2)
PTA18-JMP: JP5.13, JP5.14, R11.1
PTA19/XTAL0: JP5.15, JP5.16, U3.16 (PTA19/XTAL0)
PTA20/!RESET: C21.1, J1.10 (SRST), JP5.17, JP5.18, R1.1, S2.A2 (1), U3.33 (PTA20/!RESET)
PTB0: J2.1, JP7.1, JP7.2, U3.17 (PTB0)
PTB1: JP7.3, JP7.4, R7.2, U3.18 (PTB1)
PTB2: JP7.5, JP7.6, R8.2, U3.21 (PTB2)
PTB17: JP7.7, JP7.8, R9.2, U3.22 (PTB17)
PTC1: JP4.1, JP4.2, U3.24 (PTC1)
PTC2: JP4.3, JP4.4, U3.25 (PTC2)
PTC3: JP4.5, JP4.6, U3.26 (PTC3)
PTC4: JP4.7, JP4.8, U3.23 (PTC4)
PTC5: JP4.9, JP4.10, U3.59 (PTC5)
PTC6: JP4.11, JP4.12, U3.60 (PTC6)
PTC7: JP4.13, JP4.14, U3.57 (PTC7)
PTD0: JP3.3, JP3.4, U3.58 (PTD0)
PTD4: JP3.5, JP3.6, U3.27 (PTD4)
PTD5: JP3.7, JP3.8, U3.28 (PTD5)
PTD6: JP3.9, JP3.10, U3.29 (PTD6)
PTD7: JP3.11, JP3.12, U3.31 (PTD7)
PTE0: JP2.3, JP2.4, U3.32 (PTE0)
PTE1: JP2.5, JP2.6, U3.34 (PTE1)
PTE2: JP2.7, JP2.8, U3.49 (PTE2)
PTE3: JP2.9, JP2.10, U3.50 (PTE3)
PTE16: JP2.11, JP2.12, U3.5 (PTE16)
PTE17: JP2.13, JP2.14, U3.6 (PTE17)
PTE18: JP2.15, JP2.16, U3.7 (PTE18)
PTE19: JP2.17, JP2.18, U3.8 (PTE19)
PTE30: JP2.19, JP2.20, U3.9 (PTE30)
RESET(RF): J2.2, U3.48 (RESET(RF))
RFIO: C10.2, C11.1, L1.2, U3.39 (RFIO)
SHIELD: C20.1, CF1.S1 (SHIELD), CF1.S2 (SHIELD), CF1.S3 (SHIELD), CF1.S4 (SHIELD), R14.1
STAT1/LBO: JP9.5, JP9.6, R5.1, U2.P$8 (STAT1/LBO)
STAT2: JP9.3, JP9.4, R3.1, U2.P$7 (STAT2)
V+: C4.1, JP1.VCC (2), JP10.1, TP1.P$1, U2.P$14 (VBAT1), U2.P$15 (VBAT2), U2.P$16 (VBATSENS)
VBUS: C1.1, C17.1, CF1.1, IC1.7 (REGIN), IC1.8 (VBUS), TP5.P$1, U2.P$2 (VPCC), U2.P$3 (SEL), U2.P$9 (/TE), U2.P$18 (VIN1), U2.P$19 (VIN2)
VOUT: C2.1, C3.1, S1.3 (S), TP2.P$1, U1.1 (IN), U2.P$1 (VOUT1), U2.P$20 (VOUT2)
VR_ANA: C25.1, U3.44 (VR_ANA)
VR_DIG: C23.1, U3.45 (VR_DIG)
VR_PA: C16.2, L1.1, TP15.P$1, U3.42 (VR_PA)
XTA: R6.2, U3.46 (XTA)
XTB: C26.1, U3.47 (XTB), X1.1

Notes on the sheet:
Note: this setup is for USB currently termination = 1000V/Rprog3 reg = 1000V/Rprog1 Charge current = 200mA Charge termination = 12.5mA
Voltage Regulator
Battery Charger
Designed by: T05
AC Blocking Network
Bidirectional Transceiver Circuit at 436.5MHz
USB to UART CP2102
JTAG/SWD
Reset button
3.7V 1000mAh lipo cell battery
RESET(RF) is suppose to be controlled by a GPIO according to the databook
PORTC
PORTB
PORTD
PORTE
Cuttable jumper for 32 MHz
bypass for VDDA
bypass for VREFH
Antenna
SMA J716-ND
Test VR-PA
PORTA
RF GPIO

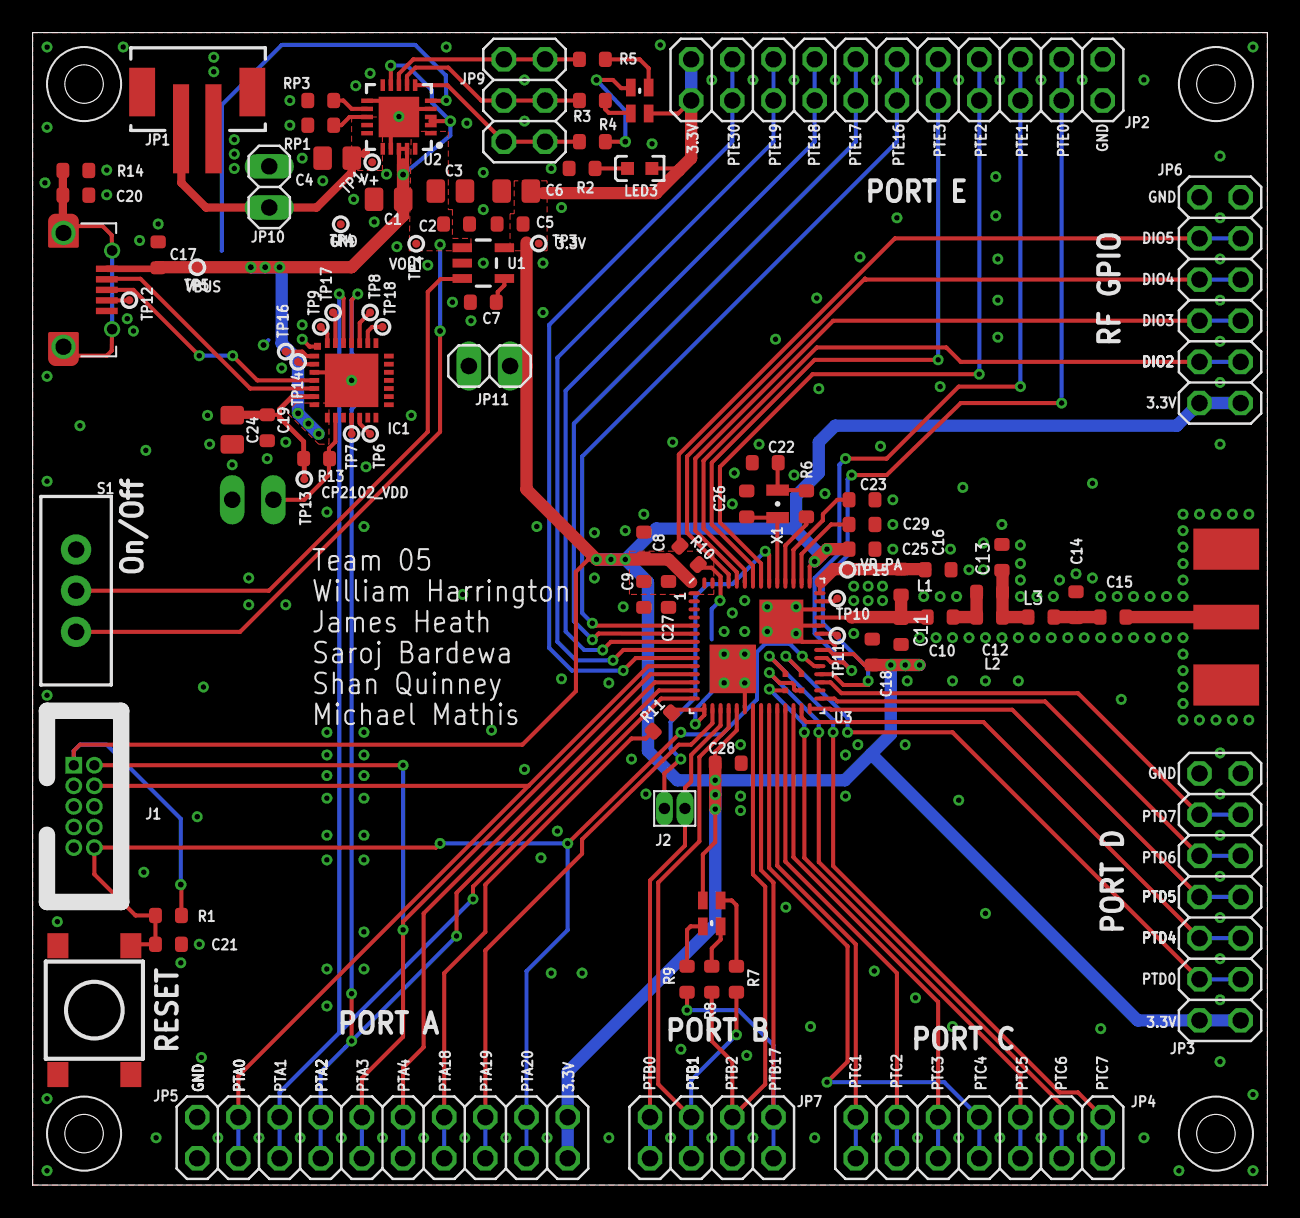
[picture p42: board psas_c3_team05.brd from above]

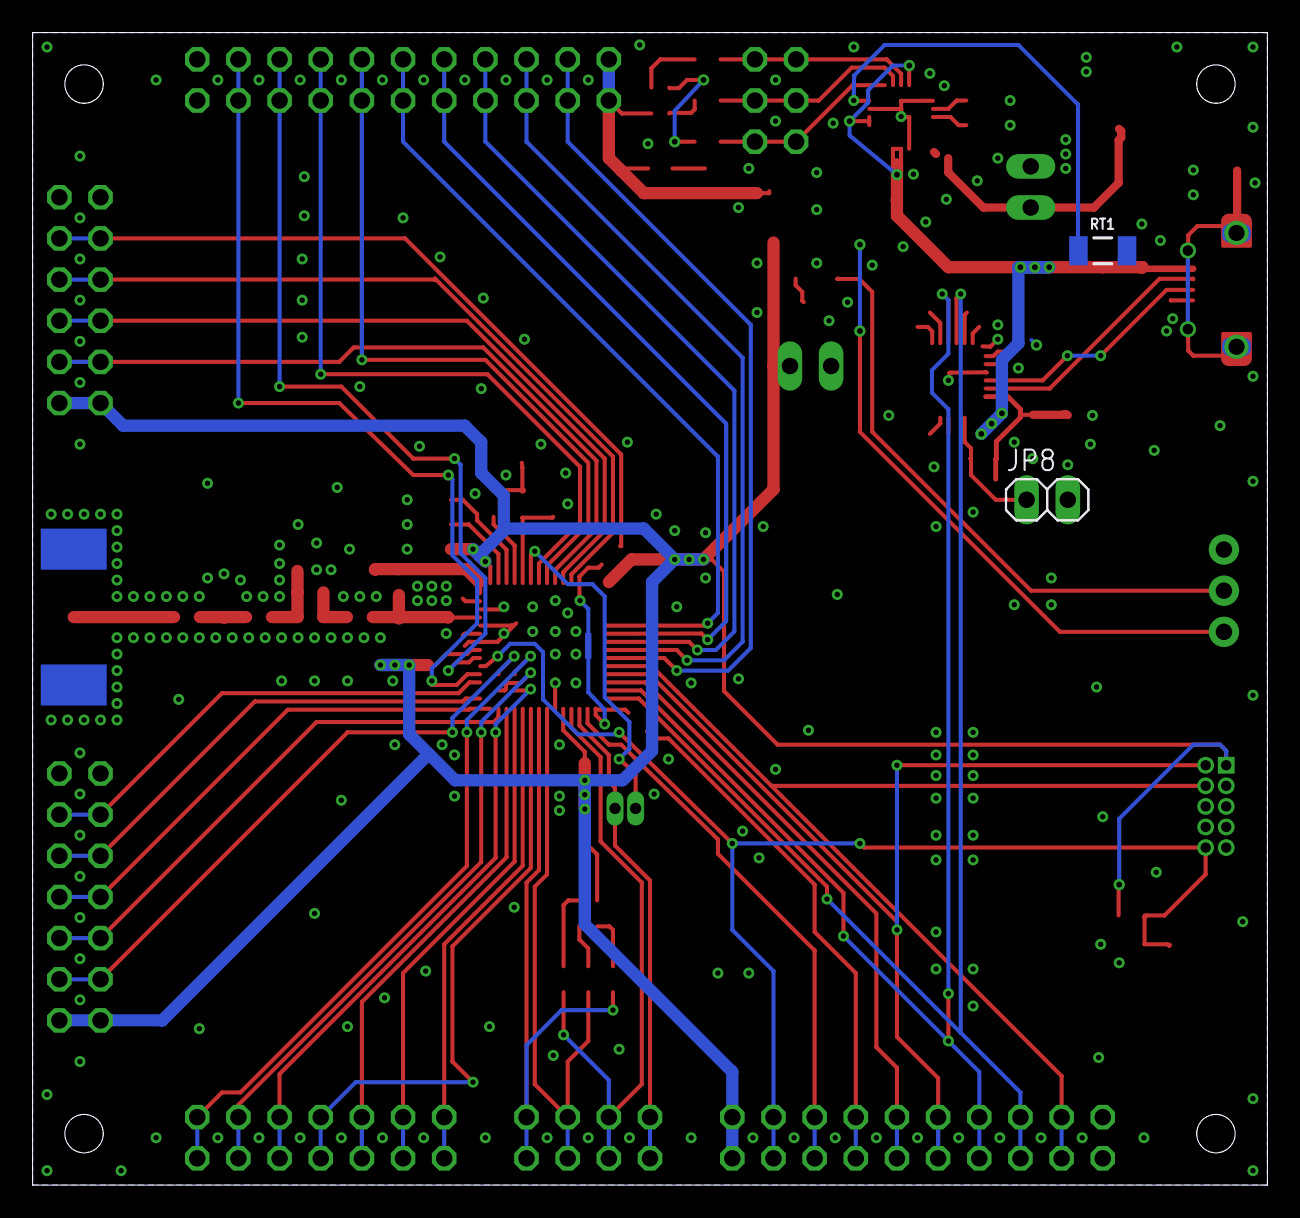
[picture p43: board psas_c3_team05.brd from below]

Board: 2 copper layers, 76.2 x 71.1 mm, 96 parts (3 on the bottom side), 87 nets.

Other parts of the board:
DI1, DI2, DI3, DI4: #2/.750-BARE

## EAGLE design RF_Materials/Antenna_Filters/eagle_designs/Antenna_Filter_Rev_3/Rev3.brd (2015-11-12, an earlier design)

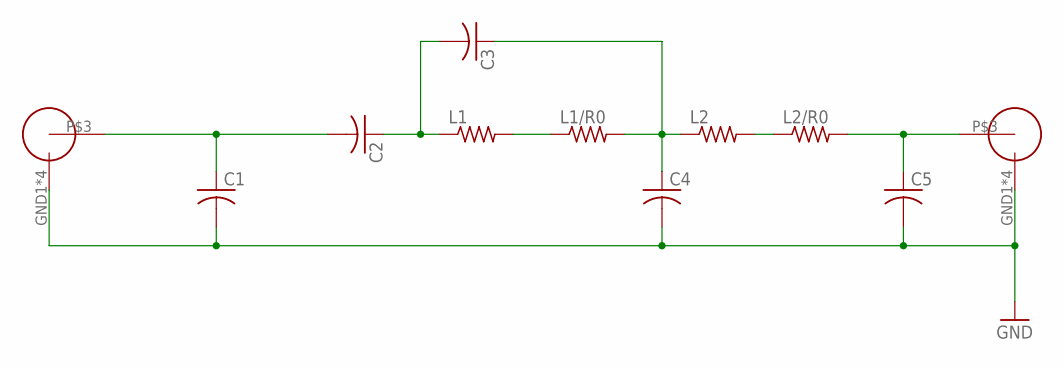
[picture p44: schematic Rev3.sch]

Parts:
C1, C2, C3, C4, C5: C-USC0603; C0603
L1, L1/R0, L2, L2/R0: R-US_R0603; R0603
U$1, U$2: SMAJ716-ND

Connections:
C3: C3.1, C4.1, L1/R0.2, L2.1
GND: C1.2, C4.2, C5.2, U$1.GND1 (OUTERCONDUCTOR), U$1.GND2 (OUTERCONDUCTOR), U$1.GND3 (OUTERCONDUCTOR), U$1.GND4 (OUTERCONDUCTOR), U$2.GND1 (OUTERCONDUCTOR), U$2.GND2 (OUTERCONDUCTOR), U$2.GND3 (OUTERCONDUCTOR), U$2.GND4 (OUTERCONDUCTOR)
unnamed: C5.1, L2/R0.2, U$2.P$3 (CENTERCONDUCTOR)
unnamed: L2.2, L2/R0.1
unnamed: C2.1, C3.2, L1.1
unnamed: L1.2, L1/R0.1
unnamed: C1.1, C2.2, U$1.P$3 (CENTERCONDUCTOR)

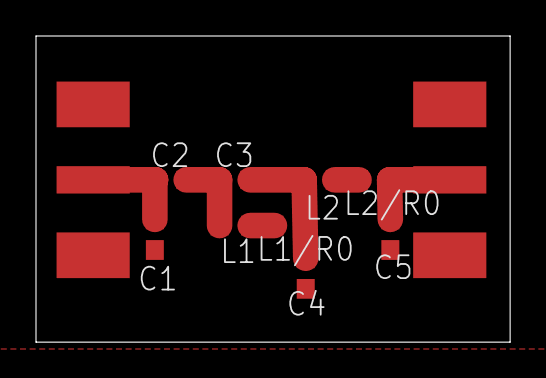
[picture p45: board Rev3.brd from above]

Board: 2 copper layers, 26.3 x 17.0 mm, 11 parts (0 on the bottom side), 7 nets.

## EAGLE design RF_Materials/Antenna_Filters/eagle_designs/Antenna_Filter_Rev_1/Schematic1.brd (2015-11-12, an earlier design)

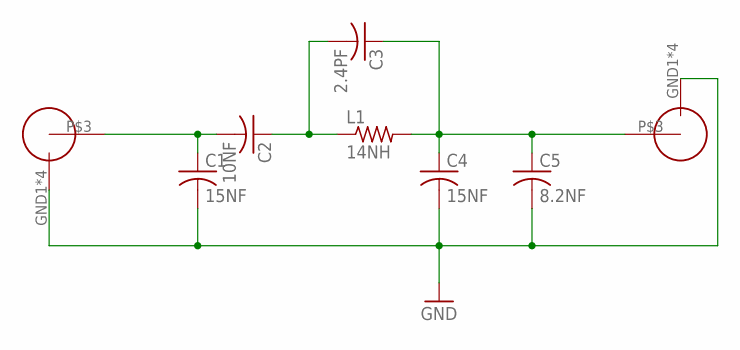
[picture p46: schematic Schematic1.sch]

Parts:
C1, C4: 15NF; C0603
C2: 10NF; C0603
C3: 2.4PF; C0603
C5: 8.2NF; C0603
GND: SMAJ716-ND
L1: 14NH; R0603
U$2: SMAJ716-ND

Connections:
GND: C1.2, C4.2, C5.2, GND.GND1 (OUTERCONDUCTOR), GND.GND2 (OUTERCONDUCTOR), GND.GND3 (OUTERCONDUCTOR), GND.GND4 (OUTERCONDUCTOR), U$2.GND1 (OUTERCONDUCTOR), U$2.GND2 (OUTERCONDUCTOR), U$2.GND3 (OUTERCONDUCTOR), U$2.GND4 (OUTERCONDUCTOR)
unnamed: C3.1, C4.1, C5.1, L1.2, U$2.P$3 (CENTERCONDUCTOR)
unnamed: C2.1, C3.2, L1.1
unnamed: C1.1, C2.2, GND.P$3 (CENTERCONDUCTOR)

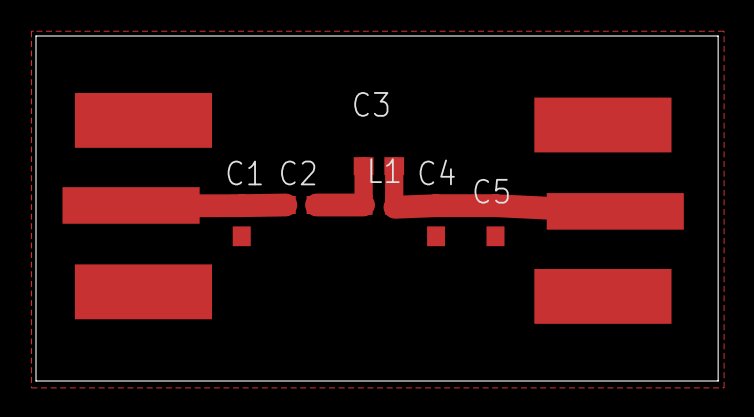
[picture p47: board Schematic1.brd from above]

Board: 2 copper layers, 37.9 x 19.2 mm, 8 parts (0 on the bottom side), 4 nets.

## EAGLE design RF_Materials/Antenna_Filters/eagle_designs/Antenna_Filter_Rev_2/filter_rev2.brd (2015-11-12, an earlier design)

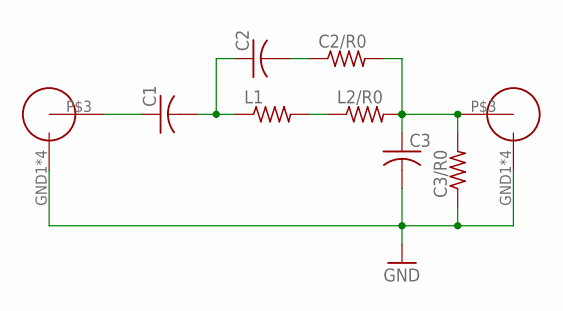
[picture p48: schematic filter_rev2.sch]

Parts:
C1, C2, C3: C-USC0603; C0603
C2/R0, C3/R0: R-US_R0603; R0603
L1, L2/R0: R-US_R0603; R0603
U$1, U$2: SMAJ716-ND

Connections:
GND: C3.2, C3/R0.1, U$1.GND1 (OUTERCONDUCTOR), U$1.GND2 (OUTERCONDUCTOR), U$1.GND3 (OUTERCONDUCTOR), U$1.GND4 (OUTERCONDUCTOR), U$2.GND1 (OUTERCONDUCTOR), U$2.GND2 (OUTERCONDUCTOR), U$2.GND3 (OUTERCONDUCTOR), U$2.GND4 (OUTERCONDUCTOR)
unnamed: C1.1, U$1.P$3 (CENTERCONDUCTOR)
unnamed: C2.2, C2/R0.1
unnamed: C1.2, C2.1, L1.1
unnamed: C2/R0.2, C3.1, C3/R0.2, L2/R0.2, U$2.P$3 (CENTERCONDUCTOR)
unnamed: L1.2, L2/R0.1


Board: 2 copper layers, 24.1 x 15.1 mm, 9 parts (0 on the bottom side), 6 nets.

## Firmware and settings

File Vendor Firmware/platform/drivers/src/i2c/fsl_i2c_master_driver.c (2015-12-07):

/*
 * Copyright (c) 2013 - 2014, Freescale Semiconductor, Inc.
 * All rights reserved.
 *
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
 * o Neither the name of Freescale Semiconductor, Inc. nor the names of its
 *   contributors may be used to endorse or promote products derived from this
 *   software without specific prior written permission.
 *
 * THIS SOFTWARE IS PROVIDED BY THE COPYRIGHT HOLDERS AND CONTRIBUTORS "AS IS" AND
 * ANY EXPRESS OR IMPLIED WARRANTIES, INCLUDING, BUT NOT LIMITED TO, THE IMPLIED
 * WARRANTIES OF MERCHANTABILITY AND FITNESS FOR A PARTICULAR PURPOSE ARE
 * DISCLAIMED. IN NO EVENT SHALL THE COPYRIGHT HOLDER OR CONTRIBUTORS BE LIABLE FOR
 * ANY DIRECT, INDIRECT, INCIDENTAL, SPECIAL, EXEMPLARY, OR CONSEQUENTIAL DAMAGES
 * (INCLUDING, BUT NOT LIMITED TO, PROCUREMENT OF SUBSTITUTE GOODS OR SERVICES;
 * LOSS OF USE, DATA, OR PROFITS; OR BUSINESS INTERRUPTION) HOWEVER CAUSED AND ON
 * ANY THEORY OF LIABILITY, WHETHER IN CONTRACT, STRICT LIABILITY, OR TORT
 * (INCLUDING NEGLIGENCE OR OTHERWISE) ARISING IN ANY WAY OUT OF THE USE OF THIS
 * SOFTWARE, EVEN IF ADVISED OF THE POSSIBILITY OF SUCH DAMAGE.
 */

#include <assert.h>
#include <string.h>
#include "fsl_i2c_master_driver.h"
#include "fsl_i2c_shared_function.h"
#include "fsl_clock_manager.h"
#include "fsl_interrupt_manager.h"

#if FSL_FEATURE_SOC_I2C_COUNT

/*******************************************************************************
 * Definitions
 ******************************************************************************/
/* Default timeout time(ms) for sending of address and CMD buffer */
#define I2C_TIMEOUT_MS (30)

/*******************************************************************************
 * Private Functions
 ******************************************************************************/

static i2c_status_t I2C_DRV_MasterWait(uint32_t instance, uint32_t timeout_ms);
static void I2C_DRV_CompleteTransfer(uint32_t instance);
static i2c_status_t I2C_DRV_SendAddress(uint32_t instance,
                                        const i2c_device_t * device,
                                        const uint8_t * cmdBuff,
                                        uint32_t cmdSize,
                                        i2c_direction_t direction,
                                        uint32_t timeout_ms);
static i2c_status_t I2C_DRV_MasterSend(uint32_t instance,
                                       const i2c_device_t * device,
                                       const uint8_t * cmdBuff,
                                       uint32_t cmdSize,
                                       const uint8_t * txBuff,
                                       uint32_t txSize,
                                       uint32_t timeout_ms,
                                       bool isBlocking);
static i2c_status_t I2C_DRV_MasterReceive(uint32_t instance,
                                          const i2c_device_t * device,
                                          const uint8_t * cmdBuff,
                                          uint32_t cmdSize,
                                          uint8_t * rxBuff,
                                          uint32_t rxSize,
                                          uint32_t timeout_ms,
                                          bool isBlocking);

/*******************************************************************************
 * Code
 ******************************************************************************/

/*FUNCTION**********************************************************************
 *
 * Function Name : I2C_DRV_MasterInit
 * Description   : initializes the I2C master mode driver.
 * This function will initialize the I2C master mode driver, enable I2C clock,
 * and enable I2C interrupt.
 *
 *END**************************************************************************/
i2c_status_t I2C_DRV_MasterInit(uint32_t instance, i2c_master_state_t * master)
{
    assert(master);
    assert(instance < I2C_INSTANCE_COUNT);

    I2C_Type * base = g_i2cBase[instance];

    /* Exit if current instance is already initialized */
    if (g_i2cStatePtr[instance])
    {
        return kStatus_I2C_Initialized;
    }

    /* Initialize driver instance struct */
    memset(master, 0, sizeof(i2c_master_state_t));

    /* Create sync object for transfer. */
    OSA_SemaCreate(&master->irqSync, 0);

    /* Enable clock for I2C.*/
    CLOCK_SYS_EnableI2cClock(instance);

    /* Initialize peripheral to known state.*/
    I2C_HAL_Init(base);

    /* Save runtime structure pointer */
    g_i2cStatePtr[instance] = master;

    /* Enable I2C interrupt in NVIC level.*/
    INT_SYS_EnableIRQ(g_i2cIrqId[instance]);

    /* Indicate I2C bus is idle. */
    master->i2cIdle = true;

    /* Enable module.*/
    I2C_HAL_Enable(base);

    return kStatus_I2C_Success;
}

/*FUNCTION**********************************************************************
 *
 * Function Name : I2C_DRV_MasterDeinit
 * Description   : Deinit the I2C master mode driver.
 * This function will deinit the I2C master mode driver, disable I2C clock,
 * and disable I2C interrupt.
 *
 *END**************************************************************************/
i2c_status_t I2C_DRV_MasterDeinit(uint32_t instance)
{
    assert(instance < I2C_INSTANCE_COUNT);

    /* Exit if current instance is already de-initialized or is gated.*/
    if ((!g_i2cStatePtr[instance]) || (!CLOCK_SYS_GetI2cGateCmd(instance)))
    {
        return kStatus_I2C_Fail;
    }

    I2C_Type * base = g_i2cBase[instance];
    i2c_master_state_t * master = (i2c_master_state_t *)g_i2cStatePtr[instance];

    /* Disable module.*/
    I2C_HAL_Disable(base);

    /* Disable clock for I2C.*/
    CLOCK_SYS_DisableI2cClock(instance);

    /* Disable I2C NVIC interrupt*/
    INT_SYS_DisableIRQ(g_i2cIrqId[instance]);

    /* Destroy I2C sema. */
    OSA_SemaDestroy(&master->irqSync);

    /* Cleared state pointer. */
    g_i2cStatePtr[instance] = NULL;

    return kStatus_I2C_Success;
}
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

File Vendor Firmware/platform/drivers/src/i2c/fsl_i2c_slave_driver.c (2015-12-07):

/*
 * Copyright (c) 2013 - 2014, Freescale Semiconductor, Inc.
 * All rights reserved.
 *
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
 * o Neither the name of Freescale Semiconductor, Inc. nor the names of its
 *   contributors may be used to endorse or promote products derived from this
 *   software without specific prior written permission.
 *
 * THIS SOFTWARE IS PROVIDED BY THE COPYRIGHT HOLDERS AND CONTRIBUTORS "AS IS" AND
 * ANY EXPRESS OR IMPLIED WARRANTIES, INCLUDING, BUT NOT LIMITED TO, THE IMPLIED
 * WARRANTIES OF MERCHANTABILITY AND FITNESS FOR A PARTICULAR PURPOSE ARE
 * DISCLAIMED. IN NO EVENT SHALL THE COPYRIGHT HOLDER OR CONTRIBUTORS BE LIABLE FOR
 * ANY DIRECT, INDIRECT, INCIDENTAL, SPECIAL, EXEMPLARY, OR CONSEQUENTIAL DAMAGES
 * (INCLUDING, BUT NOT LIMITED TO, PROCUREMENT OF SUBSTITUTE GOODS OR SERVICES;
 * LOSS OF USE, DATA, OR PROFITS; OR BUSINESS INTERRUPTION) HOWEVER CAUSED AND ON
 * ANY THEORY OF LIABILITY, WHETHER IN CONTRACT, STRICT LIABILITY, OR TORT
 * (INCLUDING NEGLIGENCE OR OTHERWISE) ARISING IN ANY WAY OUT OF THE USE OF THIS
 * SOFTWARE, EVEN IF ADVISED OF THE POSSIBILITY OF SUCH DAMAGE.
 */

#include <assert.h>
#include <string.h>
#include "fsl_i2c_hal.h"
#include "fsl_i2c_slave_driver.h"
#include "fsl_i2c_shared_function.h"
#include "fsl_clock_manager.h"
#include "fsl_interrupt_manager.h"

#if FSL_FEATURE_SOC_I2C_COUNT

/*******************************************************************************
 * Code
 ******************************************************************************/

/*FUNCTION**********************************************************************
 *
 * Function Name : I2C_DRV_SlaveInit
 * Description   : initializes the I2C module.
 * This function will save the application callback info, turn on the clock of
 * I2C instance, setup according to user configuration.
 *
 *END**************************************************************************/
i2c_status_t I2C_DRV_SlaveInit(uint32_t instance,
                       const i2c_slave_user_config_t * userConfigPtr,
                       i2c_slave_state_t * slave)
{
    assert(slave);
    assert(instance < I2C_INSTANCE_COUNT);

    I2C_Type * base = g_i2cBase[instance];

    /* Exit if current instance is already initialized. */
    if (g_i2cStatePtr[instance])
    {
        return kStatus_I2C_Initialized;
    }

    /* Init driver instance structure */
    memset(slave, 0, sizeof(i2c_slave_state_t));
    slave->slaveListening = userConfigPtr->slaveListening;
    slave->slaveCallback = userConfigPtr->slaveCallback;
    slave->callbackParam = userConfigPtr->callbackParam;

    /* Enable clock for I2C.*/
    CLOCK_SYS_EnableI2cClock(instance);

    /* Init instance to known state. */
    I2C_HAL_Init(base);

    /* Set slave address.*/
    I2C_HAL_SetAddress7bit(base, userConfigPtr->address);

    /* Save runtime structure pointer.*/
    g_i2cStatePtr[instance] = slave;

    /* Create Event for irqSync */
    OSA_EventCreate(&slave->irqEvent, kEventAutoClear);

#if FSL_FEATURE_I2C_HAS_START_STOP_DETECT
    /* Enable I2C START&STOP signal detect interrupt in the peripheral.*/
    if(userConfigPtr->startStopDetect)
    {
        I2C_HAL_SetStartStopIntCmd(base,true);
    }
#endif
#if FSL_FEATURE_I2C_HAS_STOP_DETECT
    /* Enable STOP signal detect interrupt in the peripheral.*/
    if(userConfigPtr->stopDetect)
    {
        I2C_HAL_SetStopIntCmd(base,true);
    }
#endif

    /* Enable I2C interrupt as default if setup slave listening mode */
    I2C_HAL_SetIntCmd(base, 1);

    /* Enable I2C interrupt from NVIC */
    INT_SYS_EnableIRQ(g_i2cIrqId[instance]);

    /* Enable the peripheral operation.*/
    I2C_HAL_Enable(base);

    return kStatus_I2C_Success;
}

/*FUNCTION**********************************************************************
 *
 * Function Name : I2C_DRV_SlaveDeinit
 * Description   : Shuts down the I2C slave driver.
 * This function will clear the control register and turn off the clock to the
 * module.
 *
 *END**************************************************************************/
i2c_status_t I2C_DRV_SlaveDeinit(uint32_t instance)
{
    assert(instance < I2C_INSTANCE_COUNT);

    /* Exit if current instance is already de-initialized or is gated.*/
    if ((!g_i2cStatePtr[instance]) || (!CLOCK_SYS_GetI2cGateCmd(instance)))
    {
        return kStatus_I2C_Fail;
    }

    I2C_Type * base = g_i2cBase[instance];
    i2c_slave_state_t * i2cSlaveState = (i2c_slave_state_t *)g_i2cStatePtr[instance];

#if FSL_FEATURE_I2C_HAS_START_STOP_DETECT
    /* Disable I2C START&STOP signal detect interrupt in the peripheral.*/
    I2C_HAL_SetStartStopIntCmd(base,false);
#endif
#if FSL_FEATURE_I2C_HAS_STOP_DETECT
    /* Disable STOP signal detect interrupt in the peripheral.*/
    I2C_HAL_SetStopIntCmd(base,false);
#endif

    /* Disable I2C interrupt. */
    I2C_HAL_SetIntCmd(base, false);

    /* Turn off I2C.*/
    I2C_HAL_Disable(base);

    /* Disable clock for I2C.*/
    CLOCK_SYS_DisableI2cClock(instance);

    /* Disable I2C NVIC interrupt */
    INT_SYS_DisableIRQ(g_i2cIrqId[instance]);

    /* Destroy sema. */
    OSA_EventDestroy(&i2cSlaveState->irqEvent);

    /* Clear runtime structure poniter.*/
    g_i2cStatePtr[instance] = NULL;

    return kStatus_I2C_Success;
}

/*FUNCTION**********************************************************************
 *
 * Function Name : I2C_DRV_SlaveGetHandler
 * Description   : Get run-time handler to  I2C slave state structure.
 * This function will return the pointer to I2C slave state structure.
 *
 *END**************************************************************************/
i2c_slave_state_t * I2C_DRV_SlaveGetHandler(uint32_t instance)
{
    return (i2c_slave_state_t *)g_i2cStatePtr[instance];
}
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

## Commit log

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2015-10-13 started eagle sch/brd, also included library for parts that are on there so far
    [psas_c3.brd, psas_c3.sch]
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2015-10-14 touched up the battery charger and voltage regulator circuit
    [psas_c3.brd, psas_c3.sch]
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2015-10-18 added microcontroller unit to library and placed on sch/brd
    [psas_c3.brd, psas_c3.sch]
2015-10-24 revised PDS, MCU is on schematic & board now along with new USB2UART chip (added datasheet for that as well)
    [psas_c3.brd, psas_c3.sch]
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2015-10-26 MRBKW01 Development Board Specifications
    Contents all the design specifications and schematics including Gerber
    files and BOMs
    [BOM-MRB-KW01-3032_B.xlsx, BOM-MRB-KW01-4532_B.xlsx, BOM-MRB-KW01-9030_B.xlsx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]
2015-10-26 Revert "MRBKW01 Development Board Specifications"
    This reverts commit cf092c42eb6c7384f835c4a5d43a9cdc6e3e7ef3.
    [BOM-MRB-KW01-3032_B.xlsx, BOM-MRB-KW01-4532_B.xlsx, BOM-MRB-KW01-9030_B.xlsx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]
2015-10-26 Revert "Revert "MRBKW01 Development Board Specifications""
    This reverts commit b2653d320d52ee7f62f8fdddaa0167ae44b35d42.
    [BOM-MRB-KW01-3032_B.xlsx, BOM-MRB-KW01-4532_B.xlsx, BOM-MRB-KW01-9030_B.xlsx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]
2015-10-26 Revert "Revert "Revert "MRBKW01 Development Board Specifications"""
    This reverts commit 5b51370e89bb3bb79aa1e102b55af3dc4bba2af4.
    [BOM-MRB-KW01-3032_B.xlsx, BOM-MRB-KW01-4532_B.xlsx, BOM-MRB-KW01-9030_B.xlsx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]
2015-10-27 Updated schematic with RF parts, need to do values
    [psas_c3.sch]
2015-10-27 generated new board file so that schematic and board are consistent
    [psas_c3.brd]
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2015-10-28 Fixed component values to RF circuit. Looks good
    [psas_c3.brd, psas_c3.sch]
2015-10-29 Fixed one component value (inductor)
    [psas_c3.brd, psas_c3.sch]
2015-10-29 Added a RF folder for all RF materials and changed another component value
    [psas_c3.brd, psas_c3.sch]
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2015-10-31 added JTAG header, reorganized some other stuff, added ground shield to micro-usb connector
    [psas_c3.brd, psas_c3.sch]
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2015-11-01 Added GPIO 2x9pins, 2x10 pins and SW Connector
    [psas_c3.brd, psas_c3.sch]
2015-11-01 Added Software Development Connector and 32KHz crystal in schematics
    [psas_c3.brd, psas_c3.sch]
2015-11-02 finished preliminary schematic layout, did a lot of reorganizing and cleaning up, added pin headers for i2c spi uart etc, passed erc with no errors but lots of warnings
    [psas_c3.brd, psas_c3.sch]
2015-11-02 removed incorrect net causing a GND warning in the ERC
    [psas_c3.sch]
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2015-11-04 Added a few more recommended things to the schematic
    [psas_c3.brd, psas_c3.sch]
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2015-11-04 Fixed alignment issues on schematic
    [psas_c3.brd, psas_c3.sch]
2015-11-04 made fixes to schematic
    [psas_c3.brd, psas_c3.sch]
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2015-11-05 Revert "revisions"
    This reverts commit 38aaf88b81013dcc018781bf82979bc3fff6647d, reversing
    changes made to 2f30e97817f685fc14312947979bc5bd385c959f.
    [psas_c3.brd, psas_c3.sch]
2015-11-06 added bypass cap for vdd2, pin header for RESET(RF), double row pin header for each port on MCU, added pullup on RX/TX with jpin header for jumper, added pin header for battery status, 1000mAh batter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
    [psas_c3.brd, psas_c3.sch]
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2015-11-07 Board update, let me know if there is anything you want to change
    [psas_c3.brd]
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2015-11-09 Board update. No drc errors or unhooked airwires, but RF trace width still needs to be fixed
    [psas_c3_team05.brd, psas_c3_team05.sch]
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2015-11-09 fixed rx line on usb2uart chip that was no connected, fixed two remaining airwires but sma connector pad is not cooperating so there is one airwire :(
    [psas_c3_team05.brd, psas_c3_team05.sch]
2015-11-09 forgot to check drc, took care of one error
    [psas_c3_team05.brd]
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2015-11-12 put in reset line
    [psas_c3_team05.brd]
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2015-11-13 Adjusted the position of labels, and added missing boader
    [psas_c3_team05.brd, psas_c3_team05.sch]
2015-11-13 Fixed some wires that were moved
    [psas_c3_team05.brd]
2015-11-15 added labels for MCU ports on board layout, labeled some lines on PORTA of MCU that were missing labels
    [psas_c3_team05.brd, psas_c3_team05.sch]
2015-11-15 General schematic clean a la Andrew -- Cap sizes, CP2102 test points and unused chips, killed VBUS diode, added power LED, Added TBG LED for KW0x that still needs to be connected, Misc OCD cleanup.
    [psas_c3_team05.brd, psas_c3_team05.sch]
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2015-11-16 Swtiched JTAG/SWD connector and added part values for missing values.
    [psas_c3_team05.brd, psas_c3_team05.sch]
2015-11-16 major board cleanup and shrinkage. OOPS: just found out the uC pinout is wrong. Committing before doing that change.
    [psas_c3_team05.brd, psas_c3_team05.sch]
2015-11-16 started correcting the MCU footprint...yeah its bad
2015-11-16 Well, sometimes you just have to start over :( Fixed flipped chip. No more airwires.
    [psas_c3_team05.brd, psas_c3_team05.sch]
2015-11-16 Vias. Lots and lots of ground vias. Stitched until my dogs threw up. Checked ERCs and DRCs, fixed things. Forgot to say added jumper and NP zero ohms for 32 MHz clock line -- running that away from t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
    [psas_c3_team05.brd, psas_c3_team05.sch]
2015-11-16 Oh, and TSTOP ground clips for scope probes. And a VBAT jumper. And 3.3V jumper. All because debugging.
    [psas_c3_team05.brd, psas_c3_team05.sch]
2015-11-16 added labels to important test points, added labels for reset and on/off switch, cleared erc on schematic and made minor changes
    [psas_c3_team05.brd, psas_c3_team05.sch]
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2015-11-16 fixed ground pad on CP2102
    [psas_c3_team05.brd, psas_c3_team05.sch]
2015-11-16 fixed ground pads on MCU, generated new library that has everything in it
    [psas_c3_team05.brd, psas_c3_team05.sch]
2015-11-16 fixed ground pad spread on chips.
    [psas_c3_team05.brd]
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2015-11-18 finished adding distributor and manufacturer part numbers as attributes on the schematic, each part excluding the rf network should at this point have a set of attributes with distributor and manufac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
    [psas_c3_team05.brd, psas_c3_team05.sch]
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2015-11-18 Revert "Adding last of the RF comonent values"
    This reverts commit 7397b54fd702c28f83bd8fc1e4a5cf04a2794204, reversing
    changes made to 8a4b7e35c62daac60a982cdc541bb9407ad4beed.
    [psas_c3_team05.brd, psas_c3_team05.sch]
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2015-11-19 added more attributes for part numbers, duplicated crystal because crystal footprint is wrong on the board and we will need to order two just in case things go wrong with the first, hopefully one of 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
    [psas_c3_team05.brd, psas_c3_team05.sch]
2015-11-21 Fixed changed components on the layout
    [psas_c3_team05.brd, psas_c3_team05.sch]
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2015-11-30 Firmware tools first pass
    This should provide everything needed to get started programming the
    kw01zxxx board. Main is in c3.c, you'll want to start poking about in
    there.
    Currently there's still an issue with watchdogs sometimes interrupting
    debugging, if writing the firmware fails, try it again and it should go
    through.
    [olimex_swd_kinetis.cfg]
2015-11-30 took extra crystal off schematic, corrected bogus airwire
    [psas_c3_team05.brd, psas_c3_team05.sch]
2015-11-30 Added new make targets for creating .s files
    Original make file didn't work on my system.
    Xcode not using proper assembler.
    This is a workaround for that.
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2015-12-09 Clock configuration finished
    The MCU now boots up with the internal oscillator like it should then sets up the port and spi clocks (so that we can read/write those registers) then a small initialization procedure on the SPI0 module requests the full 32MHz signal from the transceiver. When the transceiver supplies that, we shut off all the clocks to all the modules and then dial up the PLL to create a 48 MHz clock signal. After that, we turn the clocks back on for the modules we use in this code (which aren't much some are even completey unnecessary) then blink some LEDs because thats what we do in computer engineering is blink LEDs. Now lets get this thing space ready so we can blink LEDs ou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
2015-12-16 First revision of SPI driver
    Generalized SPI driver to SPI transaction frame. Need to continue generalizing. Also made some small corrections to transceiver mapping header file.
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2015-12-17 More memory map stuff done
    Caught some padding mistakes. Introduced MTB, ADC, DMA, and maybe some others. Still not quite done.
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2015-12-26 fixed arguments for function prototypes
2016-01-08 Disable watchdog in openocd
    Note this will requre Openocd 0.10.0 which isn't released yet. Compile
    it from source
    [olimex_swd_kinetis.cfg]
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2016-01-12 Added halting gdb-attach event
    This should make it easier to connect gdb to openocd. Now there is no
    need to telnet in and stop the target before attaching gdb.
    [olimex_swd_kinetis.cfg]
2016-01-13 Change spi driver to pass peripheral by pointer
    Passing by value means the struct gets copied to an arbitrary location
    in memory - any modifications won't change the actual memory mapped
    peripheral.
2016-01-13 Moved alt pin configuration inside the spi driver
    The spi driver knows which pins should be given which alt selection, so
    lets have it do so automatically insted of allowing the user to get it
    wrong.
    This current implementation is mostly there, but isn't perfect. Still
    left to do:
    - Have it make selections given which spi peripheral is passed in. This
    information should be encoded in the struct pin_assign arrays;
    - The driver should yell loudly when an invalid pin is provided. First
    step should probably be a runtime assert.
    - Long term the configuration should be done statically at compile time.
    Then we can pull in static_assert()s so that it will not compile when
    an invalid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
2016-01-13 Added spi driver information to spi pinout config
    spi_init will now be able to check the correct pin, and set its alt
    function correctly or cause an abort if the pin is wrong.
2016-01-13 Fixed compile errors in spi driver
    Oh how I wish C would do what I meant instead of what I wrote. Having to
    add & pretty much everywhere is kind of lame and remembering to write
    volatile struct * peripheral will probably get tiring soon. I may
    re-think the declaration scheme I had going in the near future, but not
    until I try the full static config first.
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2016-02-13 Finished initial UART driver
    Finished initial UART driver. It compiles. Fixed some stuff in the SPI driver as well. Everything compiled.
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2016-02-14 Schematic checkpoint
    Setup GPIO and I2C for power interface. Placed bypass caps on all power lines. Placed XTAL/Resonator. Labeled some wires.
    [sputnik_prototype.sch]
2016-02-14 POR reset bug
    MCU wasn't behaving as expected after Power-on reset. This was due to the fact that the transceiver is unavailable for 10ms after a POR. I added a delay loop in the beginning of main to resolve the issue.
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2016-02-17 Created LDO and fixed PA footprints
    [sputnik_prototype.sch]
2016-02-20 Fixed transceiver compile bug
    Had to add include guards. Also extern for global transceiver struct. Cleaned up header organization. Had to include spi.h in c3.c. Also modified configure transceiver function to now allow for controlling power output.
2016-02-22 Finished hooking up interfaces and power stuff
    Created board file from schematic so its f/b annotated now. Hooked up LDO for KW0x and ATMEGA128. Other minor changes.
    [sputnik_prototype.brd, sputnik_prototype.sch]
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2016-02-24 Updated the schematic a bit. Removed I2C line to payload and sense pin
    [sputnik_prototype.brd, sputnik_prototype.sch]
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2016-02-26 Fixed some stuff on schematic
    [sputnik_prototype.brd, sputnik_prototype.sch]
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2016-02-27 trying to track down spi bug, compiles right now but not behaving as it should be
2016-02-27 fixed bug in spi driver, commented out stuff in c3 in an attempt to get back to a working state
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2016-02-28 Added GPIOs and other updates on SysCon sch. Updated SPI cache footprint
    [sputnik_prototype_RadioCom.brd, sputnik_prototype_RadioCom.sch, sputnik_prototype_SysController.brd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]
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2016-02-29 Fixed to do list
    [sputnik_prototype_SysController.sch]
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2016-03-03 added attributes to several parts, started organizing the board to prep for layout
    [sputnik_prototype_RadioCom.brd, sputnik_prototype_RadioCom.sch]
2016-03-03 added attributes, replaced atmega footprint with correct version, replaced resonator with xtal
    [sputnik_prototype_SysController.brd, sputnik_prototype_SysController.sch]
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2016-03-04 threw configure_transceiver back into c3, seems to be working, fixed transceiver driver bugs
2016-03-04 Got rid of SysCon LDO, fixed Optoisolator symbol
    [sputnik_prototype_SysController.brd, sputnik_prototype_SysController.sch]
2016-03-05 Fixed OIs, fixed SysCon LDO, replaced SPI cache
    [sputnik_prototype_RadioCom.brd, sputnik_prototype_RadioCom.sch, sputnik_prototype_SysController.brd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]
2016-03-05 Had to fix to do again because I'm a dumbass
    [sputnik_prototype_SysController.sch]
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2016-03-09 updated info in procedure and materials, corrected mistake on graph
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2016-03-18 fixed symbols
    [sputnik_prototype_RadioCom.brd, sputnik_prototype_RadioCom.sch]
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2016-03-19 Added the diodes and fixed the Crystal
    [sputnik_prototype_SysController.sch]
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2016-03-19 Lots of OCD cleanup on schematic, bringing up to PSAS standards. Fixed lack of bypass cap on SPI flash, changed SPI flash KW0x pins to SPI1 which weren't before (?), removed DIO1 and DIO0 from GPIO b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
    [sputnik_prototype_RadioCom.brd, sputnik_prototype_RadioCom.sch]
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2016-03-21 Fixed 22x2pinout, added PWR LEDs, fixed some NC issues
    [sputnik_prototype_RadioCom.brd, sputnik_prototype_RadioCom.sch]
2016-03-21 Added more LEDs, filled in LNA values except one inductor which I still need to figure out
    [sputnik_prototype_RadioCom.brd, sputnik_prototype_RadioCom.sch]
2016-03-22 Added RESET (RF) line to PTE2 GPIO. Waiting on LNA component values from MAACOM.
    [sputnik_prototype_RadioCom.brd, sputnik_prototype_RadioCom.sch]
2016-03-22 OCD fixes on SPI flash. Made single nets on GPIO that aren't connected. Made new connectors for OreSat connector and RF connector and added them. Updates to a library part for the outline. Made it 4 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
    [sputnik_prototype_RadioCom.brd, sputnik_prototype_RadioCom.sch]
2016-03-22 Uhh.... I did stuff? Fixed something? I can't remember. Found another NC on the KW0x.
    [sputnik_prototype_RadioCom.brd, sputnik_prototype_RadioCom.sch]
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2016-03-23 Clean up on system controller board. Added 40 pin connector, board outline, ground planes. Killed all old spurious signals. Removed unecessary connectors. Still need to find small power controllers t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
    [sputnik_prototype_SysController.brd, sputnik_prototype_SysController.sch]
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2016-03-24 Board update. Curious now about the AC blocking network on the RFInput side. I'm not sure how you can use the RF switch without breaking the ground plane?
    [sputnik_prototype_RadioCom.brd]
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2016-03-25 Organized LED locations, test points, need to talk to Glenn about crossing RF paths because the switch inputs are reverse of the RFIO and PA_BOOST outputs.
    [sputnik_prototype_RadioCom.brd]
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2016-03-26 Poor Jake. It's like there's some crazy guy screwing with him every time he commits... oh, wait. Huh. Anyway. Updated board outline with keepouts. Moved connectors into position and locked. Added shi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
    [sputnik_prototype_RadioCom.brd, sputnik_prototype_RadioCom.sch]
2016-03-26 Yep, that was a good idea. I added the other shield. And experimented with other layouts. Still needs a ton of work, but now it's going to be OK. OH CRAP the RXTX switch might have be wired the other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
    [sputnik_prototype_RadioCom.brd, sputnik_prototype_RadioCom.sch]
2016-03-26 Attached bypass caps, made some connections between LDO and SPI cache components
    [sputnik_prototype_RadioCom.brd]
2016-03-28 Newest outline of SC board, added secondary connector because we're going to need it for the output.
    [sputnik_prototype_SysController.brd, sputnik_prototype_SysController.sch]
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2016-03-30 Fixed symbol pins and locations
    [sputnik_prototype_RadioCom.brd, sputnik_prototype_RadioCom.sch]
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2016-04-02 Added datasheets for ferrite bead and inverter. Made inverter and ferrite footprints and symbols and added them to the board/schematic. Fixed RF GND issue except for the KW0x pins. Added all bypass c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
    [sputnik_prototype_RadioCom.brd, sputnik_prototype_RadioCom.sch]
2016-04-02 Moved power plane from under the RF portion of the board. Changed RF trace width to calculated 0.343mm.
    [sputnik_prototype_RadioCom.brd]
2016-04-02 Fixed some overlapping lines, added RF_GND traces to GND_PA1 & GND_PA2 on the KW0x
    [sputnik_prototype_RadioCom.brd, sputnik_prototype_RadioCom.sch]
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2016-04-02 Finished placing test points, finished all unrouted airwires, got rid of all drill clearance errors. There are DRC errors of some of the polygons and other areas I'm not sure about.
    [sputnik_prototype_RadioCom.brd, sputnik_prototype_RadioCom.sch]
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

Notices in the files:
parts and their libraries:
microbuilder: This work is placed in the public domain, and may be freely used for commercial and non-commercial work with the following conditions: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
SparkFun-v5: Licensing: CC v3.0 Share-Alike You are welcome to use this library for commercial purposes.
